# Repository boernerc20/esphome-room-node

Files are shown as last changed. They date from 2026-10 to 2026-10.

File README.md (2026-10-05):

# Jarvis Room Node

An ESP32-S3 voice assistant and room sensor for [Home Assistant](https://www.home-assistant.io/),
built on [ESPHome](https://esphome.io/). Wake word ("hey jarvis") on the device, temperature
and humidity, e-ink display, LED status ring.

**Status:** breadboard works end to end. Next: rev A PCB in KiCad.

## Repo

| Path | What |
|---|---|
| [`room-node.yaml`](room-node.yaml) | ESPHome firmware (breadboard pins) |
| [`docs/breadboard.md`](docs/breadboard.md) | Breadboard wiring |
| [`docs/pcb/pinout.md`](docs/pcb/pinout.md) | Rev A PCB pinout |
| [`docs/pcb/schematic.md`](docs/pcb/schematic.md) | Rev A schematic, sheet by sheet — draw from this |
| [`docs/pcb/layout.md`](docs/pcb/layout.md) | Rev A board (placed + routed), assembly and bring-up |
| [`docs/enclosure.md`](docs/enclosure.md) | Enclosure notes |
| `kicad/room-node/` | KiCad project |
| `reports/bom/rev-a-bom-lcsc.csv` | Rev A BOM with LCSC numbers |
| `models/` | Wake word model |

## Flash

1. Copy `secrets.yaml.example` to `secrets.yaml` and fill it in. Git ignores it.
2. `esphome run room-node.yaml` — USB the first time, then OTA (192.168.1.50).
3. Home Assistant finds the node. Assign an Assist pipeline under **Settings → Voice assistants**.

Built by [Chris Boerner](https://boernerc20.me).

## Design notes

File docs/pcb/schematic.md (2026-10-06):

# Rev A schematic — draw from this

One section per KiCad sheet in `kicad/room-node/`. Each section lists the parts and
every connection. Use the net names as global labels. Pin map: [`pinout.md`](pinout.md).
Part numbers and LCSC: [`../../reports/bom/rev-a-bom-lcsc.csv`](../../reports/bom/rev-a-bom-lcsc.csv).

**Status (2026-10-01, SQU-27):** all 6 sheets are drawn from this doc and included in
the root sheet `room-node.kicad_sch`. Project ERC: 0 errors, 1 explained warning
([`reports/schematic/`](../../reports/schematic/)). The netlist matches `pinout.md`
(`python3 tools/check_pinout.py`). The earlier MCU sheet (2xx refs, wiring errors) was
redrawn from scratch. Chris reviews and tidies.

**2026-10-02 (SQU-29):** status LED D1 + R12 on GPIO2 added to the MCU sheet.

**2026-10-05 (SQU-17):** voice button SW3 + R5 removed (wake word only). U1 pin 31
(GPIO38) is now not connected.

**Refs:** the schematic uses the refs in this doc (R1, C1, U1 …). Net names are the
ones in this doc (`+3V3`, `EN`).

**Rules for all sheets**
- Passives are 0603 minimum (hand assembly). No 0402.
- Every IC gets 0.1 µF at its supply pin.
- Board: 4 layers, solid ground plane. Assembly and layout rules: [`layout.md`](layout.md).

## Block diagram

```
USB-C 5V ──┬── ESD (D+/D−) ─────────────── U1 USB (GPIO19/20)
           ├── CC1/CC2 → 2×100k → CC_SENSE → GPIO1
           │
           +5V ──┬── LDO U2 → +3V3 ──┬── U1 ESP32-S3 module
                 │                   ├── MK1 mic (I2S in)
                 │                   ├── U6 AHT20 (I2C)
                 │                   └── J3 e-paper (SPI)
                 ├── U3 MAX98357A (I2S out) → J2 speaker
                 └── J4 LED strip (DIN ← GPIO21 via 470 Ω)

U1 GPIO2 → R12 1 kΩ → D1 status LED (green) → GND
```

---

## Sheet 1 — MCU + power + USB (`mcu.kicad_sch`)

| Ref | Value | Symbol | Footprint |
|---|---|---|---|
| U1 | ESP32-S3-WROOM-1-N16R8 | `RF_Module:ESP32-S3-WROOM-1` (set Value to N16R8) | `RF_Module:ESP32-S3-WROOM-1` |
| U2 | AP7361C-33ER-13 | `Regulator_Linear:AP1117-33` (same pinout) | `Package_TO_SOT_SMD:SOT-223-3_TabPin2` |
| U5 | USBLC6-2SC6 | `Power_Protection:USBLC6-2SC6` | `Package_TO_SOT_SMD:SOT-23-6` |
| J1 | USB4085-GF-A | `Connector:USB_C_Receptacle_USB2.0_16P` | `Connector_USB:USB_C_Receptacle_GCT_USB4085` |
| R1, R2 | 5.1 kΩ 1% | `Device:R` | 0603 |
| R3, R4 | 10 kΩ | `Device:R` | 0603 |
| R6, R7 | 100 kΩ 1% | `Device:R` | 0603 |
| C1 | 10 µF 16 V | `Device:C` | 0805 |
| C2, C5, C7, C9 | 0.1 µF | `Device:C` | 0603 |
| C3, C8 | 1 µF | `Device:C` | 0603 |
| C4, C6 | 22 µF 10 V | `Device:C` | 0805 |
| SW1, SW2 | TL3342 (RESET, BOOT) | `Switch:SW_Push` | `Button_Switch_SMD:SW_SPST_TL3342` |
| TP1–TP8 | test pad | `Connector:TestPoint` | `TestPoint:TestPoint_Pad_D1.5mm` |
| R12 | 1 kΩ | `Device:R` | 0603 |
| D1 | KT-0805G green LED | `Device:LED` | `LED_SMD:LED_0805_2012Metric` |

**USB-C (J1)**
- VBUS A4, B4, A9, B9 → `+5V`. C1 10 µF + C2 0.1 µF to GND at J1.
- GND A1, B1, A12, B12 and shield → `GND`.
- CC1 A5 → R1 5.1 kΩ → GND, and → R6 100 kΩ → `CC_SENSE`.
- CC2 B5 → R2 5.1 kΩ → GND, and → R7 100 kΩ → `CC_SENSE`.
- D+ A6 + B6 → `USB_D+_CONN`. D− A7 + B7 → `USB_D-_CONN`.
- SBU1 A8, SBU2 B8 → no connect.

**ESD (U5, USBLC6-2SC6)** — pinout checked against ST datasheet. Place at J1.

| U5 pin | Net |
|---|---|
| 1 | `USB_D-_CONN` |
| 2 | `GND` |
| 3 | `USB_D+_CONN` |
| 4 | `USB_D+` → U1 pin 14 |
| 5 | `+5V` |
| 6 | `USB_D-` → U1 pin 13 |

**CC sense** — `CC_SENSE` → U1 pin 39 (GPIO1). C9 0.1 µF to GND at U1. TP8 on the net.
R6/R7 near J1. Firmware reads the USB source current from it (about 0.2 V = 500 mA
port, 0.46 V = 1.5 A, 0.84 V = 3 A) and limits LED brightness.

**LDO (U2)** — pin 3 VIN ← `+5V`, C3 1 µF. Pin 1 → GND. Pin 2 + tab → `+3V3`,
C4 22 µF + C5 0.1 µF. Buy the **-33ER** suffix only (other suffixes have a different
pinout). Give the tab a copper pour (heat).

**Module (U1)** — pin 2 ← `+3V3`, C6 22 µF + C7 0.1 µF at the pin. Pins 1, 40, 41 → GND.
Other pins: see [`pinout.md`](pinout.md).

**Reset and boot buttons**
```
 +3V3        +3V3
  R3 10k      R4 10k
  ├─ EN       ├─ IO0
  C8 1µF      SW2 BOOT
  SW1 RESET   │
  GND         GND
```
EN = pin 3, IO0 = pin 27. SW1 and C8 both go from EN to GND. No voice button: wake
word only. Pin 31 (GPIO38) has a no-connect flag.

**Status LED (D1)** — U1 pin 38 (GPIO2) → `STATUS_LED` → R12 1 kΩ → D1 anode (pin 2);
D1 cathode (pin 1) → GND. HIGH = on.
- GPIO2 is not a strapping pin on the S3 (straps: GPIO0, 3, 45, 46). It is an input
  with no pull at reset, so D1 is off until firmware drives it.
- Current: (3.3 V − Vf) / 1 kΩ. Vf is about 2.4 V at 1 mA (typical curve) and up to
  about 2.8 V for the highest Vf bin, so **0.5–0.9 mA**. The ESP32-S3 GPIO is good for
  tens of mA, so this is no load. At 1 mA the LED gives roughly a tenth of its 20 mA
  brightness, which is plenty for an indicator in a bedroom. Firmware can dim it further with PWM (LEDC).
- **Why 0805, not 0603:** JLC has no green or blue 0603 LED in its Basic library
  (checked 2026-10-02: only red C2286 and white C2290 at 0603). KT-0805G (C2297) is the
  green Basic part. 0805 is easier to hand-solder. If you want 0603, use KT-0603G
  (C12624, Extended) and change the footprint to `LED_SMD:LED_0603_1608Metric`.
- **Polarity:** the KENTO datasheet numbers the anode pad ① ("+"); KiCad numbers the
  cathode pad 1. Do not go by pad numbers. The green corner mark on the LED is the
  cathode: place it on the cathode (pad 1) side of the footprint.
- Put D1 where it can be seen through the case (a light pipe or a thin wall).
  It is not near the antenna and not near U6.

**Test points:** TP1 EN, TP2 IO0, TP3 TXD0 (pin 37), TP4 RXD0 (pin 36), TP5 +3V3,
TP6 +5V, TP7 GND, TP8 CC_SENSE.

---

## Sheet 2 — Audio out (`audio_out.kicad_sch`)

| Ref | Value | Symbol | Footprint |
|---|---|---|---|
| U3 | MAX98357AETE+ | `Audio:MAX98357A` | `Package_DFN_QFN:TQFN-16-1EP_3x3mm_P0.5mm_EP1.23x1.23mm` |
| C20 | 470–1000 µF 16 V radial | `Device:C_Polarized` | radial THT (see BOM) |
| C21 | 0.1 µF | `Device:C` | 0603 |
| C22 | 10 µF 16 V | `Device:C` | 0805 |
| R20 | 100 kΩ | `Device:R` | 0603 |
| J2 | JST-PH 2-pin | `Connector_Generic:Conn_01x02` | `Connector_JST:JST_PH_B2B-PH-SM4-TB_1x02-1MP_P2.00mm_Vertical` |

| U3 pin | Name | Net |
|---|---|---|
| 1 | DIN | `I2S_SPK_DIN` (GPIO18) |
| 2 | GAIN_SLOT | `+5V` → **6 dB gain** (tested on the breadboard; 9 dB clips) |
| 4 | SD_MODE | `AMP_SD` (GPIO7). R20 100 kΩ to GND keeps the amp off during boot (the chip also has an internal 100 kΩ pull-down). GPIO HIGH = left channel |
| 7, 8 | VDD | `+5V`. C20, C21, C22 to GND, **at the chip** |
| 9 | OUTP | J2 pin 1 |
| 10 | OUTN | J2 pin 2 |
| 14 | LRCLK | `I2S_SPK_LRCLK` (GPIO16) |
| 16 | BCLK | `I2S_SPK_BCLK` (GPIO17) |
| 3, 11, 15, 17 (EP) | GND | `GND`. EP is pin 17 (`PAD`) on the stock symbol; it is not connected inside the chip, so wire it. Vias in the pad |
| 5, 6, 12, 13 | NC | no connect |

Speaker: Dayton CE32A-8 (8 Ω) on J2. Do not connect either speaker wire to GND.
C20 + C21 + the star ground removed the breadboard crackle. Keep all three.

---

## Sheet 3 — Microphone (`microphone.kicad_sch`)

Use the **stock** symbol `Sensor_Audio:SPH0645LM4H` and footprint
`Sensor_Audio:Knowles_SPH0645LM4H-6_3.5x2.65mm`. The SPH0645 that was in the project
library (wrong pin numbers, no sound hole) was removed in SQU-27.

| Ref | Value | Footprint |
|---|---|---|
| MK1 | SPH0645LM4H-B | stock (above) |
| R8 | 100 kΩ | 0603 |
| R9, R10, R11 | 33 Ω | 0603 |
| C10 | 0.1 µF | 0603 |
| C11 | 100 pF C0G, **DNP** (do not fit) | 0603 |

| MK1 pin | Name | Connection |
|---|---|---|
| 1 | WS | → R10 33 Ω → `I2S_MIC_WS` (GPIO5). R10 at U1 |
| 2 | SELECT | GND (left channel) |
| 3 | GND | GND (ring around the sound hole) |
| 4 | BCLK | → R9 33 Ω → `I2S_MIC_BCLK` (GPIO4). R9 at U1 |
| 5 | VDD | `+3V3`. C10 0.1 µF + C11 100 pF to GND, at the pin |
| 6 | DATA | → R11 33 Ω → `I2S_MIC_DATA` (GPIO6). R11 at MK1. R8 100 kΩ from `I2S_MIC_DATA` to GND |

The 33 Ω parts are optional damping. If you remove them, use 0 Ω or a wire.
Mic mute is software only. There is no mute switch.

---

## Sheet 4 — LED ring (`led_ring.kicad_sch`)

| Ref | Value | Footprint |
|---|---|---|
| R30 | 470 Ω | 0603 |
| C30 | 1000 µF 16 V radial | radial THT (see BOM) |
| J4 | 3-pin connector to the strip | `Connector_JST:JST_XH_S3B-XH-A_1x03_P2.50mm_Horizontal`: JST S3B-XH-A(LF)(SN), side entry, LCSC C157928 (3 A; full white is ~1.6 A). Side entry since SQU-42: the cable leaves flat out of the bottom edge |

- `LED_DIN` (GPIO21) → R30 470 Ω → J4 pin 2 (DIN). R30 near U1.
- J4 pin 1 → `+5V`. J4 pin 3 → `GND`. C30 across pins 1 and 3, at J4.
- No level shifter (works on the breadboard). If the strip flickers on rev A, rev B adds a 74AHCT125.
- Strip: 27 × WS2812B, off-board.

---

## Sheet 5 — Sensor (`sensors.kicad_sch`)

| Ref | Value | Footprint |
|---|---|---|
| U6 | AHT20 | `room-node:AHT20`, 3 × 3 mm DFN-6, 1.0 mm pitch (LCSC C2757850) |
| R40, R41 | 4.7 kΩ | 0603 |
| C40 | 0.1 µF | 0603 |

The project-library AHT20 was wrong (4 pins, 4 invented pads). It is now replaced
(SQU-27) with a 6-pin symbol and a 6-pad footprint made from the LCSC C2757850 import,
pin 1 top-left as in the Aosong datasheet v1.1 §3. Pins 1 and 6 are no-connect pins.

| U6 pin | Name | Net |
|---|---|---|
| 1 | NC | no connect |
| 2 | VDD | `+3V3`, C40 0.1 µF to GND at the pin |
| 3 | SCL | `I2C_SCL` (GPIO9), R41 4.7 kΩ to `+3V3` |
| 4 | SDA | `I2C_SDA` (GPIO8), R40 4.7 kΩ to `+3V3` |
| 5 | GND | `GND` |
| 6 | NC | no connect |

- I2C address 0x38.
- Source: Aosong AHT20 datasheet v1.1, §3 pin diagram (top view).
- Place U6 on a board edge, far from U1, U2, U3 and J4, with slots on three sides
  (heat from the board reads as room temperature).

---

## Sheet 6 — Display (`display.kicad_sch`)

Rev A plugs in the same Waveshare 2.9" e-paper module as the breadboard, with its
own driver board, through its cable. (A bare panel on an FPC needs an extra boost
circuit; not for rev A.)

| Ref | Value | Footprint |
|---|---|---|
| J3 | 8-pin JST-PH **side entry** (Waveshare cable) | `Connector_JST:JST_PH_S8B-PH-SM4-TB_1x08-1MP_P2.00mm_Horizontal` |
| C50 | 0.1 µF | 0603 |

| J3 pin | Waveshare name | Net |
|---|---|---|
| 1 | VCC | `+3V3` (C50 to GND at J3) |
| 2 | GND | `GND` |
| 3 | DIN | `EPD_MOSI` (GPIO11) |
| 4 | CLK | `EPD_CLK` (GPIO12) |
| 5 | CS | `EPD_CS` (GPIO10) |
| 6 | DC | `EPD_DC` (GPIO13) |
| 7 | RST | `EPD_RST` (GPIO14) |
| 8 | BUSY | `EPD_BUSY` (GPIO15) |

**Side entry (Chris, 2026-10-05, SQU-32).** J3 is the horizontal **S8B-PH-SM4-TB**, not the
top-entry B8B. The board sits on ~10 mm M2 standoffs behind the display, parts side facing
away from it, so the cable has to leave the board edge towards the display. Pinout and pin
numbering are unchanged: pin 1 is still pin 1.

**Edge (Chris, 2026-10-05, SQU-35).** The connector mouth faces out over the **right**
board edge (looking at the parts side with USB-C on the left), not the bottom edge. Pin 1
is the **lower** of the eight pads and is marked with a filled triangle on the silkscreen.
The LED connector J4 moved to the left edge just below USB-C at the same time; see
`docs/pcb/layout.md`.

⚠ Check the pin order and pin count on your cable. Newer Waveshare modules have a
9th pin (PWR); if yours has it, use a 9-pin connector and tie PWR to `+3V3`.

⚠ **Cable.** The breadboard cable has a PH plug only at the module end; the other end
is loose jumper wires. For J3 as drawn you need a PH-to-PH 8-pin cable that maps
pin 1 to pin 1 (some ready-made cables reverse it: beep it out before power-on).
The other option is a 1×8 2.54 mm pin header (`Connector_PinHeader_2.54mm:PinHeader_1x08_P2.54mm_Vertical`)
that takes the existing jumper ends. Same pin order either way.

---

## Global labels (checklist)

- [ ] `+5V`, `+3V3`, `GND`
- [ ] `USB_D+`, `USB_D-`, `USB_D+_CONN`, `USB_D-_CONN`, `CC1`, `CC2`, `CC_SENSE`
- [ ] `EN`, `IO0`, `TXD0`, `RXD0`, `STATUS_LED`
- [ ] `I2S_MIC_BCLK`, `I2S_MIC_WS`, `I2S_MIC_DATA`
- [ ] `I2S_SPK_BCLK`, `I2S_SPK_LRCLK`, `I2S_SPK_DIN`, `AMP_SD`
- [ ] `I2C_SDA`, `I2C_SCL`
- [ ] `EPD_CLK`, `EPD_MOSI`, `EPD_CS`, `EPD_DC`, `EPD_RST`, `EPD_BUSY`
- [ ] `LED_DIN`

## Datasheets

ESP32-S3-WROOM-1 and ESP32-S3 Hardware Design Guidelines (Espressif), AP7361C (Diodes),
USBLC6-2 (ST), MAX98357A (Analog Devices), SPH0645LM4H-B (Knowles, DigiKey mirror),
AHT20 (Aosong), KT-0805G LED (Hubei KENTO, rev A.0, 2018-12-06), USB Type-C spec R2.0 §4.11.3 (CC voltages).

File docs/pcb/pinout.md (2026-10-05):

# Rev A pinout — ESP32-S3-WROOM-1-N16R8 (U1)

One row per module pin. **Pin** = module pin number on the KiCad symbol
`RF_Module:ESP32-S3-WROOM-1` (verified). **GPIO** = the ESP32 GPIO number. They are
two different numbers; always check which one you read.

The breadboard uses the same GPIOs (see [`../breadboard.md`](../breadboard.md)).
The PCB has no voice button (wake word only); the BOOT button on GPIO0 can still
start the voice assistant, same as on the breadboard.

## Used pins

| Pin | GPIO | Net (global label) | Goes to | Sheet |
|---|---|---|---|---|
| 1, 40, 41 | — | `GND` | ground plane, via array under the pad | MCU |
| 2 | — | `+3V3` | LDO output | MCU |
| 3 | EN | `EN` | 10 kΩ pull-up, 1 µF to GND, RESET button | MCU |
| 4 | 4 | `I2S_MIC_BCLK` | mic BCLK (through 33 Ω) | Mic |
| 5 | 5 | `I2S_MIC_WS` | mic WS (through 33 Ω) | Mic |
| 6 | 6 | `I2S_MIC_DATA` | mic DATA (through 33 Ω), 100 kΩ to GND | Mic |
| 7 | 7 | `AMP_SD` | amp SD_MODE. HIGH = on, LOW = off | Audio |
| 8 | 15 | `EPD_BUSY` | e-paper BUSY (input) | Display |
| 9 | 16 | `I2S_SPK_LRCLK` | amp LRCLK | Audio |
| 10 | 17 | `I2S_SPK_BCLK` | amp BCLK | Audio |
| 11 | 18 | `I2S_SPK_DIN` | amp DIN | Audio |
| 12 | 8 | `I2C_SDA` | AHT20 SDA, 4.7 kΩ pull-up | Sensor |
| 13 | 19 | `USB_D-` | USB-C D− (through ESD U5) | MCU |
| 14 | 20 | `USB_D+` | USB-C D+ (through ESD U5) | MCU |
| 17 | 9 | `I2C_SCL` | AHT20 SCL, 4.7 kΩ pull-up | Sensor |
| 18 | 10 | `EPD_CS` | e-paper CS | Display |
| 19 | 11 | `EPD_MOSI` | e-paper DIN | Display |
| 20 | 12 | `EPD_CLK` | e-paper CLK | Display |
| 21 | 13 | `EPD_DC` | e-paper DC | Display |
| 22 | 14 | `EPD_RST` | e-paper RST | Display |
| 23 | 21 | `LED_DIN` | LED strip DIN (through 470 Ω) | LED |
| 27 | 0 | `IO0` | BOOT button, 10 kΩ pull-up. ⚠ strapping pin | MCU |
| 36 | 44 (RXD0) | `RXD0` | test point | MCU |
| 37 | 43 (TXD0) | `TXD0` | test point | MCU |
| 38 | 2 | `STATUS_LED` | status LED D1 through R12 1 kΩ. HIGH = on | MCU |
| 39 | 1 | `CC_SENSE` | USB-C CC sense (analog, ADC1_CH0) | MCU |

## Do not use

| Pin | GPIO | Why |
|---|---|---|
| 15, 16, 26 | 3, 46, 45 | Strapping pins. Leave not connected. |
| 28, 29, 30 | 35, 36, 37 | Used inside the module by the octal PSRAM. |
| — | 26–32 | Flash. Not on the module pins. |

## Free (spare)

| Pin | GPIO | Note |
|---|---|---|
| 31 | 38 | Was the voice button (removed 2026-10-05, wake word only). |
| 32–35 | 39–42 | JTAG. Keep free if you want hardware debug. |
| 24, 25 | 47, 48 | No ADC. |

Leave free pins not connected. There is no free ADC1 pin left (GPIO1 = CC sense,
GPIO2 = status LED).

## Why GPIO2 for the status LED

GPIO2 is not a strapping pin on the ESP32-S3 (the straps are GPIO0, 3, 45 and 46;
ESP32-S3 datasheet, "Strapping Pins"). It is an input with no pull at reset, so the
LED stays off until firmware drives it. (On the older ESP32, GPIO2 *is* a strap; not
on the S3.) The LED takes about 0.5–0.9 mA, far below the GPIO drive limit. The cost:
GPIO2 was the last free ADC1 pin.

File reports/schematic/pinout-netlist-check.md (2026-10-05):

## 1. U1 used pins (pinout.md) vs netlist

| U1 pin | GPIO | pinout.md net | netlist net | Also on this net | OK |
|---|---|---|---|---|---|
| 1 | — | `GND` | `GND` | 41 pins | ✅ |
| 2 | — | `+3V3` | `+3V3` | 17 pins | ✅ |
| 3 | EN | `EN` | `EN` | C8.1, R3.2, SW1.2, TP1.1 | ✅ |
| 4 | 4 | `I2S_MIC_BCLK` | `I2S_MIC_BCLK` | R9.2 | ✅ |
| 5 | 5 | `I2S_MIC_WS` | `I2S_MIC_WS` | R10.2 | ✅ |
| 6 | 6 | `I2S_MIC_DATA` | `I2S_MIC_DATA` | R11.2, R8.1 | ✅ |
| 7 | 7 | `AMP_SD` | `AMP_SD` | R20.1, U3.4 | ✅ |
| 8 | 15 | `EPD_BUSY` | `EPD_BUSY` | J3.8 | ✅ |
| 9 | 16 | `I2S_SPK_LRCLK` | `I2S_SPK_LRCLK` | U3.14 | ✅ |
| 10 | 17 | `I2S_SPK_BCLK` | `I2S_SPK_BCLK` | U3.16 | ✅ |
| 11 | 18 | `I2S_SPK_DIN` | `I2S_SPK_DIN` | U3.1 | ✅ |
| 12 | 8 | `I2C_SDA` | `I2C_SDA` | R40.2, U6.4 | ✅ |
| 13 | 19 | `USB_D-` | `USB_D-` | U5.6 | ✅ |
| 14 | 20 | `USB_D+` | `USB_D+` | U5.4 | ✅ |
| 17 | 9 | `I2C_SCL` | `I2C_SCL` | R41.2, U6.3 | ✅ |
| 18 | 10 | `EPD_CS` | `EPD_CS` | J3.5 | ✅ |
| 19 | 11 | `EPD_MOSI` | `EPD_MOSI` | J3.3 | ✅ |
| 20 | 12 | `EPD_CLK` | `EPD_CLK` | J3.4 | ✅ |
| 21 | 13 | `EPD_DC` | `EPD_DC` | J3.6 | ✅ |
| 22 | 14 | `EPD_RST` | `EPD_RST` | J3.7 | ✅ |
| 23 | 21 | `LED_DIN` | `LED_DIN` | R30.1 | ✅ |
| 27 | 0 | `IO0` | `IO0` | R4.2, SW2.2, TP2.1 | ✅ |
| 36 | 44 (RXD0) | `RXD0` | `RXD0` | TP4.1 | ✅ |
| 37 | 43 (TXD0) | `TXD0` | `TXD0` | TP3.1 | ✅ |
| 38 | 2 | `STATUS_LED` | `STATUS_LED` | R12.1 | ✅ |
| 39 | 1 | `CC_SENSE` | `CC_SENSE` | C9.1, R6.2, R7.2, TP8.1 | ✅ |
| 40 | — | `GND` | `GND` | 41 pins | ✅ |
| 41 | — | `GND` | `GND` | 41 pins | ✅ |

## 2. U1 pins that must stay not connected

| U1 pin | GPIO | Why | Netlist | OK |
|---|---|---|---|---|
| 15 | 3 | Do not use | not connected | ✅ |
| 16 | 46 | Do not use | not connected | ✅ |
| 24 | 47 | Free (spare) | not connected | ✅ |
| 25 | 48 | Free (spare) | not connected | ✅ |
| 26 | 45 | Do not use | not connected | ✅ |
| 28 | 35 | Do not use | not connected | ✅ |
| 29 | 36 | Do not use | not connected | ✅ |
| 30 | 37 | Do not use | not connected | ✅ |
| 31 | 38 | Free (spare) | not connected | ✅ |
| 32 | 39 | Free (spare) | not connected | ✅ |
| 33 | 40 | Free (spare) | not connected | ✅ |
| 34 | 41 | Free (spare) | not connected | ✅ |
| 35 | 42 | Free (spare) | not connected | ✅ |

**U1 pins connected but not in pinout.md:** none

## 3. Other end of each net (schematic.md)

| Net | Expected pins | Result |
|---|---|---|
| `EN` | U1.3, R3.2, C8.1, SW1.2, TP1.1 | ✅ |
| `IO0` | U1.27, R4.2, SW2.2, TP2.1 | ✅ |
| `TXD0` | U1.37, TP3.1 | ✅ |
| `RXD0` | U1.36, TP4.1 | ✅ |
| `CC1` | J1.A5, R1.1, R6.1 | ✅ |
| `CC2` | J1.B5, R2.1, R7.1 | ✅ |
| `CC_SENSE` | U1.39, R6.2, R7.2, C9.1, TP8.1 | ✅ |
| `USB_D+_CONN` | J1.A6, J1.B6, U5.3 | ✅ |
| `USB_D-_CONN` | J1.A7, J1.B7, U5.1 | ✅ |
| `USB_D+` | U1.14, U5.4 | ✅ |
| `USB_D-` | U1.13, U5.6 | ✅ |
| `I2S_MIC_BCLK` | U1.4, R9.2 | ✅ |
| `I2S_MIC_WS` | U1.5, R10.2 | ✅ |
| `I2S_MIC_DATA` | U1.6, R11.2, R8.1 | ✅ |
| `I2S_SPK_LRCLK` | U1.9, U3.14 | ✅ |
| `I2S_SPK_BCLK` | U1.10, U3.16 | ✅ |
| `I2S_SPK_DIN` | U1.11, U3.1 | ✅ |
| `AMP_SD` | U1.7, U3.4, R20.1 | ✅ |
| `I2C_SDA` | U1.12, U6.4, R40.2 | ✅ |
| `I2C_SCL` | U1.17, U6.3, R41.2 | ✅ |
| `EPD_CS` | U1.18, J3.5 | ✅ |
| `EPD_MOSI` | U1.19, J3.3 | ✅ |
| `EPD_CLK` | U1.20, J3.4 | ✅ |
| `EPD_DC` | U1.21, J3.6 | ✅ |
| `EPD_RST` | U1.22, J3.7 | ✅ |
| `EPD_BUSY` | U1.8, J3.8 | ✅ |
| `LED_DIN` | U1.23, R30.1 | ✅ |
| `STATUS_LED` | U1.38, R12.1 | ✅ |
| `+5V` | 18 pins | ✅ |
| `+3V3` | 18 pins | ✅ |
| `GND` | 29 pins | ✅ |
| (series) | MK1.1 = R10.1 | ✅ |
| (series) | MK1.4 = R9.1 | ✅ |
| (series) | MK1.6 = R11.1 | ✅ |
| (series) | R30.2 = J4.2 | ✅ |
| (series) | R12.2 = D1.2 | ✅ |
| (series) | U3.9 = J2.1 | ✅ |
| (series) | U3.10 = J2.2 | ✅ |
| (NC) | J1.A8 | ✅ |
| (NC) | J1.B8 | ✅ |
| (NC) | U6.1 | ✅ |
| (NC) | U6.6 | ✅ |
| (NC) | U3.5 | ✅ |
| (NC) | U3.6 | ✅ |
| (NC) | U3.12 | ✅ |
| (NC) | U3.13 | ✅ |

**Result: PASS**

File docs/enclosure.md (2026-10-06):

# Enclosure notes (3D print)

- **Display window:** cut to the active area, 66.9 × 29.1 mm (module is 89.5 × 38 × 4.7 mm).
- **LED ring:** 27 px around the display. Cover with a translucent diffuser (PETG, 1.5–2 mm wall).
- **Speaker (Dayton CE32A-8):** cutout 31.5 mm, frame 32 mm, depth 14.5 mm.
  Sealed back chamber of 20–30 cc with some poly stuffing. Seal the cone to the front wall.
- **Mic (PCB):** bottom port. Bring a sealed path (gasket or foam ring) from a case
  opening to the hole under the mic on the **bottom** of the PCB.
- **Isolation:** keep the mic away from the speaker, with foam between them. There is no
  echo cancellation, so speaker sound in the mic can trigger the wake word.
- **Sensor:** put a vent above the AHT20, away from warm parts.
- **Cable exits (rev A board at dc89150, 2026-10-06).** Looking at the parts side with USB-C on the left:
  - **Left edge:** USB-C (J1) needs its own opening.
  - **Bottom edge:** the LED strip connector (J4, side-entry JST S3B-XH-A) faces
    outward. Provide a nominal 10 mm wide slot in the bottom wall, centred on
    PCB x = 126.5 mm (J4 pin 2). The housing spans x = 121.5–131.5 mm and its
    front face is at y = 137.7 mm, 0.3 mm inside the PCB edge (y = 138.0 mm).
    The mating plug and cable extend beyond that edge. **Open question:** final
    slot height, wall clearance and cable bend space need a physical fit check.
  - **Right edge:** the display cable (J3, side entry, mouth flush with the edge). It
    runs straight out of the right edge into the gap behind the display.
  - **Bottom-right:** the speaker plug (J2, vertical, cable exits upward).
  - The mic opening stays at the **bottom-left** corner; J4's courtyard is 12.5 mm
    to its right.
  - The antenna still overhangs the **top** edge by about 6 mm: no metal in front of it.

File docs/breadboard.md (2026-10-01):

# Breadboard wiring (as built, confirmed 2026-09-30)

Pins match [`../room-node.yaml`](../room-node.yaml). Power: 5 V USB into the dev board.

| Part | Wiring |
|---|---|
| ESP32-S3 dev board, N16R8 | 5 V USB in |
| Adafruit SPH0645 breakout (mic) | BCLK→GPIO4, LRCL→GPIO5, DOUT→GPIO6, SEL→GND, 3V→3V3 |
| MAX98357A breakout (amp) | BCLK→GPIO17, LRC→GPIO16, DIN→GPIO18, SD→GPIO7, GAIN→VIN (6 dB), VIN→5V. 470–1000 µF + 0.1 µF across VIN/GND at the amp |
| Dayton CE32A-8 speaker | amp + and −. Do not ground either wire |
| AHT20 breakout | SDA→GPIO8, SCL→GPIO9, VCC→3V3 (breakout has pull-ups) |
| Waveshare 2.9" e-paper v2 | CLK→GPIO12, DIN→GPIO11, CS→GPIO10, DC→GPIO13, RST→GPIO14, BUSY→GPIO15, VCC→3V3 |
| WS2812B strip, 27 px | GPIO21 → 330–470 Ω → DIN. 5V, GND. 1000 µF across 5V/GND at the strip |
| Voice button | GPIO0 to GND (the dev board BOOT button does the same) |

**Ground:** star. Amp GND and LED GND each go on their own wire to GND at the 5 V input.

**Audio:** keep GAIN→VIN (6 dB). 9 dB is louder but clips and cuts out on 5 V.
Firmware `volume_multiplier: 1.0` is the loudest clean setting. A sealed box behind
the speaker gives the biggest gain.

**Mic mute:** software switch "Mic muted" in Home Assistant.

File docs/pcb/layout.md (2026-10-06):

# Rev A layout, assembly and bring-up

For later, when the schematic is done. Rev A is 5 boards, built by hand.

## Board

- 4 layers, solid ground plane. ENIG finish. No stencil (Chris, SQU-45, 2026-10-06).
- All parts on the top side. 0603 minimum. At least 0.5 mm between passives.
- Tent the vias under the module pad and the amp pad.
- Readable silkscreen: pin 1 marks, polarity marks, refs.

## Stack-up and design rules (JLCPCB 4-layer)

Stack-up: **JLC04161H-7628**, 1.6 mm, 1 oz outer / 0.5 oz inner.
L1 signals + parts, L2 GND plane, L3 +3V3 plane, L4 signals + +5V trunk.

The 4 copper layers are set in `room-node.kicad_pcb`. The DRC rules below are already in `room-node.kicad_pro` (Board Setup → Design Rules).

| Rule | Value |
|---|---|
| Min track / clearance | 0.1 / 0.1 mm |
| Min via | 0.45 mm pad / 0.2 mm drill (0.3 mm drill and up: no extra cost) |
| Min through-hole drill | 0.2 mm |
| Hole to hole / hole to copper | 0.25 / 0.2 mm |
| Copper to board edge | 0.3 mm |
| Silkscreen text | 0.8 mm high, 0.15 mm line |

| Net class | Nets | Track | Clearance | Via |
|---|---|---|---|---|
| Default | all others | 0.2 | 0.15 | 0.6 / 0.3 |
| Power | +5V, +3V3, GND | 0.6 | 0.15 (USB-C J1 pads are 0.15 apart) | 0.8 / 0.4 |
| Audio | speaker out (J2) | 0.4 | 0.2 | 0.8 / 0.4 |
| USB | USB_D± | 0.2, diff gap 0.15 (~90 Ω on L1 over L2) | 0.15 | 0.6 / 0.3 |
| LED | LED_DIN, J4 data | 0.2 | 0.15 | 0.6 / 0.3 |

The Audio and LED patterns use KiCad's auto net names (`Net-(J2-Pin_*)`, `Net-(J4-Pin_2)`).
If you rename those nets in the schematic, update the pattern in Board Setup → Net Classes.

## Rev A board (placed and routed; connectors moved to the edges 2026-10-05, SQU-35; re-review fixes 2026-10-06, SQU-38; J1 centred and J4 to the bottom edge 2026-10-06, SQU-39; J4 side entry 2026-10-06, SQU-42)

`tools/pcb_build.py` builds the whole board: outline, holes, slots, parts, planes,
placement, rule areas, hand-made routes (J1 VBUS, the whole +5V net, the J1 → U5 USB
pair, amp pins, the C6 → U1 pin 2 link, the LDO tab copper, the sensor island) and plane
fan-out vias. Only signals are left to Freerouting 2.4.1 (needs Java 25, not in the
container by default; SQU-39 used Eclipse Temurin 25 from adoptium.net in a scratch
directory). The router is not deterministic: a rebuild gives different signal tracks,
so re-running the pipeline means re-running the checks and the reports with it.

```
kicadpython tools/pcb_build.py place out.dsn     # overwrites room-node.kicad_pcb
java -jar freerouting-2.4.1.jar -de out.dsn -do out.ses -mp 100 --gui.enabled=false
kicadpython tools/pcb_build.py route out.ses     # import, widen +5V, GND fills, stitching
kicad-cli pcb drc --severity-all --format report -o drc.rpt kicad/room-node/room-node.kicad_pcb
kicadpython tools/pcb_silk.py drc.rpt            # repeat drc + silk until the count settles
kicadpython tools/pcb_audit.py                   # the measurements quoted below
```

Reports (`reports/`) are regenerated from the same board:

```
kicad-cli pcb drc --severity-all --format report -o reports/pcb/room-node-drc.rpt  <board>
kicad-cli sch erc --severity-all --format report -o reports/schematic/room-node-rev-a-erc.rpt <sch>
python3 tools/check_pinout.py > reports/schematic/pinout-netlist-check.md
kicadpython tools/pcb_png.py F.Cu reports/pcb/room-node-copper-top.png     # and B.Cu
kicad-cli pcb render --side top --width 4000 --height 1800 --background transparent \
    --quality high -o top.png <board>            # crop to the alpha bbox, scale to 1799 px
kicad-cli pcb export gerbers --output gerb/ \
    --layers "F.Cu,In1.Cu,In2.Cu,B.Cu,F.Mask,B.Mask,F.Silkscreen,B.Silkscreen,F.Paste,Edge.Cuts" <board>
kicad-cli pcb export drill --output gerb/ --format excellon --excellon-separate-th \
    --excellon-units mm <board>                  # zip gerb/ -> reports/fab/...-gerbers.zip
```

The design-review fixes live in the generator, not in one-shot patch scripts, so a
rebuild cannot lose them: M1 (C21/C22 at U3 pins 7/8), M3 (LDO tab copper area, its vias
and their drills), M4, the SQU-32 items (C6 rotated with a direct track to U1 pin 2,
CC_SENSE kept away from the antenna end, the mic-hole gasket seat, the island neck slot,
the necked +5V feed at U3 pins 7/8, the +5V widths) and the SQU-38 items (J3 0.10 mm in,
the 1.50 mm +5V inlet, `fix_tab_vias()`).

Two one-shot patch scripts are kept as history and **must not be re-run**:
`tools/pcb_squ32.py` (superseded entirely by the generator) and `tools/pcb_squ38.py`.
The second exists because Freerouting needs Java 25, which is not in the container, so
the committed board could not be rebuilt end to end when the SQU-37 review came back;
its three coordinate-exact edits are the same geometry the generator now produces.

**SQU-39 rebuild.** The whole pipeline above was re-run end to end for SQU-39, so the
signal routes are a fresh Freerouting result: the EPD lengths below changed with it.
`tools/pcb_squ38.py` is now fully superseded as well.

**Mounting.** Same outline and holes as the Waveshare 2.9" e-paper module
(Waveshare drawing: 89.5 × 38.0 mm, holes 2.5 mm from each edge, 84.5 × 33.0 mm pattern).
4 × M2 holes (2.2 mm, H1–H4). The board sits behind the display on M2 standoffs.
The bottom side (no parts) faces the display. All parts face the back of the case.

- **Standoffs:** the display's driver board has parts and its 8-pin connector on its back.
  Use standoffs tall enough to clear the plug: about 10 mm.
- **U1 antenna** overhangs the top edge, so it sticks out past the display outline by
  about 6 mm. The case must leave room for it. No metal in front of it.

### Connectors at the edges (SQU-35)

Chris's rule: the cables have to be short when the board sits behind the display, so
each connector sits on the edge nearest what it plugs into. Frame of reference as
everywhere in this file: **looking at the parts side, USB-C on the left**.

| Connector | Edge | Position | Cable |
|---|---|---|---|
| J1 USB-C | left, **centred** (SQU-39) | (109.155, **116.025**) rot −90 (footprint origin = pin A1). Pin field A1–A12 y 116.025–121.975 and courtyard y 113.68–124.32 are both centred on **y = 119.000**, the board centre; it was 113.5 (origin 110.525) | out of the left edge |
| J4 LED strip (S3B-XH-A, **side entry**, SQU-42) | **bottom**, under U1, left of the AHT20 island (SQU-39) | (124.000, **128.450**) rot 0; pin 1 +5V at x = 124.0, pin 2 data 126.5, pin 3 GND 129.0; mouth facing the bottom edge | straight out of the bottom edge |
| J3 display (S8B-PH-SM4-TB, side entry) | right | (184.500, 117.500) rot 90; pad row at x = 181.65, pin 1 (181.65, **124.50**) at the bottom, pin 8 at 110.50 | straight out of the right edge |
| J2 speaker (B2B-PH-SM4-TB) | bottom right | (176.300, 133.000), clear of J3 | up |

- **J3** faces out over the right edge. Its mounting-tab pads reach x = 189.10 against
  the edge at x = 189.50: **0.40 mm** of copper-to-edge margin (SQU-38 item 1; it was
  189.20 / 0.30 mm, which is the DRC limit but not a safe milling margin — JLCPCB's
  routing tolerance is ±0.20 mm, so 0.30 mm nominal can finish at 0.10 mm). The housing
  front face sits at x = 188.95, 0.55 mm inside the edge, so the cable still leaves
  straight out over the right edge; only the overhanging courtyard got 0.10 mm shorter.
  The courtyard spans y 106.86–128.15, which keeps J3 4.36 mm clear of H2 and 7.35 mm
  clear of H4. Use a short PH-to-PH 8-pin cable, pin 1 to pin 1 (see the display sheet
  notes in `schematic.md`).
- **J3 pin 1** is hidden under the side-entry housing, so it is marked with a filled
  silkscreen triangle on the board side of the pad row, tip at (179.60, 124.50),
  0.30 mm from pin 1's pad edge and pointing at it.
- **J4 side entry (SQU-42, Chris).** J4 is now the right-angle THT XH header
  S3B-XH-A (`Connector_JST:JST_XH_S3B-XH-A_1x03_P2.50mm_Horizontal`, 3 A, LCSC C157928),
  mouth facing the bottom edge, so the plug goes in from the edge and the cable leaves
  flat, straight out of the bottom edge. The housing is 11.6 mm deep and its front face
  sits 9.25 mm in front of the pin row, so the pins are at y = 128.45: housing x
  121.50–131.50, y 126.10–**137.70**, i.e. the front face is **0.30 mm inside** the edge
  (y = 138.00); **no body overhang**. The footprint silk ends at y = 137.82, 0.18 mm off
  the edge (no new silk warning). Only the courtyard crosses the edge, by 0.15 mm
  (line centre; y 125.64–138.15, x 121.00–132.00; 0.175 mm with the line width, SQU-45). The plug itself sticks out past the edge, so the
  case needs a slot in the bottom wall about 10 mm wide centred on x = 126.5 (pin 2).
  Pad copper is **8.58 mm** from the edge (pad centre 9.55 mm; SQU-45 corrected the
  earlier "3.55 mm").
- **C30 at J4.** C30 (1000 µF) did not move: (118.0, 132.2) rot 180, + pad facing J4,
  courtyards **0.21 mm** apart. C30 + pad → J4 pin 1 is now **7.08 mm** (was 6.16 mm; J4's
  pins moved 5.15 mm towards U1). Measured on the board (SQU-45; the earlier "0.31 mm"
  was wrong): can outline (F.Fab, Ø 10.0 mm, centre (115.5, 132.2)) **0.80 mm** inside the
  bottom edge, courtyard (r 5.25) **0.55 mm**, pad copper **4.80 mm**. A real can up to
  Ø 10.5 mm still clears the edge by 0.55 mm. Chris confirmed the case clears it
  (SQU-17, 2026-10-06).
- **J4 to the AHT20 (SQU-39 constraint, ≥ ~15 mm), unchanged by SQU-42.** J4 courtyard →
  U6 courtyard **18.81 mm**; J4 courtyard → the island's left slot (x = 147.60)
  **15.60 mm**; nearest J4 pad → U6 centre 24.49 mm; J4 pin 1 (+5V) → U6 centre 29.34 mm.
- **Mic sound hole** stays at (108.500, 135.510) in the bottom-left corner, as does its
  case opening. Nothing had to move it: J4's courtyard is **12.50 mm** to the right of it
  (SQU-39), and the C30 can sits between the two. No **via** is within 2.00 mm of the hole on any layer, enforced by
  the "MK1 gasket seat" rule area (2.5 mm radius). It is a no-via rule, not a no-copper
  rule: tracks and the GND / +3V3 pours still run through it, which is what keeps the
  planes solid round the mic. The no-copper ring is the separate 0.4 mm
  "MK1 sound hole" keep-out inside the footprint's GND ring.

### Bottom edge: board separation and assembly (SQU-45)

Rev A is 5 boards built by hand (top of this file), so JLCPCB's assembly rule
("the body of the components and the edge of the board must be equal or greater than
2.5 mm", [assembly terms](https://jlcpcb.com/help/article/terms-and-conditions-of-jlcpcb-assembly-service))
does not apply to it. It would apply only if Rev A were ordered **with JLC assembly**.
How the boards are separated still matters, so the method is written down here.
**Chris decides the method (via Oscar); nothing has been ordered or uploaded.**

**Every edge has something on it**, not just the bottom one. Measured on the board
(edge at x 100.0 / 189.5, y 100.0 / 138.0; "body" = F.Fab outline):

| Edge | Part | Body to edge | Courtyard | Copper to edge |
|---|---|---|---|---|
| bottom | **J4** S3B-XH-A (THT) | **0.30** | −0.15 (crosses) | pads **8.58** |
| bottom | **C30** 1000 µF (THT) | **0.80** | 0.55 | pads **4.80** |
| bottom | C20 470 µF (THT) | 1.35 | 1.12 | pads 4.60 |
| bottom | U6 AHT20 | 1.45 | 1.22 | pads 1.75 |
| bottom | MK1 mic | 1.40 | 1.18 | pads 1.68 |
| bottom | J2 speaker (PH SMD) | 4.20 | 1.22 | tab pads 1.75 |
| bottom | C40 | 2.15 | 1.50 | pads 1.78 |
| bottom | H3 / H4 (M2, Waveshare pattern) | – | – | pad ring 1.40 |
| top | U1 antenna | **overhangs 6.05** | – | pads 1.04 |
| left | J1 USB-C | 0.50 | 0.02 | pads 3.94 |
| right | J3 display (side entry) | 0.55 | −0.12 (crosses) | tab pads 0.40 |
| all | GND / +3V3 pours, L1–L4 | – | – | **0.30** (the rule minimum); edge stitching vias 0.70 |

What follows from that:

- **No V-cut on any edge.** The pours are 0.30 mm from every edge, and JLC's V-cut guide
  wants at least 0.4 mm from the cut centre to copper. On top of that, U1's antenna hangs
  6 mm over the top edge, and J4's and J3's courtyards cross the bottom and right edges.
- **Moving J4 (and C30) 2.5 mm in would not make the board meet JLC's 2.5 mm rule.**
  C20, U6, MK1, J1, J3 and U1 fail it too, and the M2 holes are fixed by the display.
  A JLC-assembled board needs a rails/fixture plan for the whole board, not just J4.

**Options**

| | A. Single routed boards, hand assembly **(proposed)** | B. Routed + mouse-bite panel with rails (only for JLC assembly) | C. Placement revision: J4 and C30 2.5 mm in |
|---|---|---|---|
| What | 5 single PCBs, outline routed by the fab, no panel, no V-cut. Stencil as already planned. Paste + hot air for SMD, then J4, C30, C20 and J1 THT with an iron. Nothing to depanel. **Chosen without stencil** (below). | KiKit-style panel: 2 mm milled gap, mouse-bite tabs only where no part is within 2.5 mm (e.g. bottom edge x 135–145, under the test pads), rails on the long sides; the top rail is kept clear of the antenna overhang (≥ 8 mm gap). J4/C30/C20 hand-soldered after depanelling. | J4 to y 126.25 (front 2.50 mm inside), C30 up 1.70 mm. Re-route the LED legs (Freerouting is not deterministic, so all signals re-route and need a full re-review). |
| J4 body / copper to the separation path | **0.30 / 8.58 mm** to the routed edge (fab outline tolerance is typically ±0.2 mm, so ≥ 0.10 mm worst case; the housing never overhangs) | 0.30 mm to the board edge, 2.3 mm to the panel frame (2 mm gap); no tab within 2.5 mm of J4 | 2.50 / 10.78 mm |
| C30 body / copper | **0.80 / 4.80 mm** | 0.80 mm to the edge, 2.8 mm to the frame | 2.50 / 6.50 mm |
| Edge copper | 0.30 mm, fine for a routed edge | 0.30 mm; mouse-bite tab spots need a local ≥ 0.5 mm copper keep-out (board edit) | unchanged |
| Cost | none extra | panel design + edge keep-outs at tabs + JLC rail/fixture charges; still breaks the 2.5 mm rule for 8 other parts | a re-route and re-review; the plug mouth sits 2.5 mm inside the board, so the case slot gets deeper and the cable bends over the PCB edge |
| Fixes | everything that matters for Rev A | lets JLC assemble the SMD parts | nothing on its own (other parts still fail the 2.5 mm rule) |

**Decision (Chris, 2026-10-06): A without stencil.** Proposal was: A for Rev A. It matches the plan of record (5 boards, hand-built), needs no
board change, and the routed edge is the only separation path: J4's housing stays
0.30 mm inside it, its pads 8.58 mm. Order settings to state when Chris orders:
delivery format **single PCB** (no "panel by JLCPCB", no V-cut), **no PCBA**, **no
stencil**. If a panel is ever forced, it must be **mouse bites, not V-cut**, with no tab on the
bottom edge between x 110 and 133 (C30 + J4), and J4 is soldered after depanelling.
B (or a bottom-edge redesign of the whole board) is a Rev B question, if Rev B goes to
JLC assembly.

**Production files checked (SQU-45):** `reports/fab/room-node-rev-a-gerbers.zip` has one
outline (`Edge_Cuts`, profile only: board, the island slots and the neck slot), no
V-score or panel layer, no CPL/position file and no panel. The BOM lists J4 / C30 / C20
with LCSC numbers for buying, not as JLC-assembly lines. Nothing in `reports/` implies
JLC assembly or a panel.

**Placement** (looking at the parts side, USB-C on the left):

| Area | Parts |
|---|---|
| Left edge, top | R1/R2/R6/R7 (CC), R9/R10 at U1; H1 |
| Left edge, centre | **J1 USB-C** (centred on y = 119.0), U5 ESD right of it |
| Left, under U5 | C1 (above) / C2 (below) on the +5V spine via |
| Bottom-left corner | H3, MK1 mic + C10/C11 at its +3V3 pin, R11/R8 left of them. Sound hole through the board |
| Centre-left, top edge | U1 module; C6/C7/R3/C8 at its left pins |
| Under U1 | R30 at U1 pin 23 |
| Right of J4 | **Test pads in a 2 × 4 block** (SQU-42), 2.8 mm pitch, x 134.0–142.4: top row y 127.5 TP4 RXD0, TP5 +3V3, TP6 +5V, TP7 GND; bottom row y 130.6 TP1 EN, TP2 IO0, TP3 TXD0 and D1 (142.9). Labels above the top row (y 125.85) and in one line under the bottom row (y 132.88; TP2's was 1.9 mm lower until SQU-45) |
| Bottom edge under U1 | **C30 1000 µF**, then **J4 LED connector** (side entry); 15.6 mm to the island, the test-pad block in between |
| Right of U1 | C9/TP8 (CC sense), SW2 BOOT / SW1 RESET, R4/R12 |
| Bottom centre | U6 AHT20 + C40 on an island: slots left, right and in the neck; R40/R41 |
| Right, top | **U2 LDO** (tab on a F.Cu +3V3 copper area with 5 vias to L3), C3/C4/C5 |
| Right edge | **J3 display connector**, side entry; C50 at its +3V3 pin |
| Right, lower | U3 amp + C21/C22 at VDD pins 7/8, R20, C20 470 µF, J2 speaker |

**What moved in SQU-42** (Chris: J4 side entry, cable flat out of the bottom edge;
numbers from `tools/pcb_audit.py` and the footprint geometry):

| Part | From (SQU-39) | To | Reason |
|---|---|---|---|
| J4 | B3B-XH-A vertical, (124.0, 133.6) | **S3B-XH-A side entry**, (124.0, 128.45) rot 0 | mouth on the bottom edge, housing front 0.30 mm inside it |
| TP1–TP3 | x 121.0–126.6, y 127.5 | x 134.0 / 136.8 / 139.6, y 130.6 | the 11.6 mm deep housing covers their old spots |
| TP4–TP7 | x 129.4–137.8, y 127.5 | x 134.0 / 136.8 / 139.6 / 142.4, y 127.5 | same; TP6 (+5V) stays in the top row and drops straight onto the spine |
| D1 | (141.6, 127.5) | (142.9, 130.6) | end of the bottom test-pad row; courtyard 2.98 mm from the island slot |

C30, U6 and the island, R30, the mic and every other part did not move. The board was
rebuilt end to end (`tools/pcb_build.py` place → Freerouting 2.4.1 on Temurin 25 →
route), so the signal tracks are a fresh router result again (see the EPD table).

**What moved in SQU-39** (Chris: J4 crowded the left edge right under J1, and the space
under U1 was empty; every number from `tools/pcb_audit.py`):

| Part | From (SQU-35/38) | To | Reason |
|---|---|---|---|
| J1 | origin (109.155, 110.525), body centre y 113.5 | (109.155, 116.025), body centre **y 119.0** | centred on the left edge |
| U5 | (114.5, 113.5) | (114.5, 119.0) | stays next to J1 (moved with it) |
| J4 | (103.5, 122.3), left edge | (124.0, 133.6), bottom edge | off the crowded left edge; cable out of the bottom edge, ≥ 15 mm from U6 |
| C30 | (114.5, 125.8) rot 0 | (118.0, 132.2) rot 180 | at J4, + pad facing J4 pin 1 |
| C1 / C2 | (103.6, 128.2 / 130.6) | (113.6, 122.4 / 125.6) | on the +5V spine via under U5 |
| C10 / C11 | (107.4 / 109.9, 130.0) rot 90 | (108.6, 131.4 / 128.6) rot 0 | C30 took their spot; still at MK1's +3V3 pin |
| R11 / R8 | (112.6, 133.2 / 135.6) | (104.0, 128.6 / 131.4) | same |
| TP1–TP7 | x 124.3–141.1, y 124.5 | x 121.0–137.8, y 127.5 (same 2.8 mm pitch) | clear of the +5V spine at y = 124.0; one row under U1 |
| D1 | (143.0, 128.6) | (141.6, 127.5) | in line with the test pads |

J3, J2, U2/C3/C4/C5, U3 and its caps, C20, U6 and the island, the mic sound hole and the
four M2 holes did not move.

**SQU-35 moves** (history, before the SQU-39 changes above):

**What moved and why** (every number measured by `tools/pcb_audit.py`):

| Part | From | To | Reason |
|---|---|---|---|
| J3 | (128.0, 133.08), bottom edge under U1 | (184.5, 117.5) rot 90, right edge | display cable out of the right edge (184.6 in the first SQU-35 cut, pulled 0.10 mm in for edge margin) |
| J4 | (172.0, 104.0), top right | (103.5, 122.3), left edge below J1 | LED cable out of the left edge, next to J1 |
| C30 | (178.0, 113.5) | (114.5, 125.8) | stays with J4 on the short +5V leg |
| C1 / C2 | (104.0, 121.2 / 123.4) | (103.6, 128.2 / 130.6) | J4 took their old spot |
| U2 + C3/C4/C5 | (111.5, 124.5) and around | (170.0, 104.6), same group translated by (+58.5, −19.9) | J4 and C30 took the lower left; the group moved as one rigid block so the reviewed M3 tab copper and its 5 vias are unchanged |
| C10/C11/R8/R11 | around the mic | (107.4/109.9, 130.0) and (112.6, 133.2/135.6) | C30 and the trunk took the old band |
| C50 | (115.0, 131.5) | (177.5, 121.0) | follows J3 to the right edge |
| TP1–TP7 | x 121.5–138.3 | x 124.3–141.1 (same 2.8 mm pitch, same y) | TP1 was inside C30's body circle |
| C20 | (166.4, 132.6) | (165.0, 132.6) | makes room for J2 under J3 |
| C22 | (171.0, 125.75) | (171.0, 126.0) | 0.20 mm courtyard gap to C21 |
| J2 | (179.2, 133.0) | (176.3, 133.0) | out from under J3's courtyard |

**Sensor isolation.** SQU-42 moves no heat source: J4 keeps its x span and C30 its
place, and the +5V copper is still 5.85 mm from the island box. SQU-39 moves no heat source nearer U6: J4 and its +5V leg are
15.60 mm (slot) / 18.81 mm (U6 courtyard) away, and the widest +5V copper (the 1.50 mm
spine) is now **5.85 mm** above the island box instead of 1.85 mm (spine at y = 128.0).
From SQU-35: moving the LDO is the change to look at hardest. U2's tab is now
**37.26 mm** from U6's +3V3 pad against **38.41 mm** before — 1.15 mm closer, with the
island and its three slots unchanged. The bottom-left corner could not hold J4, C30 and
the LDO as well as the mic and H3, and of the two spots that were left (bottom centre,
or the top right that the LED connector vacated) the top right is the far one: putting
U2 in the bottom centre would have taken the gap down to about 25 mm. The amp U3 is
21.95 mm from U6, unchanged.

**What got longer.** The display connector is now at the opposite end of the board from
U1, so the six EPD signals grew from 17.5–33.6 mm (before SQU-35) to **56.84–66.40 mm**,
measured on the SQU-42 board (`tools/pcb_audit.py`; SQU-39 was 56.84–66.40 mm, the
SQU-35/38 route 55.76–71.91 mm):

| Net | Length | Vias |
|---|---|---|
| EPD_BUSY | **65.46 mm** (longest) | 2 |
| EPD_MOSI | 61.20 mm | 2 |
| EPD_CS | 60.48 mm | 2 |
| EPD_CLK | 57.82 mm | 2 |
| EPD_RST | 57.06 mm | 4 |
| EPD_DC | 55.57 mm (shortest) | 2 |

EPD_RST came back from the router with 4 vias instead of 2 (two extra layer changes,
each over the solid L2 GND; at SQU-39 it was MOSI and CLK); harmless at 2 MHz and on a
static reset line, noted for Iris.

ESPHome 2026.9.0's Waveshare driver clocks the panel at 2 MHz (500 ns period) and the
firmware does not override it, so 72 mm of track with 2 vias over the solid L2 return is
not a timing problem; it is the direct cost of the short cable (Iris, SQU-37). Verify the
display at bring-up, with a short display cable. Going the other way, the LED data line
is now U1 → R30 7.18 mm and R30 → J4 pin 2 **12.53 mm** (SQU-42; 18.38 mm at SQU-39,
31.87 mm at SQU-35, 56.85 mm before); the speaker pair is unchanged (14.14 / 16.12 mm, no vias).

**Layers**

| Layer | Use |
|---|---|
| F.Cu (L1) | Parts, most signals, GND fill |
| In1.Cu (L2) | GND plane, solid |
| In2.Cu (L3) | +3V3 plane, solid. No tracks |
| B.Cu (L4) | Signals, +5V riser and spine (J1 → C30/J4 and → amp/LDO), GND fill |

- **+5V** is a track, not a plane, and the whole net is hand routed (`preroute()` in
  `tools/pcb_build.py`), not left to the router. Topology:

  | Leg | Layer | Width | Length | Carries |
  |---|---|---|---|---|
  | J1 VBUS pads B9→A4 and B4→A9, then out of the pin field to x = 110.60 | B.Cu | 0.60, **two in parallel** | 2 × (1.35 + 1.45) mm | everything, ~half each |
  | **riser** at x = 110.60, y 116.875 → spine at y = 124.0 | B.Cu | **1.50** | 7.13 mm | everything |
  | **spine** x 110.60 → 118.00 (the C30 + pad column) | B.Cu | **1.50** | 7.40 mm | everything |
  | LED leg: down x = 118.00 to **C30 +**, then to **J4 pin 1** | B.Cu | **1.50** | 8.20 + 7.08 mm | LED strip, up to ~1.6–2 A |
  | spine x 118.00 → 168.00 at y = 124.0, then down to C20 pad 1 | B.Cu | **1.50** | 50.00 + 9.84 mm | amp + LDO |
  | TP6 straight up onto the spine (TP6 at x = 139.6, SQU-42) | F.Cu | 1.00 | 3.5 mm | test point |
  | spine via → C1 (up) and C2 (down) | F.Cu | 1.00 | 1.60 + 1.60 mm | USB input caps |
  | U5 pin 5 (VBUS sense) up, via, to the riser top | F.Cu + B.Cu | 0.50 + 1.00 | 1.50 + 3.93 mm | ESD clamp, mA |
  | spine via → C22 → C21 → U3 pins 7/8 | F.Cu | 1.00 / 0.80 | — | amp, ~0.9 A peak |
  | spine → up past U3 → U2 pin 3 and C3 | B.Cu + F.Cu | 1.00, 0.60 beside U3 | — | LDO, ≤ 0.5 A |

  **J1 → J4 path (SQU-42), measured on the copper** (`tools/pcb_audit.py`, shortest
  track path from J1's VBUS pad A9 to J4 pin 1): **27.00 mm**, of which 25.55 mm is
  1.50 mm wide and 1.45 mm is one of the two parallel 0.60 mm necks (26.08 mm at SQU-39,
  ~22 mm at SQU-35 with J4 next to J1). DC resistance ~8.5 mΩ, **14 mV drop at 1.6 A**;
  IPC-2221 rise 2.1 °C at 1.6 A, 3.4 °C at 2.0 A on the 1.50 mm track.
  The leg never runs along the island: it leaves the spine 29.6 mm west of the island's
  left slot and drops to the bottom edge there.

  | Current | 1.50 mm rise | 0.60 mm neck (half the current each) |
  |---|---:|---:|
  | 1.6 A (LED, Chris's figure) | **2.1 °C** | 1.9 °C |
  | 2.0 A (LED full white) | 3.4 °C | 3.2 °C |
  | 3.4 A (LED + amp + LDO, riser and first 7.4 mm of spine only) | 11.4 °C | 10.7 °C |

  (IPC-2221, external layer, 1 oz, k = 0.048.) **The common inlet is 1.50 mm, not
  "1.50 mm end to end":** the only part of the path from J1 to the split that is narrower
  is the 2 × 1.45 mm of 0.60 mm neck through the USB-C pin field, where the 0.70 mm pads
  on a 0.85 mm pitch leave no more room (0.20 mm to the neighbouring pad either side).
  The two necks are in parallel and carry about half the current each. The riser clears
  J1's A-row pads by 0.345 mm.
  The other deliberately thin parts are 0.25 mm stubs at U3's 0.5 mm-pitch pins
  (including the 0.25 mm neck into pins 7/8 and the GAIN_SLOT stub to pin 2, which
  carries no current), 0.6 mm for the LDO branch where it squeezes past U3, and the
  0.50 mm U5 VBUS-sense stub (mA).
- **GND / +3V3:** every SMD pad has its own via to its plane (fan-out). GND stitching
  vias on a 5 mm grid and along the edge, 45 of them.
- **Speaker pair** U3 → J2: 0.4–0.5 mm, side by side, no vias.
- **USB D± (SQU-39):** 0.2 mm, **all on F.Cu over the L2 GND plane except the
  in-connector crossover, no vias.** USB-C puts D+ on A6/B6 and D− on A7/B7, and the two
  pairs cross inside the pin field, so one of them must join its two rows on the other
  layer: D+ joins B6–A6 on F.Cu, D− joins B7–A7 on B.Cu (1.60 mm, through J1's own
  pins). J1 → U5 is hand-routed in `preroute()`: D− straight into U5 pin 1, D+ between
  U5's two pad rows into pin 3. U5 → U1 is routed on F.Cu only (a `use_layer F.Cu` class
  in the DSN; at SQU-35/38 D+ had 2 vias and a B.Cu section here). Copper length J1 → U5
  → U1, pad to pad, excluding U5's internal path:

  | Plug orientation | D+ (J1→U5 + U5→U1) | D− (J1→U5 + U5→U1) | Difference |
  |---|---:|---:|---:|
  | A pads | 7.61 + 3.86 = **11.47 mm** | 4.68 + 7.73 = **12.41 mm** | 0.94 mm |
  | B pads | 9.20 + 3.86 = **13.06 mm** | 6.28 + 7.73 = **14.01 mm** | 0.95 mm |

  SQU-36 measured 28.20 / 12.70 mm (A) and 26.93 / 14.41 mm (B) on the SQU-35 board,
  15.5 mm apart; the D+ detour round the pin field is gone. Still Full Speed only
  (12 Mbit/s), so a 1 mm skew is irrelevant; USB enumeration stays a bring-up test (step 4).

- **LDO heat:** the U2 tab sits on a F.Cu +3V3 copper area (6.2 × 3.3 mm, 20.4 mm², full
  connection) with vias to the L3 plane next to the tab, not in it (no solder wicking):
  **4 × 0.3 mm drill plus 1 × 0.4 mm drill beside the tab, 7 vias in total on the copper
  area** (the other two are C4's and C5's). C4/C5 +3V3 pads are on the same area. The
  0.3 mm column sits 0.65 mm clear of the tab copper, so a weak via tent cannot pull
  solder off the tab. The whole cluster moved with U2 as a rigid block in SQU-35, so the
  geometry is the one Iris reviewed; it is now generated from the tab pad position
  (`TAB_AREA` / `TAB_VIAS` in `tools/pcb_build.py`) instead of fixed coordinates. The
  area is at x 171.90–178.10, y 103.00–106.30, the vias at (174.80, 103.40 / 104.60 /
  105.80), (175.70, 105.80) and (176.90, 105.80).
  The drills are re-asserted **after** the SES import (`fix_tab_vias()`): the DSN/SES
  round trip hands the pre-routed vias to Freerouting and they come back with the
  router's padstack for the net class, which is how the first SQU-35 board ended up with
  the 0.30 mm column at 0.40 mm (SQU-38 item 3).
- **Amp decoupling:** C21 (0.1 µF) 0.7 mm below VDD pins 7/8, C22 (10 µF) right below it,
  both on the +5V feed to the pins. Each GND pad has its own via to L2.
- **Antenna end:** a rule area at x 120.50–135.50, y 100.00–104.60 (all four copper
  layers) takes signal tracks and vias out of the strip between the top board edge and
  U1's pin 3 / pin 38 row. Pads and the pours are still allowed, so L2 is not slotted.
  This is what SQU-32 had to do by hand for CC_SENSE; it is now a constraint the router
  cannot break. CC_SENSE's run across the module is 13.12 mm at y = 104.99, 4.99 mm
  below the top edge (it was 14.30 mm at 2.76 mm when Iris flagged it). The only copper
  left at y = 102.76 is U1 pin 39's own pad and the 1.00 mm stub leaving it at
  x 136.75–137.75, both outside the rule area and east of the antenna.

**Design review fixes (Iris, SQU-31, 2026-10-05):** M1 C21/C22 moved to U3 pins 7/8;
M2 0.6 mm +5V sections on the LED path widened or rerouted (see +5V above); M3 U2 tab
copper area + vias; M4 AMP_SD under U1 moved to y = 106.4 (0.76 mm from the module's
GND pad, was 0.15 mm).

**Review polish (SQU-32, 2026-10-05)**, on top of the J3 side-entry change:

| Item | Result |
|---|---|
| C6 rotated | C6's +3V3 pad now faces U1 pin 2, with a 2.01 mm × 0.3 mm F.Cu track straight to it (was plane-only, 4.5 mm apart). C7 is unchanged: the EN track crosses the corridor between C7 and C6 at y = 104.03, so C7 keeps its own +3V3 plane via. |
| CC_SENSE lower | Was 14.3 mm across the module at y = 102.76, 2.76 mm below the antenna line. Now 13.12 mm at y = 104.99, 4.99 mm below, held there by the antenna-end rule area rather than by hand. What is left at y = 102.76 is U1 pin 39's own pad and the 1.00 mm stub leaving it, both east of the antenna and outside the rule area. |
| C40 GND | **Skipped**, no room — see SQU-32. |
| Mic hole | No via on any layer within 2.00 mm of the sound hole at (108.50, 135.51), so the case gasket sits flat. Enforced by the "MK1 gasket seat" rule area: a 2.5 mm radius ring that forbids **vias** but still allows tracks and the pours, so the planes stay solid round the mic. It is not a no-copper rule. |
| Island neck slot | 1.00 × 1.25 mm routed slot at x 150.50–151.50, y 131.35–132.60. The 6.80 mm top neck becomes 5.80 mm. 1.0 mm is the JLC routed-slot minimum; it sits between the +3V3 feed at x = 149.7 and the I2C pair at x ≈ 152.4–152.9, with a 0.35 mm copper keep-out round it. |
| U3 pin 3/11 vias | Pin 11's via sits clear of the exposed pad. **Pin 3's via could not move** — see SQU-32. |
| U2 via column | 0.65 mm clear of the tab copper (see LDO heat above). |
| +5V widths | See the +5V table above. The common inlet and the LED path are 1.50 mm; only the two parallel 0.60 mm necks through the USB-C pin field are narrower (SQU-38 item 2 corrected the earlier "1.50 mm end to end" claim). |
| U3 pins 7/8 | The wide feed stops 0.30 mm clear of the pad row; the last 0.70 mm is 0.25 mm, equal to the pad width, so the fillets are even. |
| Silkscreen | The silk pass moves reference fields away from pads, other silk and the board edge where it can. It cannot always: 7 references in the dense 0603 clusters still sit over a neighbour's pad — see the DRC warnings below. |

After SQU-35 all of these are rules inside `tools/pcb_build.py`, so a rebuild reproduces
them. `tools/pcb_squ32.py` was the one-shot, coordinate-exact patch that first applied
them to `f8a871e`; it is **superseded** and must not be re-run. `tools/pcb_silk.py` is
still the silkscreen pass and is re-runnable (it now also refuses to park a reference
nearer another part's centre than its own, so a label is never read as the neighbour's).
`tools/pcb_audit.py` prints the measurements quoted in this file.

**Re-review fixes (Iris, SQU-37 → SQU-38, 2026-10-06)**, on top of SQU-35:

| Item | Result |
|---|---|
| J3 edge margin | J3 (184.600 → **184.500**, 117.500) rot 90. Mounting-tab copper 189.200 → **189.100**, so the margin to the routed edge at 189.500 is **0.400 mm**, not 0.300 mm. The housing front stays 0.55 mm inside the edge and the cable still leaves straight out of the right edge; the pin-1 triangle moved with the footprint, tip now (179.60, 124.50). EPD track lengths are unchanged — the pads are 3.5 mm long, so the routes still land well inside them. |
| +5V inlet | The common section from J1's VBUS pads to the trunk split was 1.00 mm for 8.23 mm plus a 0.56 mm turn. It is now a single **1.50 mm** riser at x = 110.60, y 111.375 → 124.600 (13.23 mm), fed by two 0.60 mm × 1.45 mm necks out of the pin field. 0.345 mm to J1's A-row pads, 0.200 mm at the necks (unchanged). |
| M3 tab vias | The four 0.30 mm drills are back (0.60 mm pads), with the fifth at 0.40 mm: exactly the geometry Iris reviewed in SQU-31. `fix_tab_vias()` re-asserts them after the SES import so the router cannot change them again. |
| Records | EPD lengths, the +5V width table, the mic gasket-seat rule (no **vias**, not no copper) and the silkscreen warning breakdown are corrected above against the committed board. |

**DRC at hand-over (SQU-39):** **0 errors, 0 unconnected, 0 schematic-parity issues**;
ERC 0 errors (1 pre-existing warning: U3's PAD pin is Unspecified against a Power input).
`tools/check_pinout.py` PASS. 12 DRC warnings, all silkscreen (14 at SQU-38):

- **2 `silk_edge_clearance`:** U1's module body outline where the antenna overhangs the
  top edge (the module footprint would have to be edited, which trades them for a
  `lib_footprint_mismatch` warning) — unchanged from before;
- **3 `silk_overlap`:** reference designators touching other silk in the dense 0603
  clusters (R1/R2, R6/R7, R9/R10 at 1.7–1.8 mm pitch), where the text is wider than the
  gap between parts. Cosmetic. The C1/C2/C10/C11 overlaps are gone with SQU-39 (those
  parts now have room, and C30 / C10 / C11 / MK1 have fixed label spots, `REF_AT` in
  `tools/pcb_build.py`);
- **7 `silk_over_copper`:** four references (**R1, R7, R9, R10**, in the CC and mic 0603
  clusters) printed over a neighbouring part's pad. These are **not** harmless overlaps —
  the fab clips silkscreen off pads, so those four references may come out partly or
  completely missing on the real board. **Do not assume every reference prints legibly.**
  Accepted for five hand-assembled Rev A boards because assembly works from
  the KiCad board and the F.Fab layer, and the markings that matter without a screen —
  J3's pin-1 triangle, the electrolytic polarity marks and the connector outlines — are
  clear of pads. Worth a silkscreen pass at rev B (Iris, SQU-37).

The count was 5 before SQU-35, because the old silk pass was allowed to park a reference
on a neighbouring part; it is no longer, so labels sit on their own part and overlap
instead. The readable one is the safer trade.

**SQU-45 re-check** (TP2 reference moved up 1.90 mm into the TP1/TP3 label row; no other
board change): DRC 0 errors, 0 unconnected, 0 parity issues, the same 12 silkscreen
warnings (none on TP1–TP7); ERC unchanged; `tools/check_pinout.py` PASS. Only the
F.Silkscreen Gerber changed.

Report: `reports/pcb/room-node-drc.rpt`. Pictures: `reports/pcb/room-node-top.png`,
`room-node-bottom.png` (the side that faces the display), `room-node-copper-top.png`,
`room-node-copper-bottom.png`.
Gerbers + drill (JLCPCB): `reports/fab/room-node-rev-a-gerbers.zip`.

**Open points for review**
1. Hole positions are from the Waveshare drawing. Check them on the real module.
2. Mic sound hole faces the display (bottom side). The case needs an air path from the
   room to the gap between the boards, near the bottom-left corner.
3. SW1/SW2 (RESET/BOOT, only for flashing) and D1 face the back of the case. The
   voice button was removed (2026-10-05, wake word only).
4. Some F.Cu tracks run under U1 (under the module's solder mask). Normal for this
   module, but Iris checks it.
5. Silkscreen: the C6/C7/R3/C8 references end up at x ≈ 121.5, under the module body,
   where they cannot be read after U1 is fitted. Fine for assembly (the module goes on
   last), but worth a look at rev B.
6. **SQU-35:** the EPD signals are now 55.8–71.9 mm long because J3 sits at the far end
   from U1. Iris cleared this against the Waveshare driver's 2 MHz SPI (SQU-37); still
   verify the display at bring-up, with a short display cable.
7. **SQU-35, new:** the LDO moved to the top-right corner, 37.3 mm from the AHT20
   (was 38.4 mm). Check the thermal reasoning in "Sensor isolation" above.
8. **SQU-35, closed by SQU-38:** J3's mounting-tab copper was at exactly the 0.30 mm
   copper-to-edge limit; J3 moved 0.10 mm in and it is now 0.40 mm.
9. **SQU-35, updated by SQU-39:** the case needs an opening or channel on the **right**
   side for the display cable, and the LED cable now leaves at the **bottom edge**, under
   U1, about 24–30 mm from the left end (J4 courtyard x 121–132). USB-C stays on the
   left, now centred. The enclosure notes in `docs/enclosure.md` predate both changes.
10. **SQU-39, closed by SQU-42:** J4 is now the side-entry S3B-XH-A (Chris, SQU-17),
   cable straight out of the bottom edge. The housing front is 0.30 mm inside the edge;
   the plug sticks out past it, so the case needs a ~10 mm slot in the bottom wall
   centred on x = 126.5. `docs/enclosure.md` does not have this yet.
11. **SQU-39, closed:** C30 (10 mm can) sits on the bottom edge between the mic and J4;
   its courtyard is 0.31 mm inside the edge. Chris: OK, the case clears it (SQU-17).

## Placement

- **Antenna:** the module antenna hangs over the board edge. No copper, parts or traces
  under or near it. Respect the footprint keep-out.
- **Mic (MK1):** opposite end of the board from the speaker connector and the amp.
  Away from the LED connector and the antenna. Sound enters from the **bottom** through
  the hole in the footprint: no copper, vias or traces inside the GND ring, and keep the
  bottom side around the hole clear for a gasket.
- **AHT20 (U6):** board edge, far from module, LDO, amp and LED connector. Slots left,
  right and in the neck, open at the top for the tracks.
- **USB:** U5 at J1. R6/R7 near J1. C9/TP8 near U1 pin 39.
- **Amp:** C20/C21/C22 at U3. Short, wide +5V and GND.
- **LED:** J4 (side entry, mouth on the edge) on the bottom edge under U1, at least 15 mm from the AHT20 island, C30 at
  the connector. R30 stays at U1 pin 23, where a source series resistor belongs.
- **Display:** J3 on the right edge, side entry, pin 1 marked on the silk. C50 at its
  +3V3 pin.
- **Ground:** route amp and LED return currents so they do not pass under the mic or the sensor.

## Assembly

- Hand assembly, no stencil (SQU-45). Paste from a syringe + hot air (or a hot plate) for
  the parts with pads under the body: **U1 centre GND pad, U3, U6, MK1**. Do these first.
  The U1 pad vias are 0.2 mm and covered by solder mask on the back, so the pad cannot be
  soldered from the back with an iron. Then the rest (0603/0805, SOT-223, SOT-23-6, LED,
  buttons, connectors, C20/C30) with an iron.
- The module pad and the amp pad cannot be inspected. If the board resets under Wi-Fi or
  the amp cuts out, suspect those joints first.
- After the mic is fitted: no board wash, no IPA, no ultrasonic. No hot air or air jet into the sound hole.

## Bring-up order

1. Check every rail to GND for shorts.
2. Bench supply, 5 V, current limit ~200 mA. Watch the current.
3. Check +5V, then +3V3.
4. USB: enumerate, flash, read logs.
5. Each part in turn: LEDs, display, sensor, mic, speaker.
6. **Hot-plug test:** plug into a laptop USB port 10+ times. If the port shuts off, rev B adds a soft-start switch.
7. **CC sense:** compare TP8 (multimeter) with the firmware value on a 3 A charger, a laptop port and a USB-A cable.

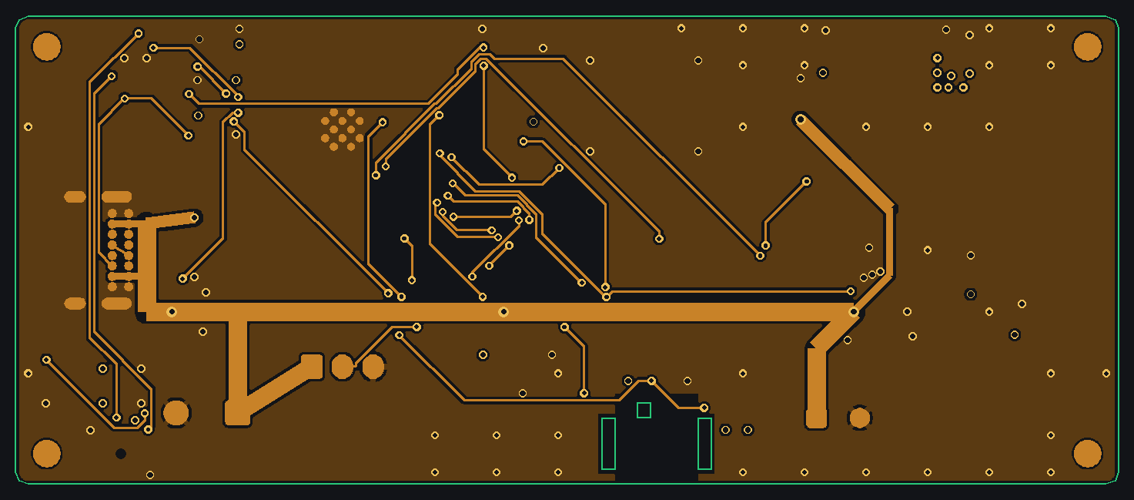
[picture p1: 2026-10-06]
reports/pcb/room-node-copper-bottom.png

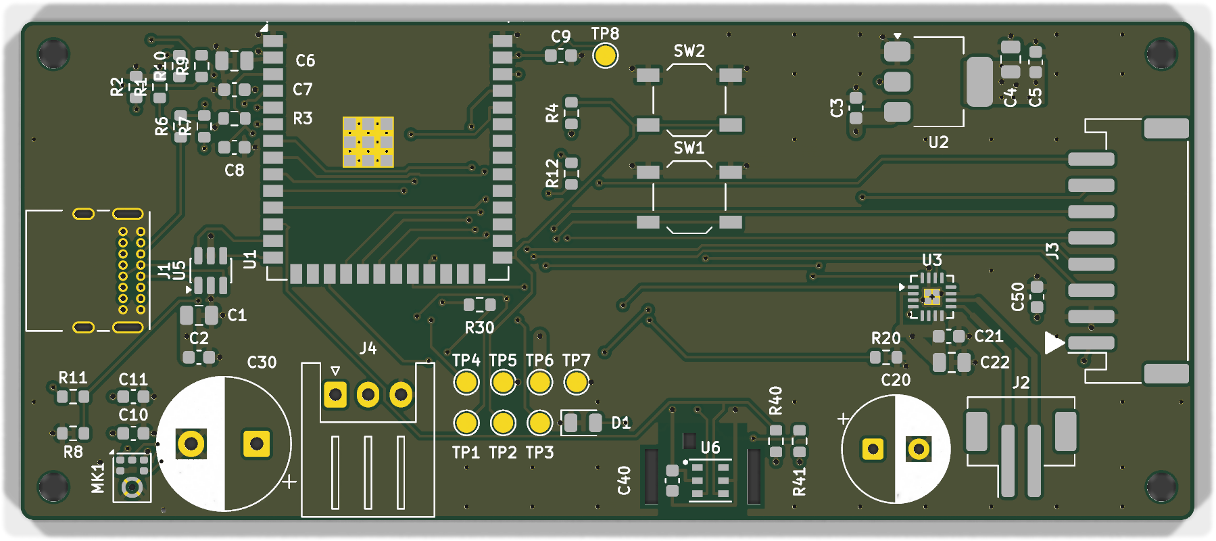
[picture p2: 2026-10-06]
reports/pcb/room-node-top.png

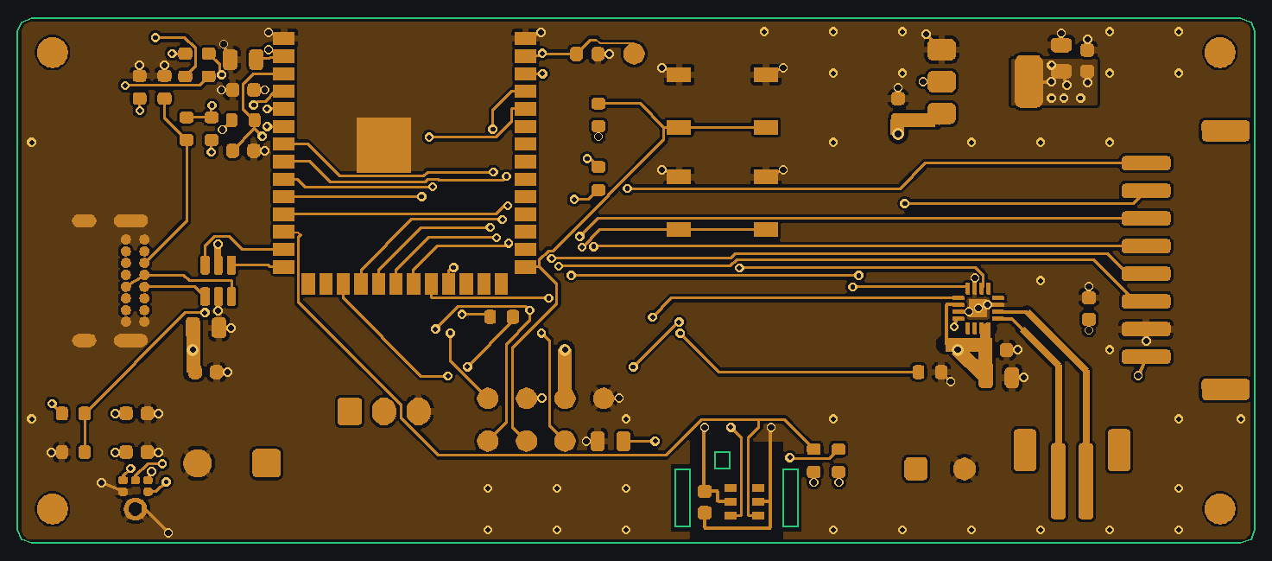
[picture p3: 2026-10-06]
reports/pcb/room-node-copper-top.png

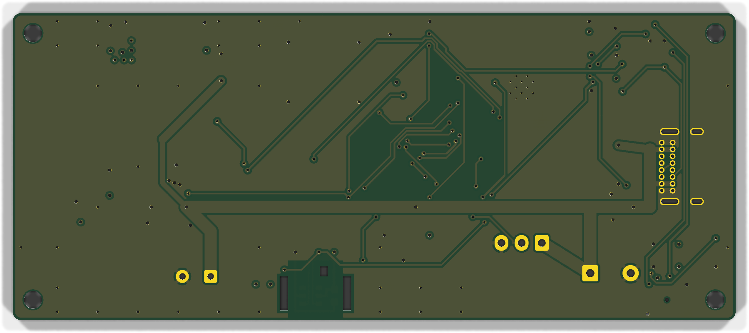
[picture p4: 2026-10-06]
reports/pcb/room-node-bottom.png

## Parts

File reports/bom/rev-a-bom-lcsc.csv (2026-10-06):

Block | Ref | Part | MPN | LCSC# | JLC_Class | Price@10_est_USD | Stock_est | Lifecycle | Alternate | Notes
Block 1 - MCU+Power+USB | U1 | ESP32-S3 module | ESP32-S3-WROOM-1-N16R8 | C2913202 | Extended | 2.12 | Moderate | Active | ESP32-S3-WROOM-1-N8R8 | Stock KiCad symbol RF_Module. Checked 2026-10-01: https://www.lcsc.com/product-detail/WiFi-Modules_Espressif-Systems-ESP32-S3-WROOM-1-N16R8_C2913202.html
Block 1 - MCU+Power+USB | U2 | 3V3 LDO 1A | AP7361C-33ER-13 (SOT-223R) | C3743528 | Extended | 0.32 | High | Active | TLV75901PDRVR | ER suffix only! SOT223R: 1=GND 2=OUT 3=IN. -33E-13 has wrong pinout. Checked 2026-10-01: https://www.lcsc.com/product-detail/C3743528.html
Block 1 - MCU+Power+USB | U5 | USB ESD | USBLC6-2SC6 (SOT-23-6) | C7519 | Extended | 0.10 | High | Active | ESD7351 | Stock KiCad Power_Protection. Checked 2026-10-01: https://www.lcsc.com/product-detail/ESD-and-Surge-Protection-TVS-ESD_STMicroelectronics-USBLC6-2SC6_C7519.html
Block 1 - MCU+Power+USB | J1 | USB-C receptacle | USB4085-GF-A (GCT) | C7095263 | Extended | 0.80 | High | Active | HRO TYPE-C-31-M-12 | Footprint: Connector_USB:USB_C_Receptacle_GCT_USB4085. Checked 2026-10-01: https://www.lcsc.com/product-detail/C7095263.html
Block 1 - MCU+Power+USB | SW1-SW2 | Tactile switch | TL3342F160QG | C2886898 | Extended | 0.55 | Good | Active | TS-1187A (Basic) | Stock KiCad footprint. Checked 2026-10-01: https://www.lcsc.com/product-detail/Tactile-Switches_E-Switch-TL3342F160QG_C2886898.html
Block 1 - MCU+Power+USB | R1,R2 | 0603 5.1kΩ 1% | Generic | C23186 | Basic | 0.0015 | Very High | Active | - | Corrected from C25919 (7.68k 0402)
Block 1 - MCU+Power+USB | R3-R4 | 0603 10kΩ 1% | Generic | C25804 | Basic | 0.002 | Very High | Active | -
Block 1 - MCU+Power+USB | C1 | 0805 10µF 16V X5R | Generic | C15850 | Basic | 0.065 | Very High | Active | - | Corrected from C169506 (MB14S bridge rectifier)
Block 1 - MCU+Power+USB | C2 | 0603 0.1µF 50V X7R | Generic | C14663 | Basic | 0.012 | Very High | Active | - | Corrected from C30722 (not found)
Block 1 - MCU+Power+USB | C3 | 0603 1µF 16V X5R | Generic | C15849 | Basic | 0.017 | Very High | Active | - | Corrected from C15850 (10µF 0805)
Block 1 - MCU+Power+USB | C4 | 0805 22µF 10V X5R | Generic | C45783 | Basic | 0.220 | High | Active | - | Corrected from C54614 (L7810 regulator)
Block 1 - MCU+Power+USB | C5,C7 | 0603 0.1µF 50V X7R | Generic | C14663 | Basic | 0.012 | Very High | Active | - | Corrected from C30722 (not found)
Block 1 - MCU+Power+USB | C6 | 0805 22µF 10V X5R | Generic | C45783 | Basic | 0.220 | High | Active | - | Corrected from C54614 (L7810 regulator)
Block 1 - MCU+Power+USB | C8 | 0603 1µF 16V X5R | Generic | C15849 | Basic | 0.017 | Very High | Active | - | Corrected from C15850 (10µF 0805)
Block 1 - MCU+Power+USB | R6,R7 | 0603 100kΩ 1% | Generic | C25803 | Basic | 0.002 | Very High | Active | - | CC1/CC2 -> CC_SENSE sum (added 2026-09-28)
Block 1 - MCU+Power+USB | C9 | 0603 0.1µF 50V X7R | Generic | C14663 | Basic | 0.012 | Very High | Active | - | CC_SENSE filter at GPIO1; corrected from C30722 (not found)
Block 1 - MCU+Power+USB | TP8 | Test pad D1.5mm | - | - | - | 0.01 | High | Active | - | CC_SENSE test point (added 2026-09-28)
Block 1 - MCU+Power+USB | R12 | 0603 1kΩ 1% | UNI-ROYAL 0603WAF1001T5E | C21190 | Basic | 0.0026 | Very High | Active | - | Status LED series resistor on GPIO2 (SQU-29). Checked 2026-10-02: JLC Basic, ~21.6M at JLC, ~3.2M at LCSC. https://www.lcsc.com/product-detail/C21190.html
Block 1 - MCU+Power+USB | D1 | 0805 LED green 525nm | Hubei KENTO KT-0805G | C2297 | Basic | 0.0165 | Very High | Active | KT-0603G C12624 (0603, Extended) | Status LED on GPIO2, active HIGH, ~0.5-0.9 mA (SQU-29). No green/blue 0603 LED in JLC Basic, so 0805. Datasheet pad 1 = anode; KiCad pad 1 = cathode: place by the cathode mark. Checked 2026-10-02: JLC Basic, ~3.1M at JLC, ~2.5M at LCSC. https://www.lcsc.com/product-detail/C2297.html
Block 2 - Audio Out | U3 | I2S Class-D amp | MAX98357AETE+ (TQFN-16) | C910544 | Extended | 0.82 | Moderate | Active | MAX98357BETE+ | Stock KiCad Audio:MAX98357A. LCSC carries +T (tape) variant. Checked 2026-10-01: https://www.lcsc.com/product-detail/C910544.html
Block 2 - Audio Out | C_amp_bulk | TH radial 470-1000µF 16V | SamYoung NXB16V470M8*11.5 3.5TP | C346937 | Extended | 0.153 | High | Active | - | Corrected from C144601/4 (resistors)
Block 2 - Audio Out | C_amp_cer | 0603 0.1µF 50V X7R | Generic | C14663 | Basic | 0.012 | Very High | Active | - | Corrected from C30722 (not found)
Block 2 - Audio Out | C22 | 0805 10µF 16V X5R | Generic | C15850 | Basic | 0.065 | Very High | Active | - | U3 VDD decoupling, added in PR #15. Iris assumption C15850 confirmed.
Block 2 - Audio Out | R20 | 0603 100kΩ 1% | Generic | C25803 | Basic | 0.002 | Very High | Active | - | U3 SD_MODE pull-down, added in PR #15. Iris assumption C25803 confirmed.
Block 2 - Audio Out | J2 | JST-PH 2-pin SMD | JST B2B-PH-SM4-TB(LF)(SN) | C160352 | Extended | 0.214 | Very High | Active | - | Corrected from C420309 (not found)
Block 3 - Mic | MK1 | I2S MEMS mic | SPH0645LM4H-B (Knowles->Syntiant) | TBD | Extended | 3.50 | Moderate | Transitioned (active via Syntiant; Knowles EOL) | SPH0645LM4H-H / ICS-43434 | Bottom-port LGA-6. -B=tray, -H=tape&reel. L/R->GND. Not on LCSC; order from DigiKey/Mouser.
Block 3 - Mic | R8 | 0603 100kΩ 1% | Generic | C25803 | Basic | 0.002 | Very High | Active | - | Mic DATA pull-down to GND (added 2026-09-28)
Block 3 - Mic | R9,R10,R11 | 0603 33Ω 1% | Uniroyal 0603WAF330JT5E | C23140 | Basic | 0.003 | Very High | Active | - | Corrected from C105881 (Yageo 330Ω RC0603FR-07330RL). Checked 2026-09-30.
Block 3 - Mic | C10 | 0603 0.1µF X7R | Generic | C14663 | Basic | 0.012 | Very High | Active | - | Mic VDD decoupling; corrected from C30722 (not found)
Block 3 - Mic | C11 | 0603 100pF C0G 50V | Generic | C14858 | Basic | 0.009 | Very High | Active | - | Corrected from TBD; Samsung CL10C101JB8NNNC
Block 4 - LED Ring | R_led | 0603 470Ω 1% | Generic | C23179 | Basic | 0.002 | Very High | Active | - | Corrected from C25727/8 (not found); 470Ω within 330-470Ω spec
Block 4 - LED Ring | C_led_bulk | TH radial 1000µF 16V | SamYoung NHA16V1000M10*16 LO | C2835709 | Extended | 0.225 | High | Active | - | Corrected from C144604 (33Ω resistor)
Block 4 - LED Ring | J4 | JST-XH 3-pin TH, side entry (right angle) | JST S3B-XH-A(LF)(SN) | C157928 | Extended | 0.073 | Very High | Active | S3B-XH-A-1(LF)(SN) C163036 | LED strip connector, side entry: cable out of the bottom edge (SQU-42). 3A rated, 2.5mm pitch. JLCPCB stock 137025, USD 0.0729 @1-99. Checked 2026-10-06: https://www.lcsc.com/product-detail/C157928.html. Was the vertical B3B-XH-A C144394 until SQU-42.
Block 4 - LED Ring | LED_strip | WS2812B 27px strip | Off-board | - | - | - | - | Active | -
Block 5 - Sensor | U6 | Temp/humidity sensor | AHT20 | C2757850 | Extended | 0.50 | High | Active | SHT30 | Symbol and footprint re-imported from LCSC C2757850 via easyeda2kicad (SQU-27). 6-pin DFN-6, pin 1 top-left per Aosong datasheet.
Block 5 - Sensor | R40,R41 | 0603 4.7kΩ 1% | Generic | C23162 | Basic | 0.003 | Very High | Active | - | Corrected from C25920 (7.87k 0402)
Block 5 - Sensor | C40 | 0603 0.1µF 50V X7R | Generic | C14663 | Basic | 0.012 | Very High | Active | - | U6 VDD decoupling, added in PR #15.
Block 6 - Display | J3 | JST-PH 8-pin SMD side entry | JST S8B-PH-SM4-TB(LF)(SN) | C265121 | Extended | 0.3674 | Good | Active | C20089303 | Switched from top-entry B8B (SQU-32). PS: Waveshare module ships PH-to-PH 8-pin cable; no separate PHR-8 housing if using that. Checked 2026-10-05: https://www.lcsc.com/product-detail/wire-to-board-connector_jst-s8b-ph-sm4-tb-lf-sn_C265121.html
Block 6 - Display | C50 | 0603 0.1µF 50V X7R | Generic | C14663 | Basic | 0.012 | Very High | Active | - | J3 VCC decoupling, added in PR #15.

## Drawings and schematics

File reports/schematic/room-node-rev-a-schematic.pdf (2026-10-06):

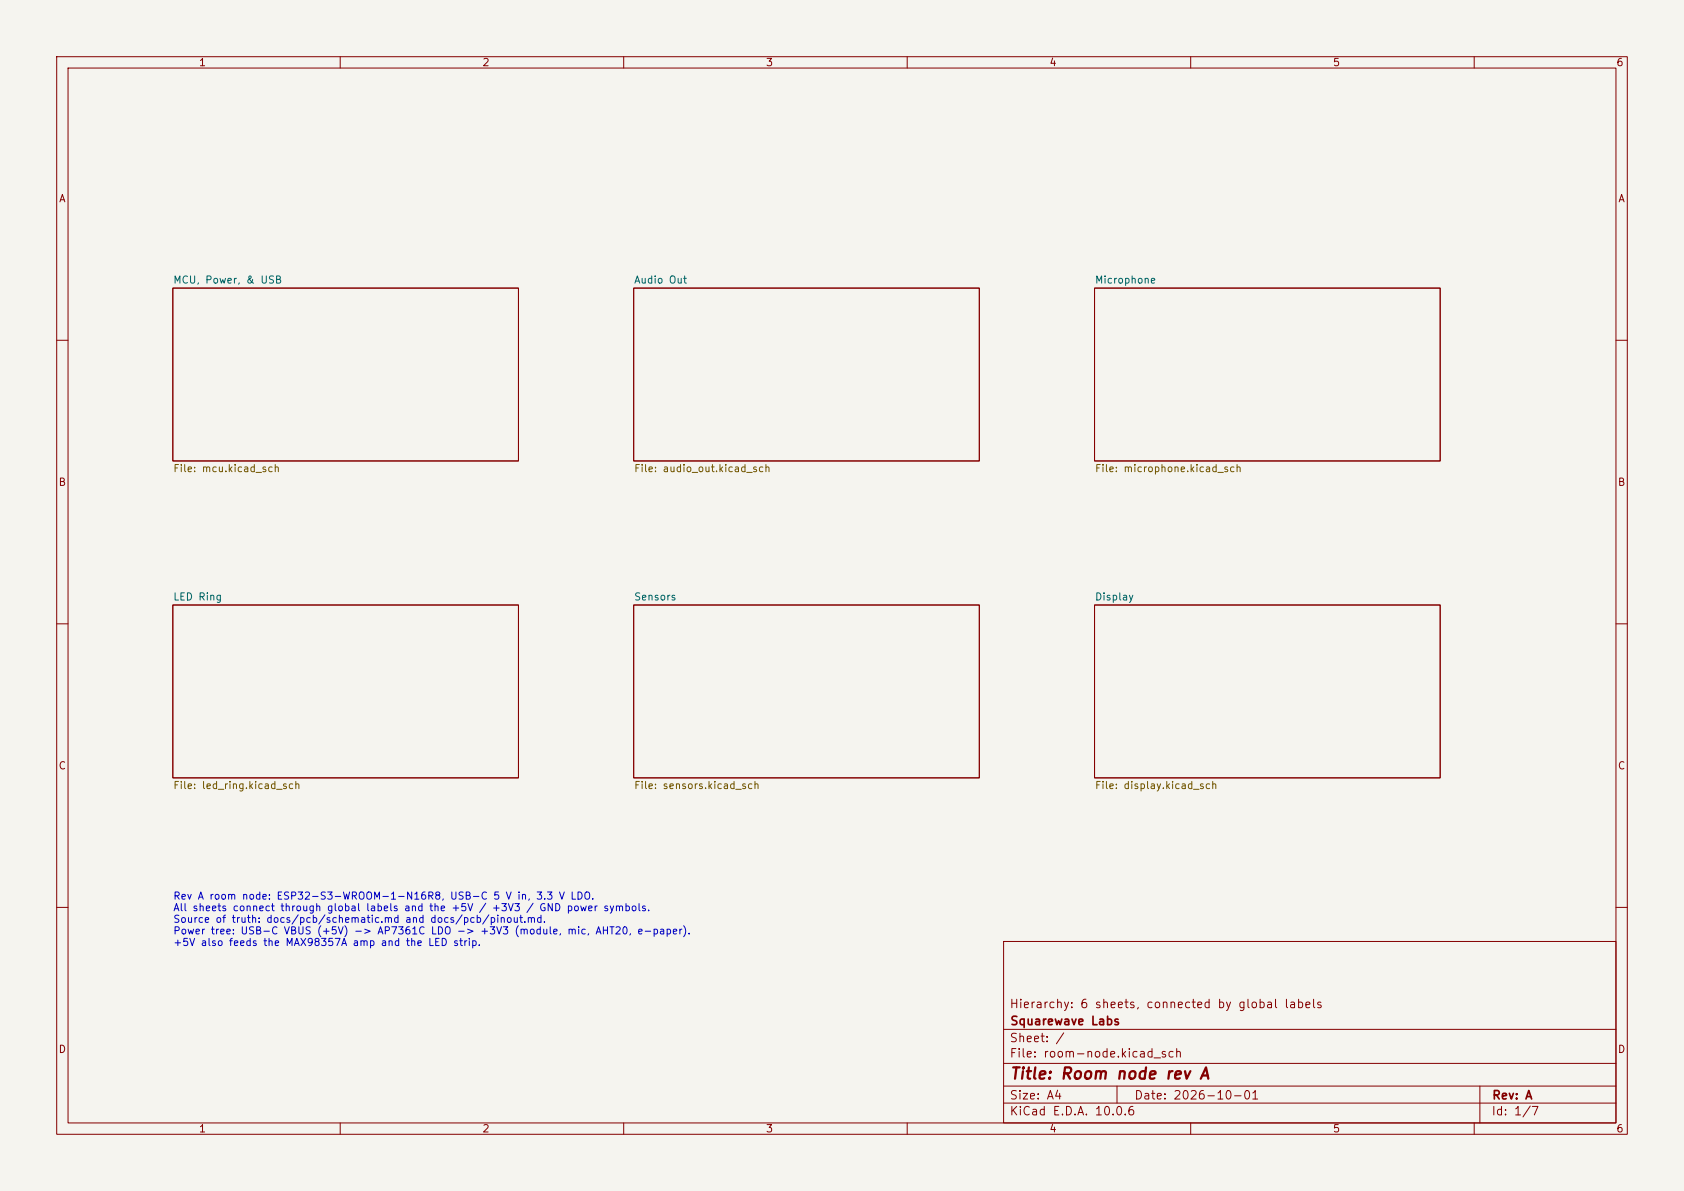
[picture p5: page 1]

Audio Out File: audio_out.kicad_sch MCU, Power, & USB

Hierarchy: 6 sheets, connected by global labels
Squarewave Labs
Sheet: /
File: room-node.kicad_sch
Title: Room node rev A

Size: A4 | Rev: A
KiCad E.D.A. 10.0.6 | Id: 1/7

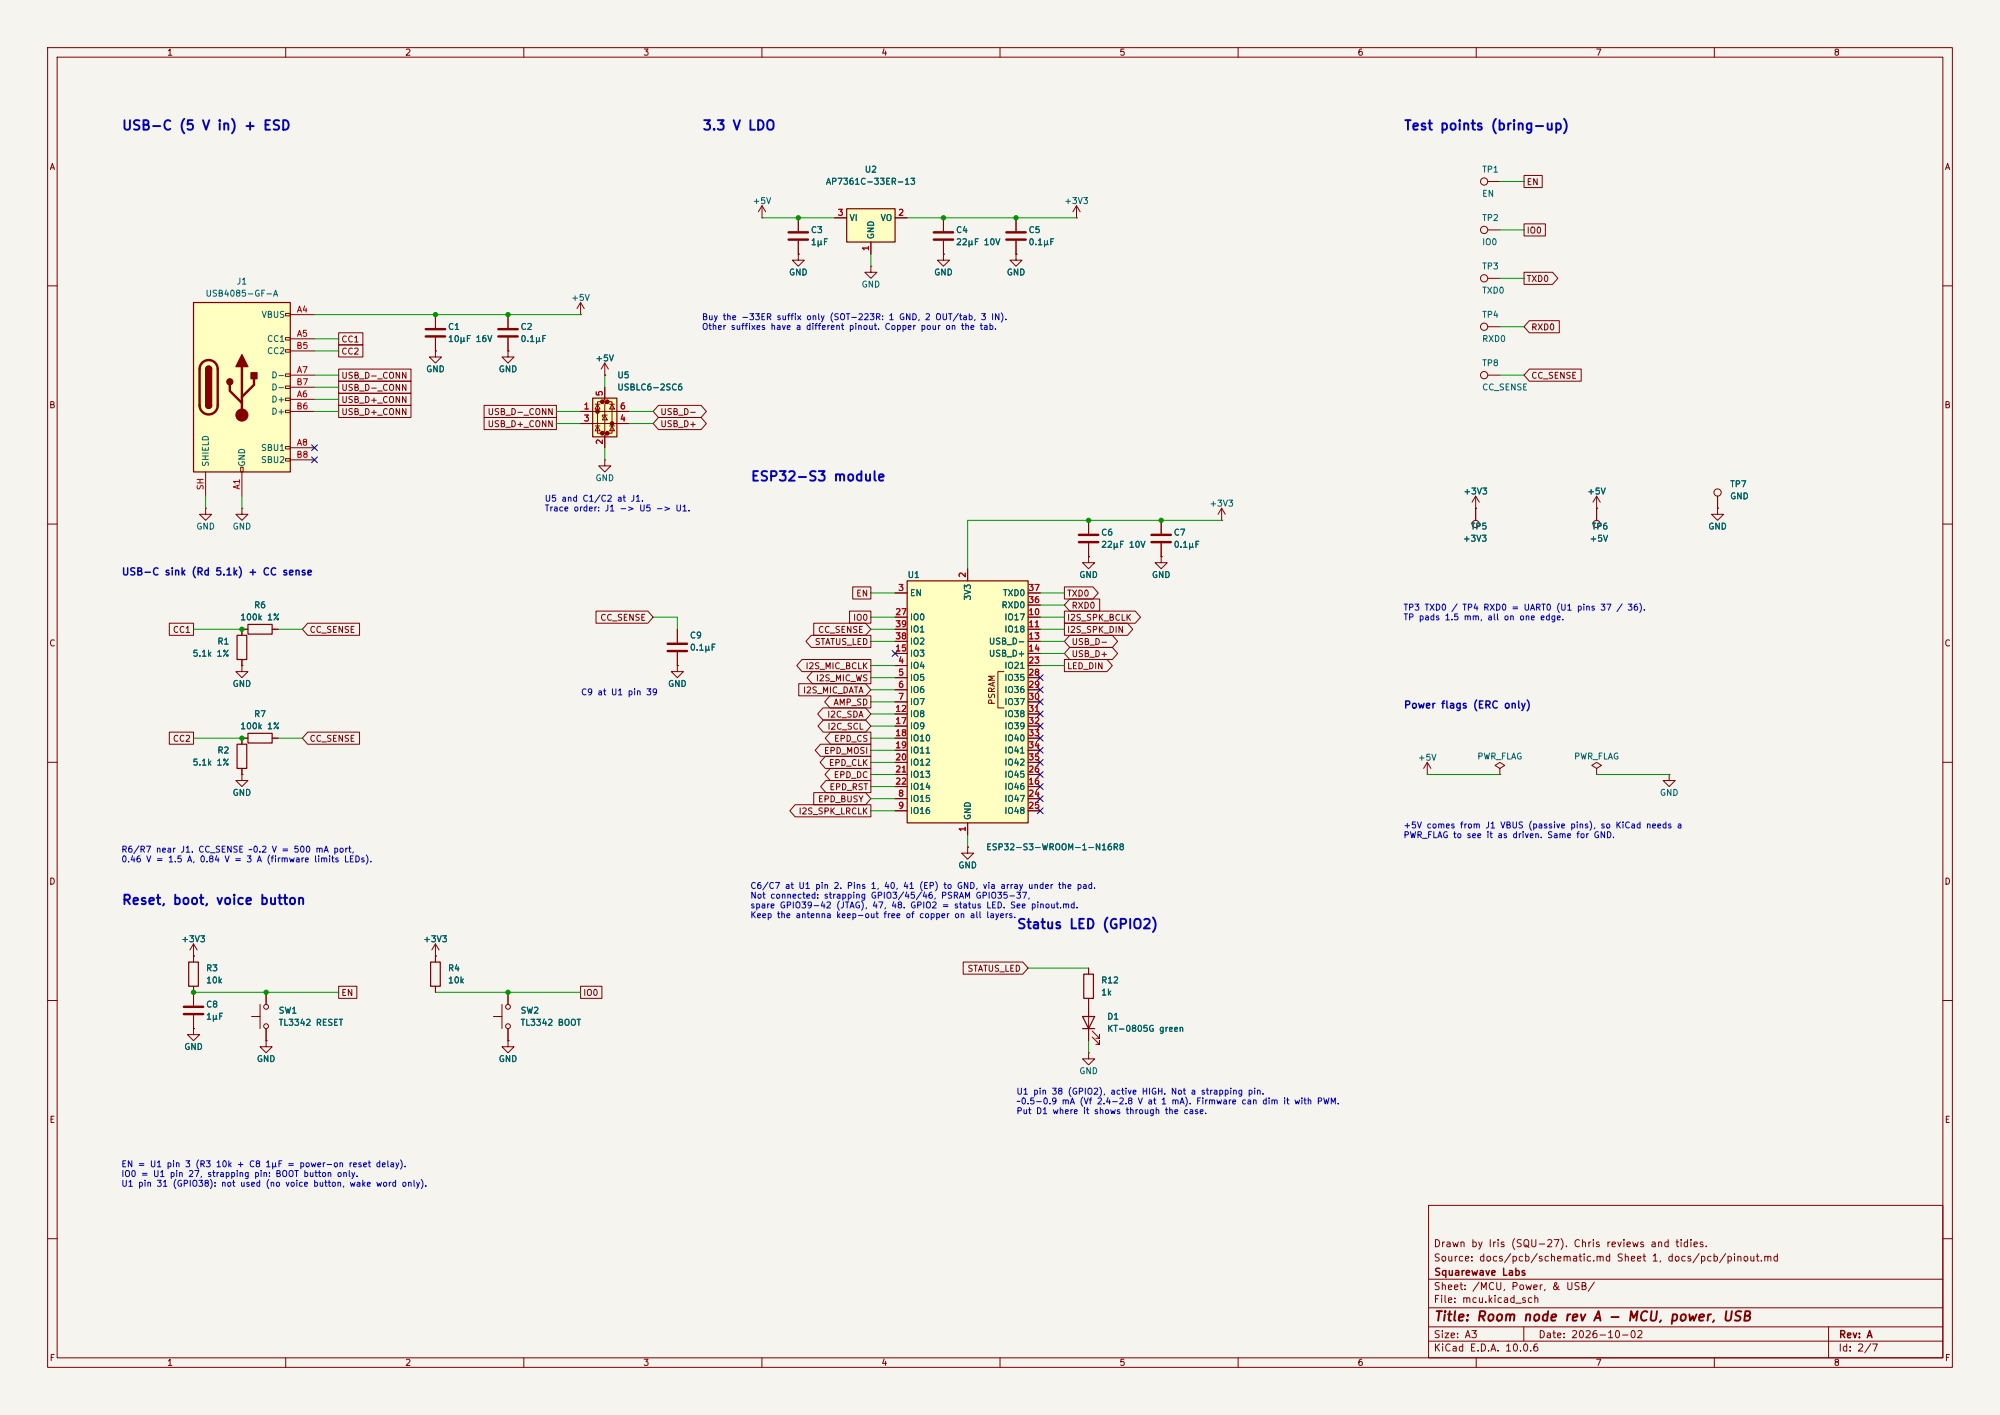
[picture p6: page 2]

Buy the -33ER suffix only (SOT-223R: 1 GND, 2 OUT/tab, 3 IN). Other suffixes have a different pinout. Copper pour on the tab. C6/C7 at U1 pin 2. Pins 1, 40, 41 (EP) to GND, via array under the pad. Not connected: strapping GPIO3/45/46, PSRAM GPIO35-37, spare GPIO39-42 (JTAG), 47, 48. GPIO2 = status LED. See pinout.md.

TP3 TXD0 / TP4 RXD0 = UART0 (U1 pins 37 / 36). TP pads 1.5 mm, all on one edge. R6

U1 pin 38 (GPIO2), active HIGH. Not a strapping pin. ~0.5-0.9 mA (Vf 2.4-2.8 V at 1 mA). Firmware can dim it with PWM. Put D1 where it shows through the case. R6/R7 near J1. CC_SENSE ~0.2 V = 500 mA port, 0.46 V = 1.5 A, 0.84 V = 3 A (firmware limits LEDs).

Reset, boot, voice button

Keep the antenna keep-out free of copper on all layers.

EN = U1 pin 3 (R3 10k + C8 1µF = power-on reset delay).
IO0 = U1 pin 27, strapping pin: BOOT button only. U1 pin 31 (GPIO38): not used (no voice button, wake word only).

Drawn by Iris (SQU-27). Chris reviews and tidies.
Source: docs/pcb/schematic.md Sheet 1, docs/pcb/pinout.md
Squarewave Labs
Sheet: /MCU, Power, & USB/
File: mcu.kicad_sch
Title: Room node rev A - MCU, power, USB

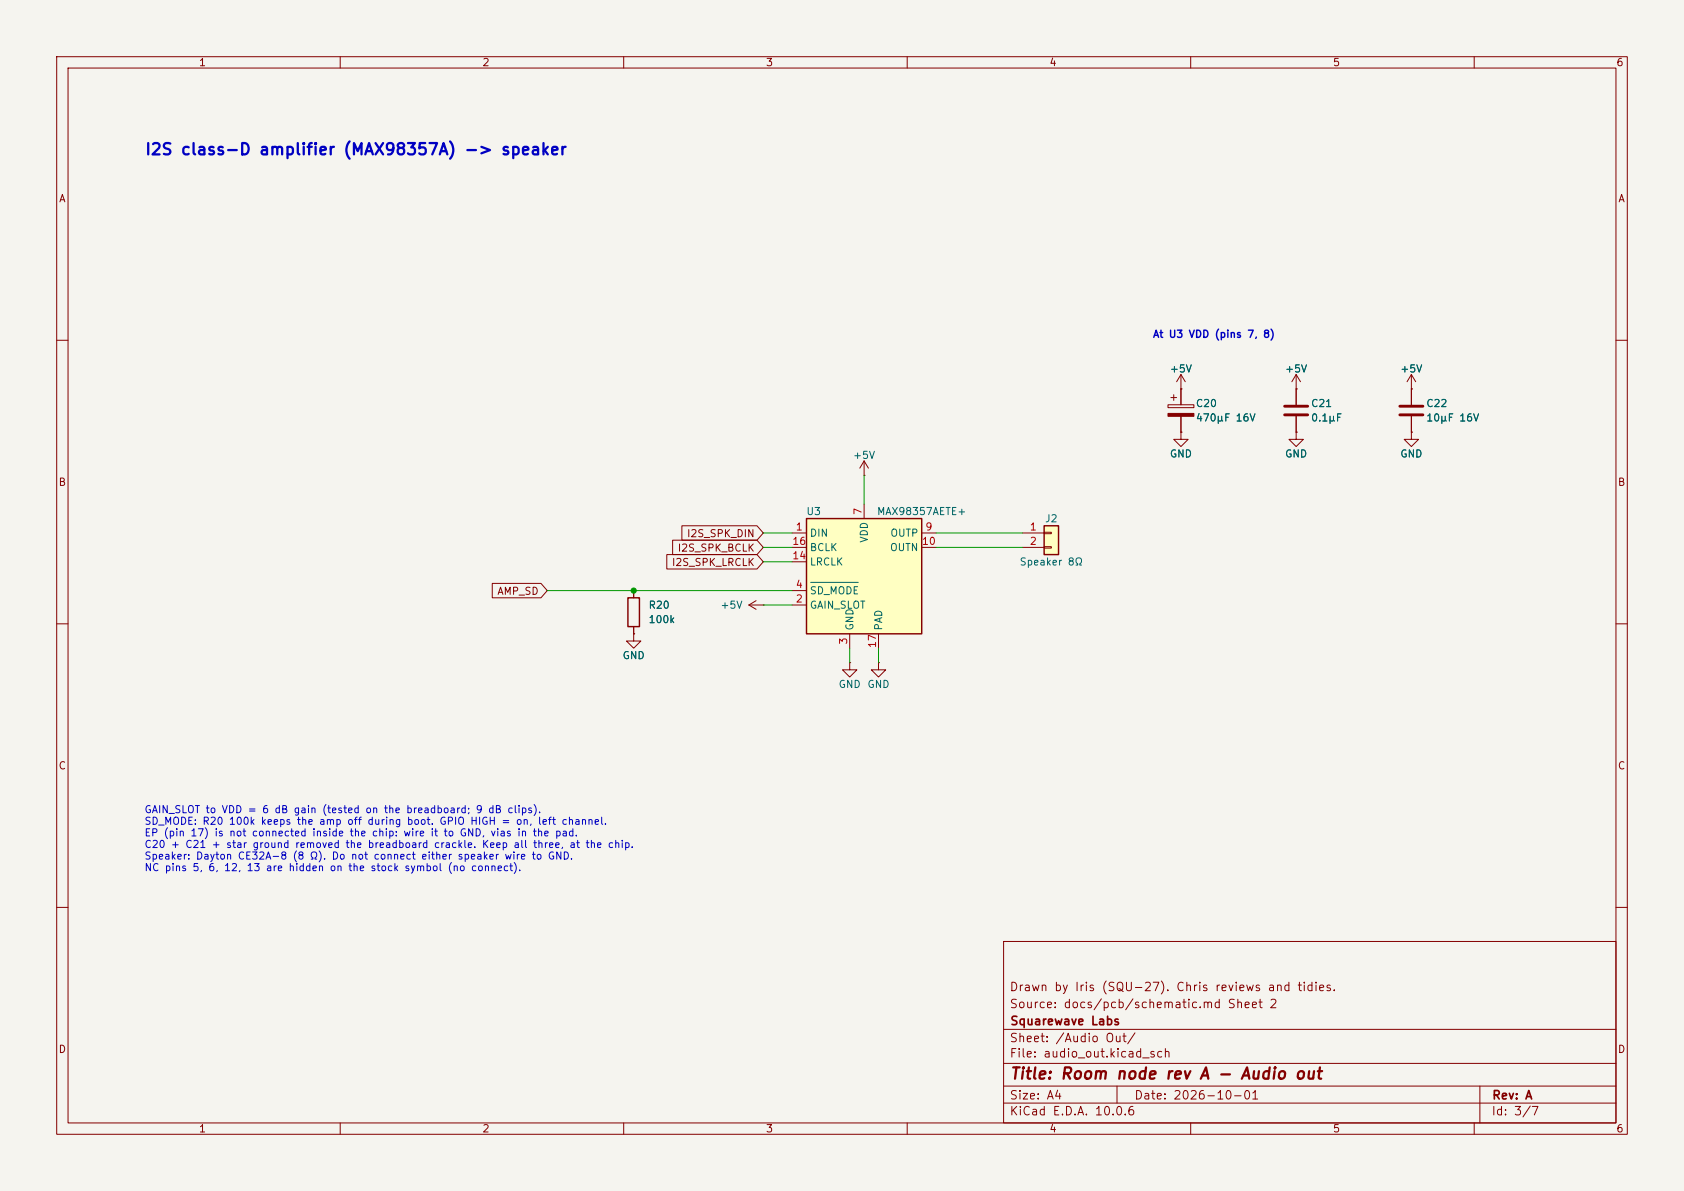
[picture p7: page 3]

At U3 VDD (pins 7, 8) GAIN_SLOT to VDD = 6 dB gain (tested on the breadboard; 9 dB clips). SD_MODE: R20 100k keeps the amp off during boot. GPIO HIGH = on, left channel. EP (pin 17) is not connected inside the chip: wire it to GND, vias in the pad. C20 + C21 + star ground removed the breadboard crackle. Keep all three, at the chip.

Speaker: Dayton CE32A-8 (8 Ω). Do not connect either speaker wire to GND. NC pins 5, 6, 12, 13 are hidden on the stock symbol (no connect).

Source: docs/pcb/schematic.md Sheet 2
Squarewave Labs
Sheet: /Audio Out/
File: audio_out.kicad_sch
Title: Room node rev A - Audio out

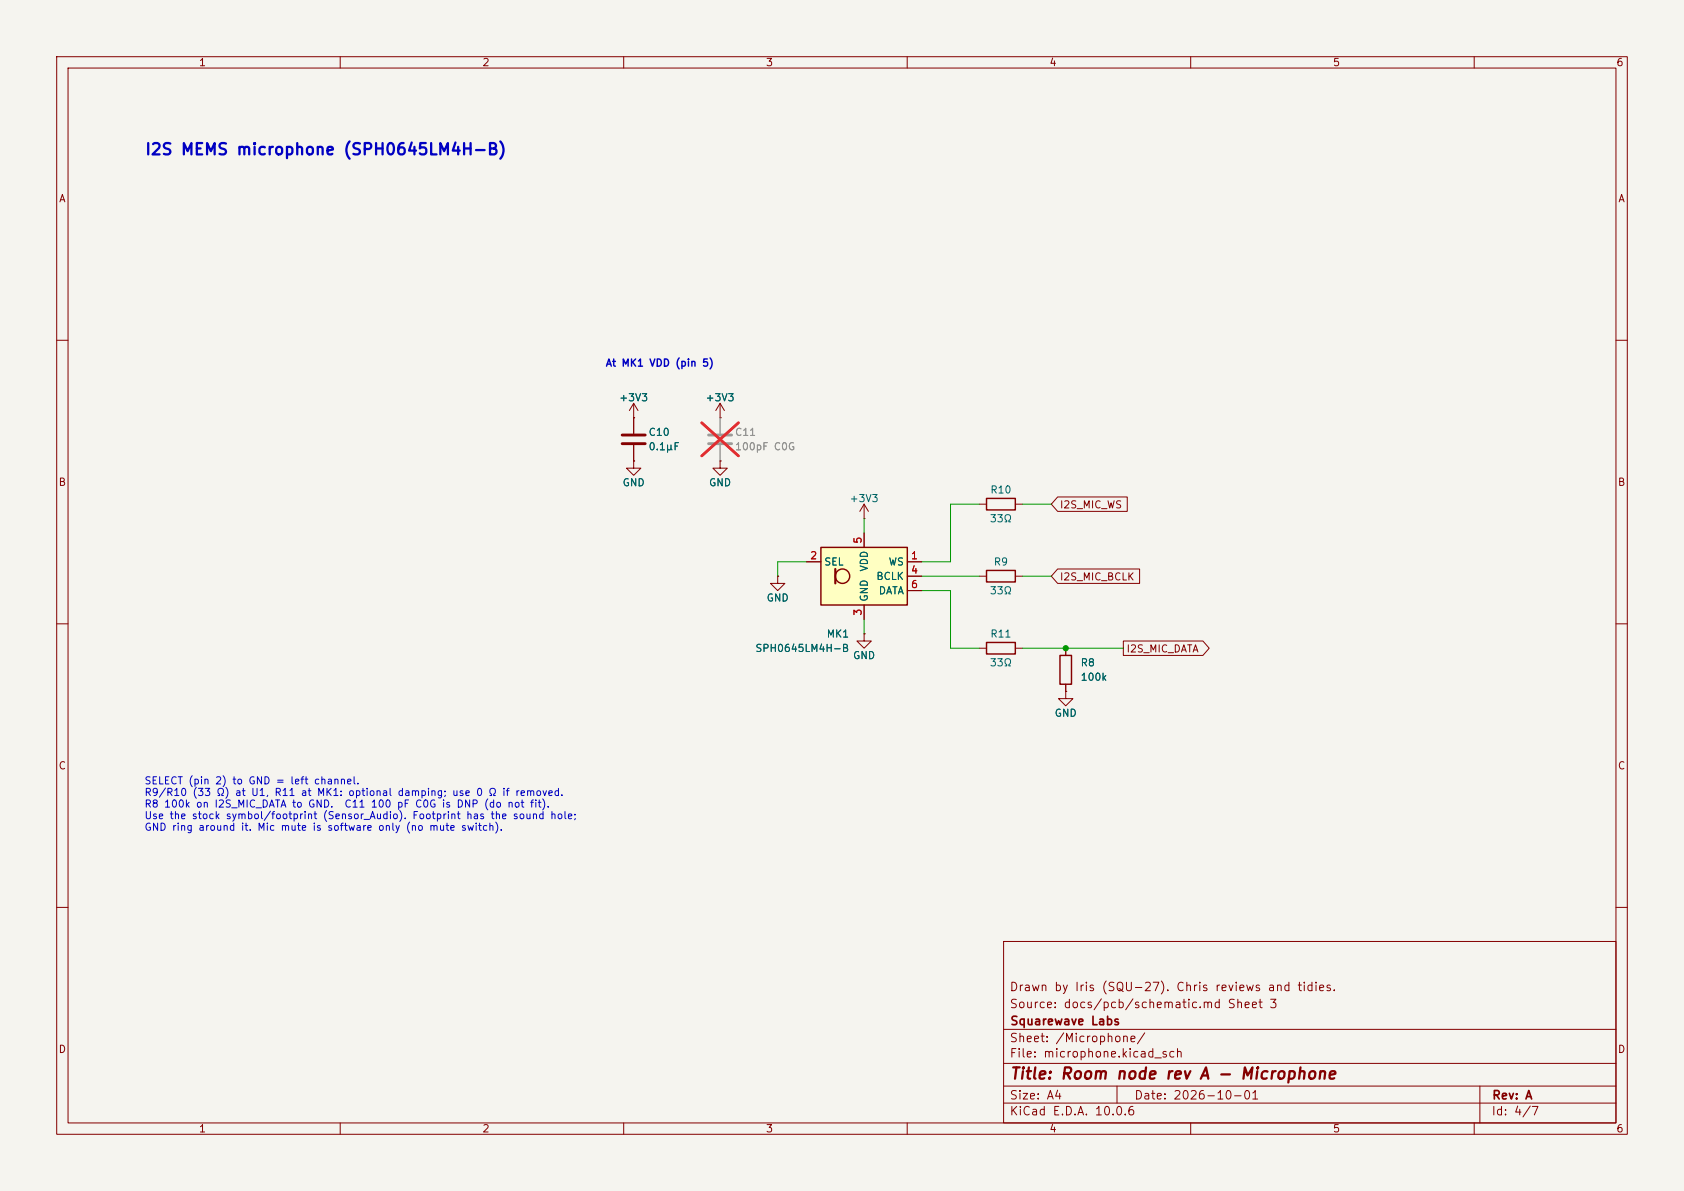
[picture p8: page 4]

I2S_MIC_DATA SELECT (pin 2) to GND = left channel. R9/R10 (33 Ω) at U1, R11 at MK1: optional damping; use 0 Ω if removed. R8 100k on I2S_MIC_DATA to GND. C11 100 pF C0G is DNP (do not fit). Use the stock symbol/footprint (Sensor_Audio). Footprint has the sound hole; GND ring around it. Mic mute is software only (no mute switch).

Source: docs/pcb/schematic.md Sheet 3
Squarewave Labs
Sheet: /Microphone/
File: microphone.kicad_sch
Title: Room node rev A - Microphone

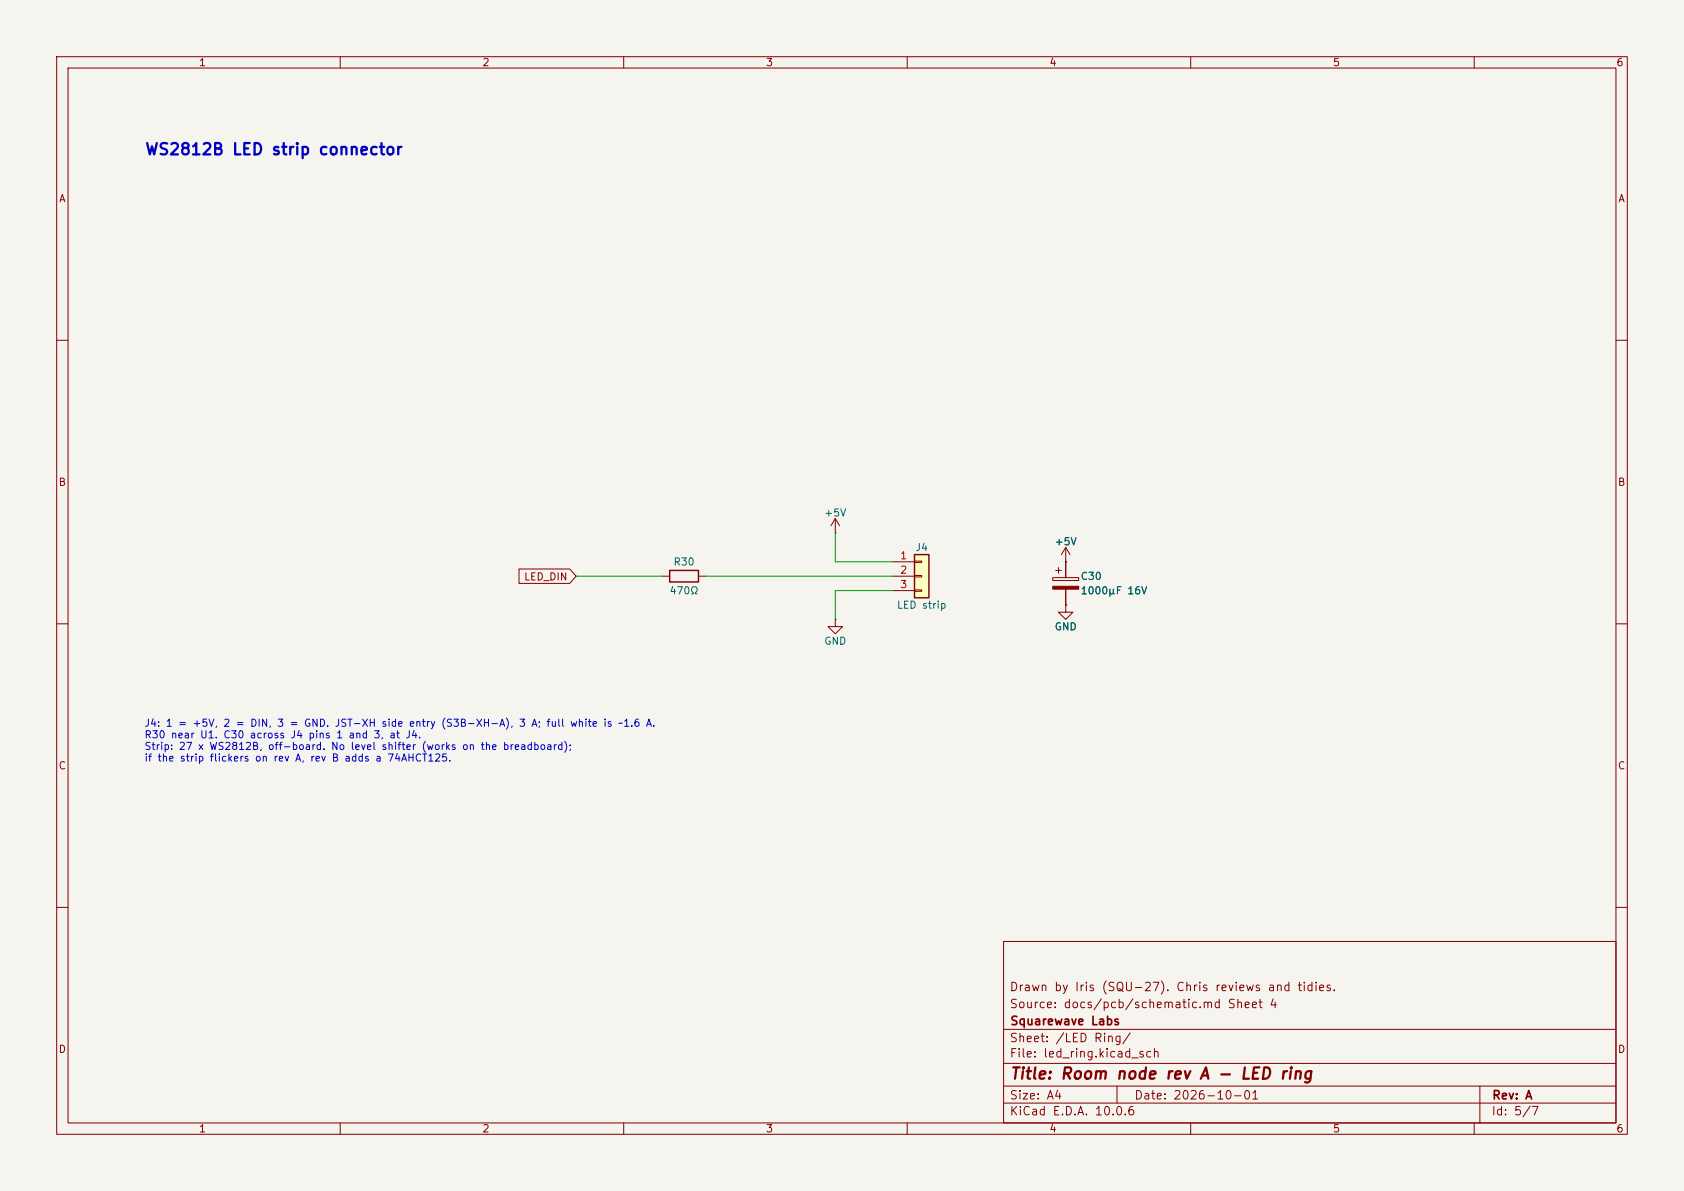
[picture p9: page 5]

Drawn by Iris (SQU-27). Chris reviews and tidies. +5V R30

J4: 1 = +5V, 2 = DIN, 3 = GND. JST-XH side entry (S3B-XH-A), 3 A; full white is ~1.6 A. R30 near U1. C30 across J4 pins 1 and 3, at J4. Strip: 27 x WS2812B, off-board. No level shifter (works on the breadboard);

Source: docs/pcb/schematic.md Sheet 4
Squarewave Labs
Sheet: /LED Ring/
File: led_ring.kicad_sch
Title: Room node rev A - LED ring

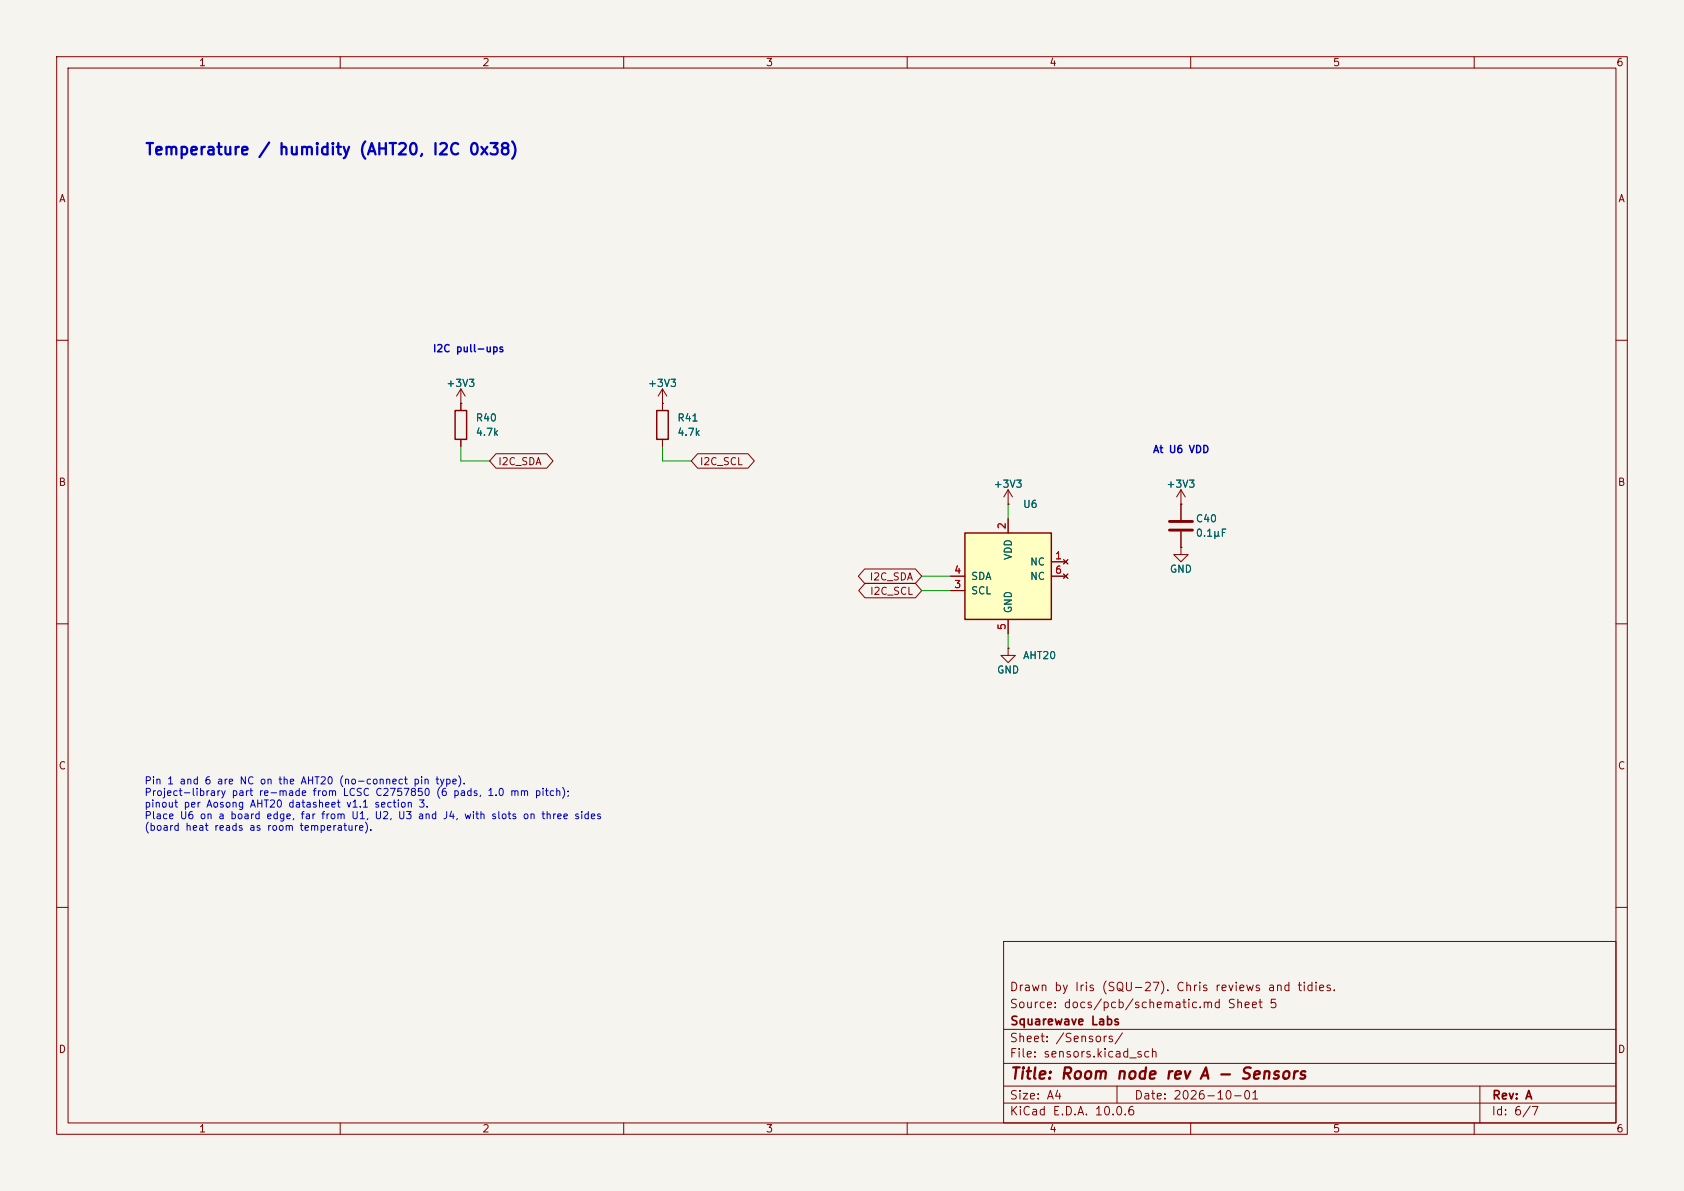
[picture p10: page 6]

Drawn by Iris (SQU-27). Chris reviews and tidies. GND

Pin 1 and 6 are NC on the AHT20 (no-connect pin type).
Project-library part re-made from LCSC C2757850 (6 pads, 1.0 mm pitch);
pinout per Aosong AHT20 datasheet v1.1 section 3. Place U6 on a board edge, far from U1, U2, U3 and J4, with slots on three sides

(board heat reads as room temperature).

Source: docs/pcb/schematic.md Sheet 5
Squarewave Labs
Sheet: /Sensors/
File: sensors.kicad_sch
Title: Room node rev A - Sensors

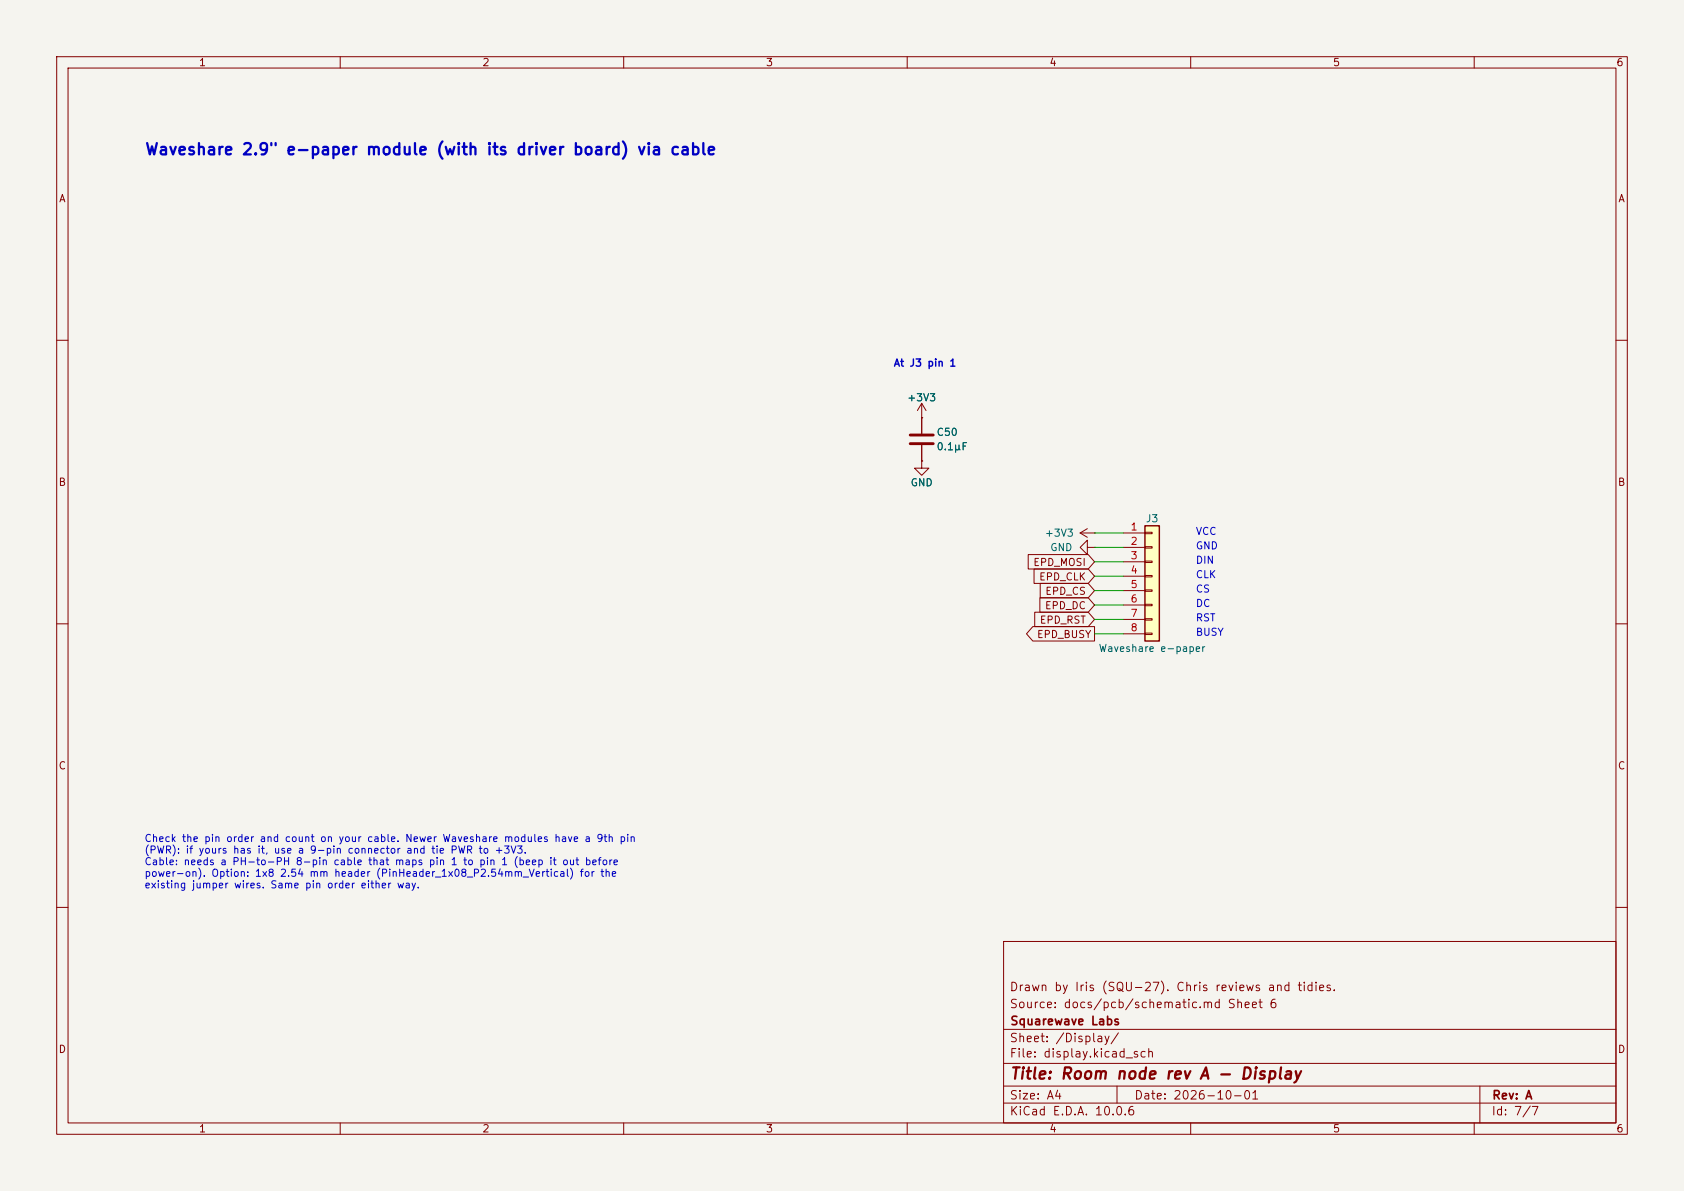
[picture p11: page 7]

existing jumper wires. Same pin order either way. Waveshare 2.9" e-paper module (with its driver board) via cable

EPD_RST EPD_BUSY EPD_MOSI Check the pin order and count on your cable. Newer Waveshare modules have a 9th pin

(PWR): if yours has it, use a 9-pin connector and tie PWR to +3V3. Cable: needs a PH-to-PH 8-pin cable that maps pin 1 to pin 1 (beep it out before power-on). Option: 1x8 2.54 mm header (PinHeader_1x08_P2.54mm_Vertical) for the

Source: docs/pcb/schematic.md Sheet 6
Squarewave Labs
Sheet: /Display/
File: display.kicad_sch
Title: Room node rev A - Display

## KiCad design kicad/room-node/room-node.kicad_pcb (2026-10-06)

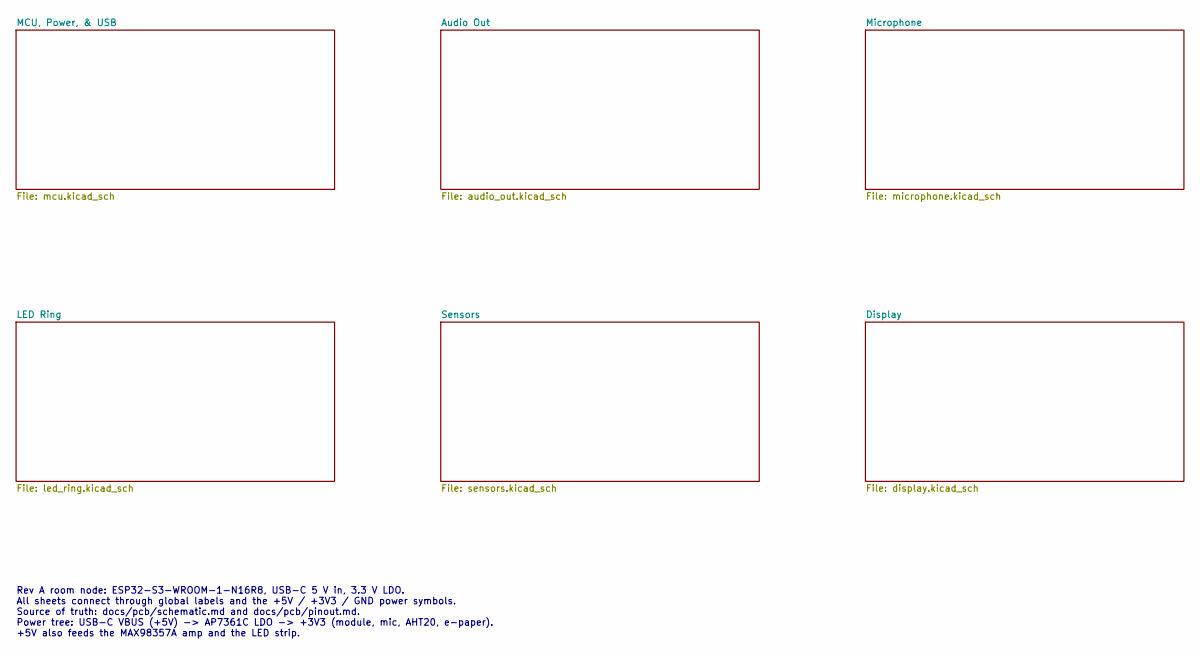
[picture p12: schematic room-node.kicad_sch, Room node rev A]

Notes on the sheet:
Rev A room node: ESP32-S3-WROOM-1-N16R8, USB-C 5 V in, 3.3 V LDO. All sheets connect through global labels and the +5V / +3V3 / GND power symbols. Source of truth: docs/pcb/schematic.md and docs/pcb/pinout.md. Power tree: USB-C VBUS (+5V) -> AP7361C LDO -> +3V3 (module, mic, AHT20, e-paper). +5V al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

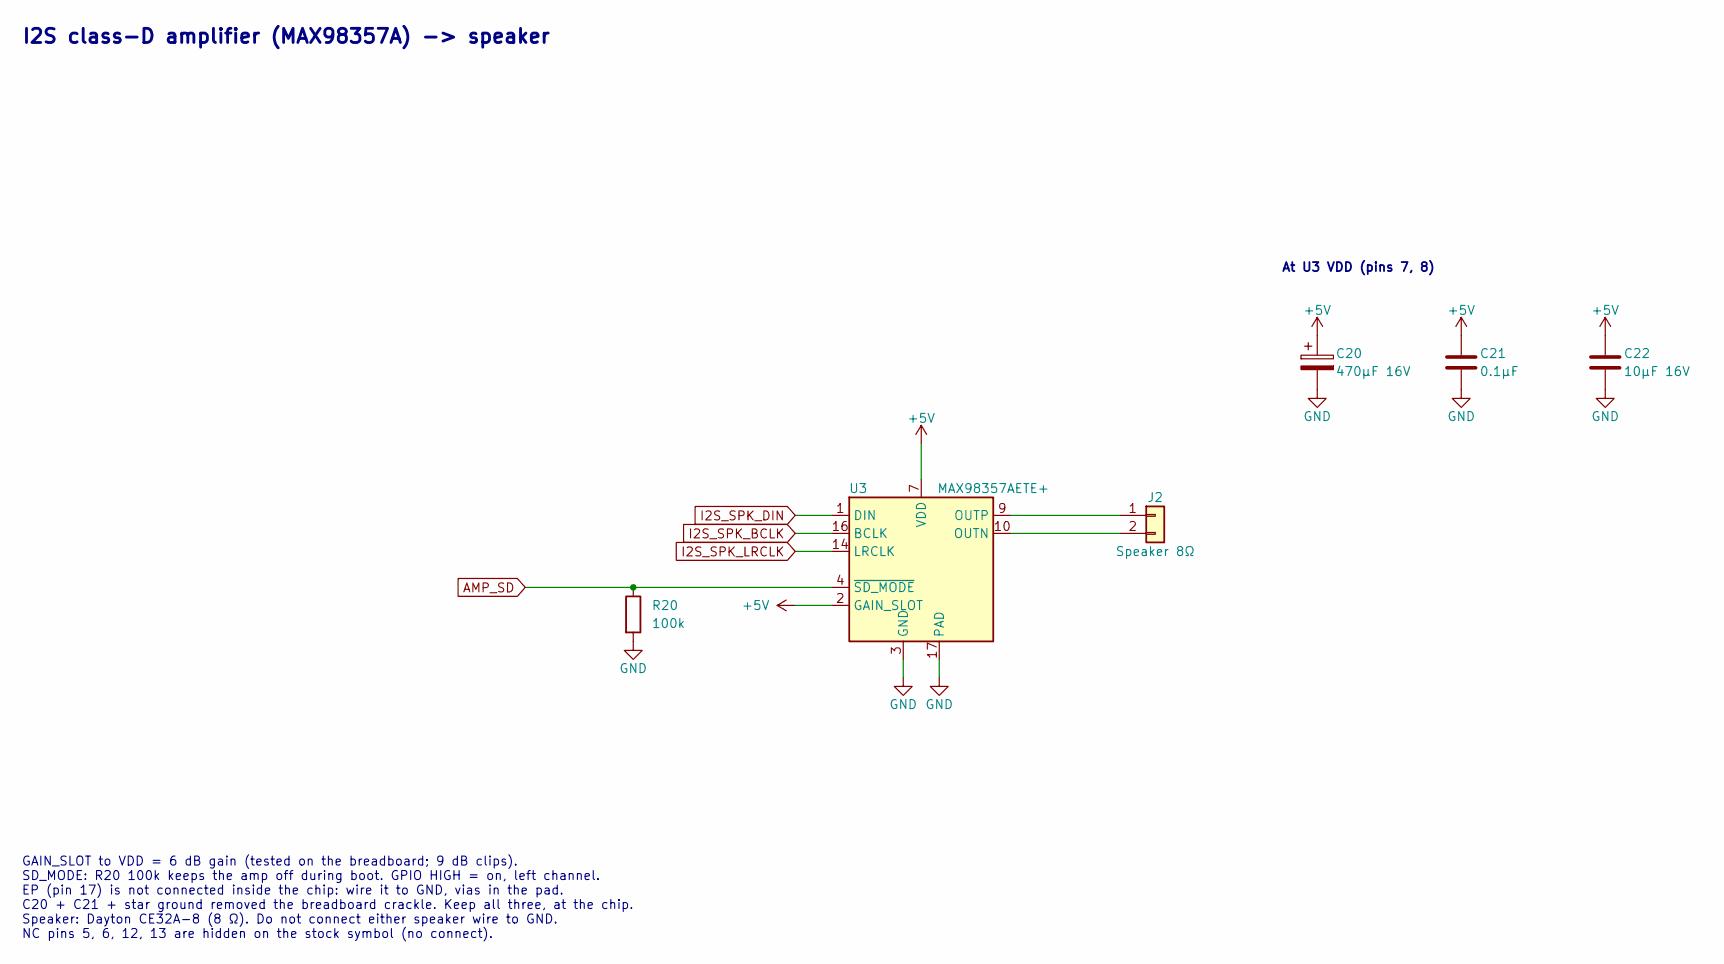
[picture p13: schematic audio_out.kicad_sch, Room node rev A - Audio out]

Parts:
C20: 470µF 16V; CP_Radial_D8.0mm_P3.50mm; MPN SamYoung NXB16V470M8*11.5; LCSC C346937
C21: 0.1µF; C_0603_1608Metric; LCSC C14663
C22: 10µF 16V; C_0805_2012Metric; LCSC C15850
J2: Speaker 8Ω; JST_PH_B2B-PH-SM4-TB_1x02-1MP_P2.00mm_Vertical; MPN JST B2B-PH-SM4-TB(LF)(SN); LCSC C160352
R20: 100k; R_0603_1608Metric; LCSC C25803
U3: MAX98357AETE+; TQFN-16-1EP_3x3mm_P0.5mm_EP1.23x1.23mm; MPN Analog Devices MAX98357AETE+; LCSC TBD

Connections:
+5V: C20.1, C21.1, C22.1, U3.2 (GAIN_SLOT), U3.7 (VDD), U3.8 (VDD); also elsewhere on the board
AMP_SD: R20.1, U3.4 (~SD_MODE); also elsewhere on the board
GND: C20.2, C21.2, C22.2, R20.2, U3.3 (GND), U3.11 (GND), U3.15 (GND), U3.17 (PAD); also elsewhere on the board
I2S_SPK_BCLK: U3.16 (BCLK); also elsewhere on the board
I2S_SPK_DIN: U3.1 (DIN); also elsewhere on the board
I2S_SPK_LRCLK: U3.14 (LRCLK); also elsewhere on the board
unnamed: J2.1, U3.9 (OUTP)
unnamed: J2.2, U3.10 (OUTN)

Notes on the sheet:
I2S class-D amplifier (MAX98357A) -> speaker
At U3 VDD (pins 7, 8)
GAIN_SLOT to VDD = 6 dB gain (tested on the breadboard; 9 dB clips). SD_MODE: R20 100k keeps the amp off during boot. GPIO HIGH = on, left channel. EP (pin 17) is not connected inside the chip: wire it to GND, vias in the pad. C20 + C21 + star ground removed the breadboard crackle. Keep all three, 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

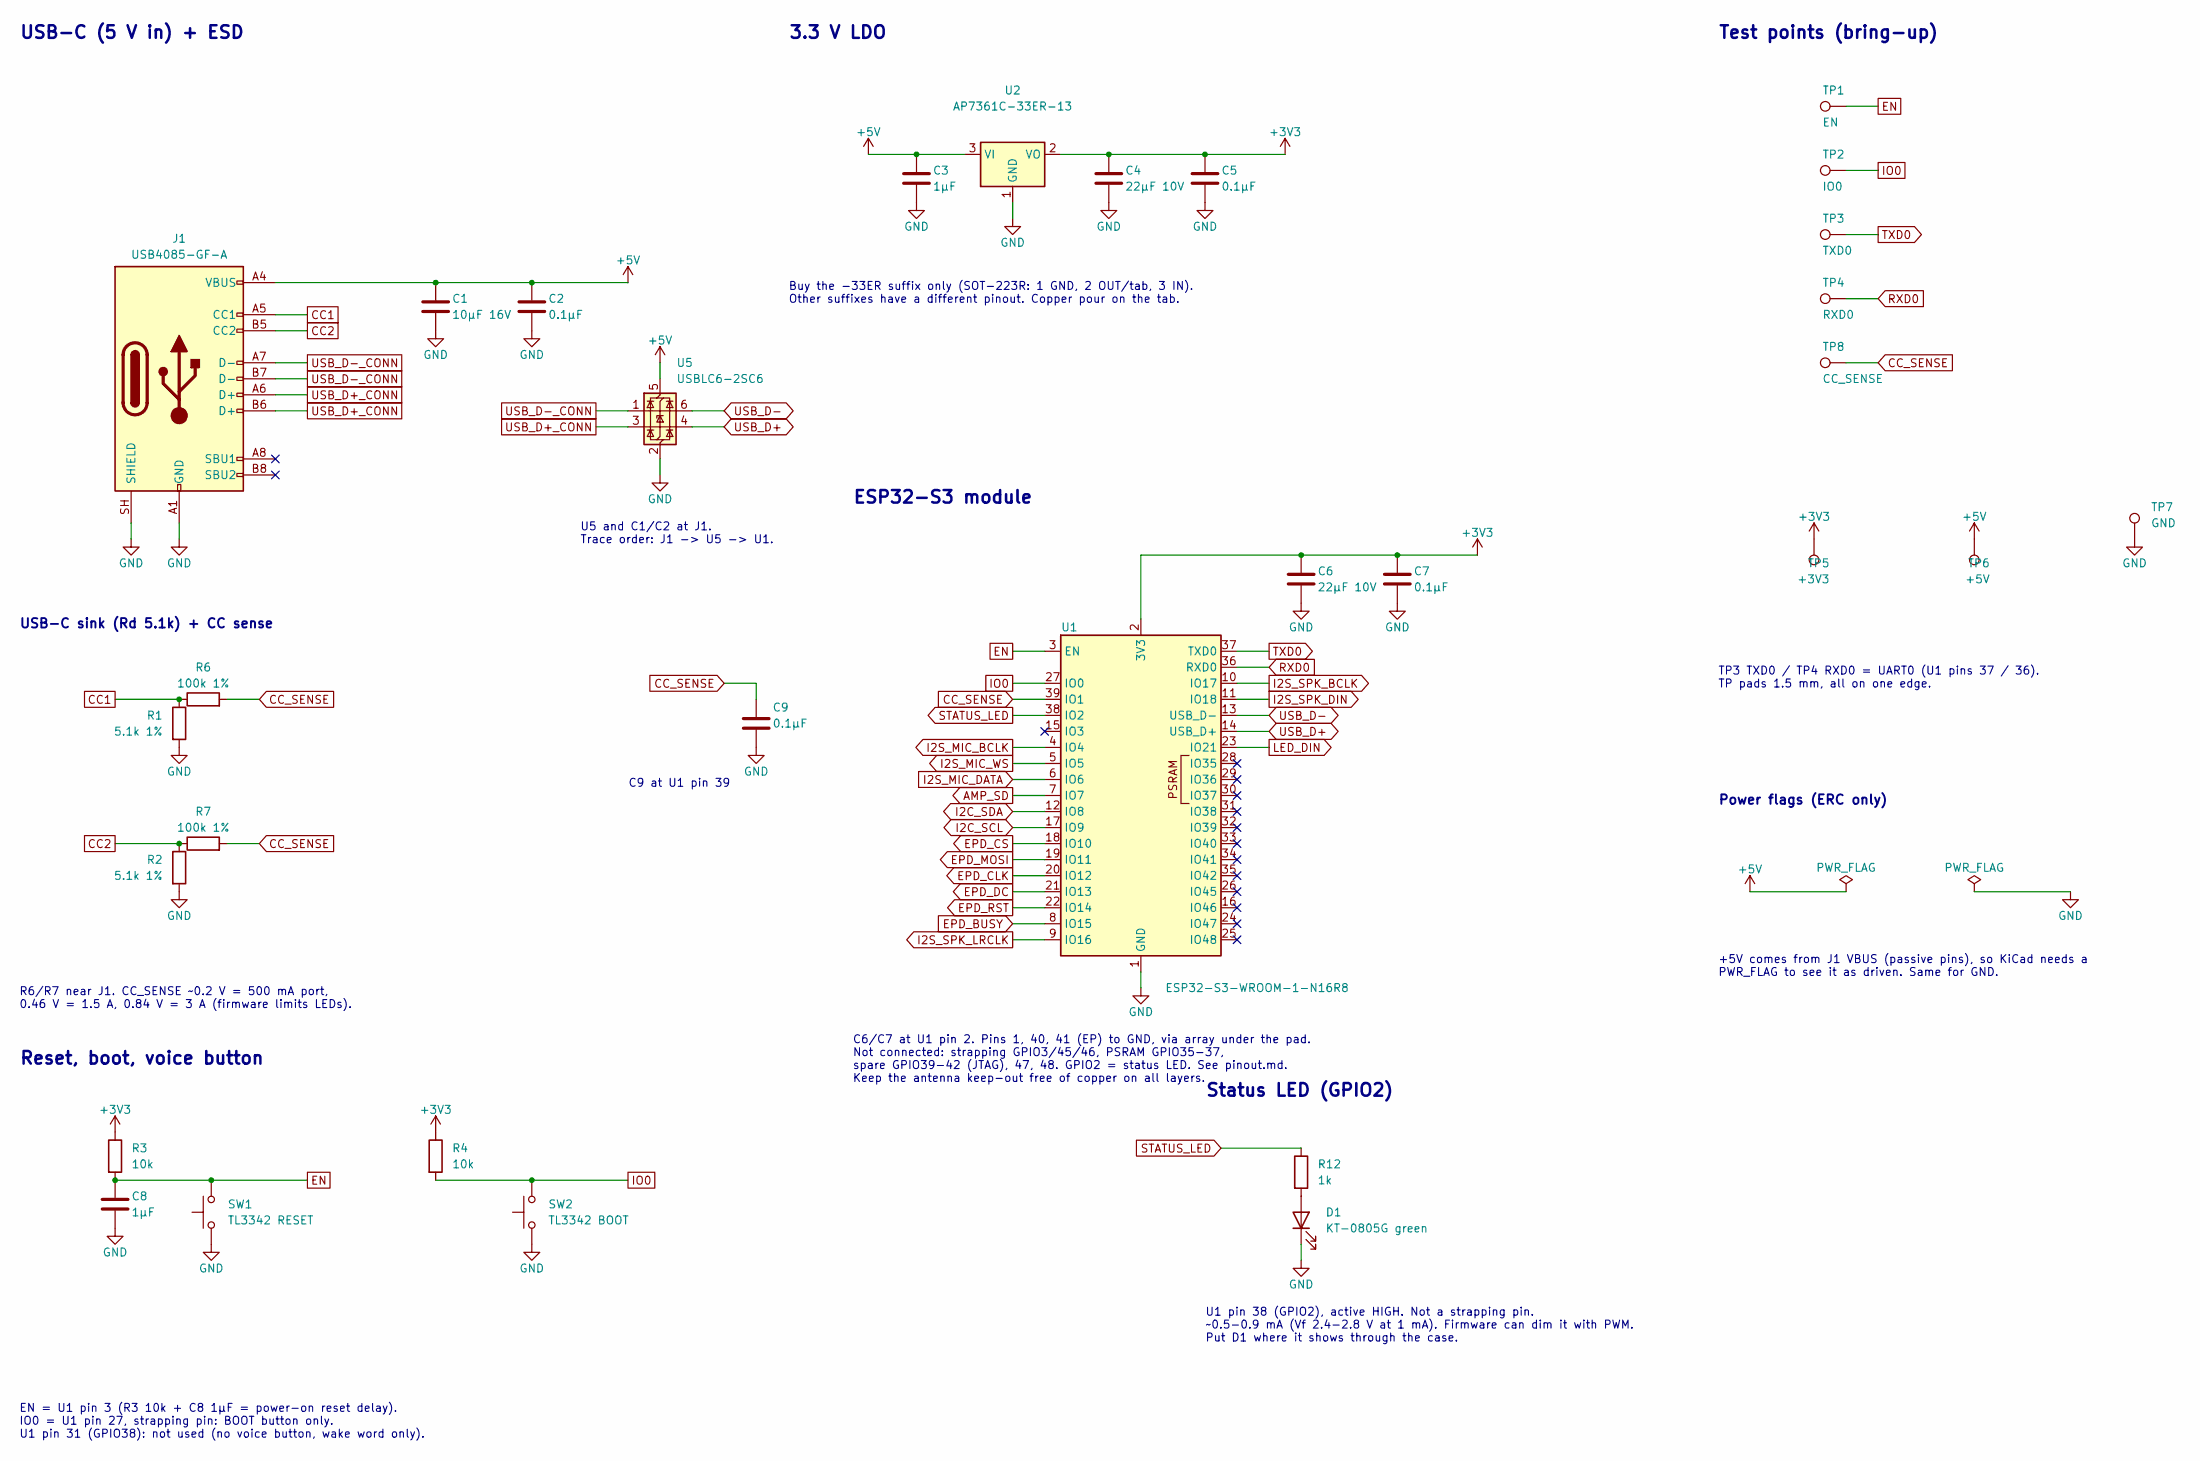
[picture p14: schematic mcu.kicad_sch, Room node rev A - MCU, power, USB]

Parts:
C1: 10µF 16V; C_0805_2012Metric; LCSC C15850
C2, C5, C7, C9: 0.1µF; C_0603_1608Metric; LCSC C14663
C3, C8: 1µF; C_0603_1608Metric; LCSC C15849
C4, C6: 22µF 10V; C_0805_2012Metric; LCSC C45783
D1: KT-0805G green; LED_0805_2012Metric; MPN KT-0805G; LCSC C2297
J1: USB4085-GF-A; USB_C_Receptacle_GCT_USB4085; MPN GCT USB4085-GF-A; LCSC TBD
R1, R2: 5.1k 1%; R_0603_1608Metric; LCSC C23186
R3, R4: 10k; R_0603_1608Metric; LCSC C25804
R6, R7: 100k 1%; R_0603_1608Metric; LCSC C25803
R12: 1k; R_0603_1608Metric; LCSC C21190
SW1: TL3342 RESET; SW_SPST_TL3342; MPN E-Switch TL3342F160QG; LCSC TBD
SW2: TL3342 BOOT; SW_SPST_TL3342; MPN E-Switch TL3342F160QG; LCSC TBD
TP1: EN; TestPoint_Pad_D1.5mm
TP2: IO0; TestPoint_Pad_D1.5mm
TP3: TXD0; TestPoint_Pad_D1.5mm
TP4: RXD0; TestPoint_Pad_D1.5mm
TP5: +3V3; TestPoint_Pad_D1.5mm
TP6: +5V; TestPoint_Pad_D1.5mm
TP7: GND; TestPoint_Pad_D1.5mm
TP8: CC_SENSE; TestPoint_Pad_D1.5mm
U1: ESP32-S3-WROOM-1-N16R8; ESP32-S3-WROOM-1; MPN Espressif ESP32-S3-WROOM-1-N16R8; LCSC TBD
U2: AP7361C-33ER-13; SOT-223-3_TabPin2; MPN Diodes AP7361C-33ER-13; LCSC TBD
U5: USBLC6-2SC6; SOT-23-6; MPN ST USBLC6-2SC6; LCSC TBD

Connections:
+3V3: C4.1, C5.1, C6.1, C7.1, R3.1, R4.1, TP5.1, U1.2 (3V3), U2.2 (VO); also elsewhere on the board
+5V: C1.1, C2.1, C3.1, J1.A4 (VBUS), J1.A9 (VBUS), J1.B4 (VBUS), J1.B9 (VBUS), TP6.1, U2.3 (VI), U5.5 (VBUS); also elsewhere on the board
AMP_SD: U1.7 (IO7); also elsewhere on the board
CC1: J1.A5 (CC1), R1.1, R6.1
CC2: J1.B5 (CC2), R2.1, R7.1
CC_SENSE: C9.1, R6.2, R7.2, TP8.1, U1.39 (IO1)
EN: C8.1, R3.2, SW1.2, TP1.1, U1.3 (EN)
EPD_BUSY: U1.8 (IO15); also elsewhere on the board
EPD_CLK: U1.20 (IO12); also elsewhere on the board
EPD_CS: U1.18 (IO10); also elsewhere on the board
EPD_DC: U1.21 (IO13); also elsewhere on the board
EPD_MOSI: U1.19 (IO11); also elsewhere on the board
EPD_RST: U1.22 (IO14); also elsewhere on the board
GND: C1.2, C2.2, C3.2, C4.2, C5.2, C6.2, C7.2, C8.2, C9.2, D1.1 (K), J1.A1 (GND), J1.A12 (GND), J1.B1 (GND), J1.B12 (GND), J1.SH (SHIELD), R1.2, R2.2, SW1.1, SW2.1, TP7.1, U1.1 (GND), U1.40 (GND), U1.41 (GND), U2.1 (GND), U5.2 (GND); also elsewhere on the board
I2C_SCL: U1.17 (IO9); also elsewhere on the board
I2C_SDA: U1.12 (IO8); also elsewhere on the board
I2S_MIC_BCLK: U1.4 (IO4); also elsewhere on the board
I2S_MIC_DATA: U1.6 (IO6); also elsewhere on the board
I2S_MIC_WS: U1.5 (IO5); also elsewhere on the board
I2S_SPK_BCLK: U1.10 (IO17); also elsewhere on the board
I2S_SPK_DIN: U1.11 (IO18); also elsewhere on the board
I2S_SPK_LRCLK: U1.9 (IO16); also elsewhere on the board
IO0: R4.2, SW2.2, TP2.1, U1.27 (IO0)
LED_DIN: U1.23 (IO21); also elsewhere on the board
unnamed: D1.2 (A), R12.2
RXD0: TP4.1, U1.36 (RXD0)
STATUS_LED: R12.1, U1.38 (IO2)
TXD0: TP3.1, U1.37 (TXD0)
USB_D+: U1.14 (USB_D+), U5.4 (I/O2)
USB_D+_CONN: J1.A6 (D+), J1.B6 (D+), U5.3 (I/O2)
USB_D-: U1.13 (USB_D-), U5.6 (I/O1)
USB_D-_CONN: J1.A7 (D-), J1.B7 (D-), U5.1 (I/O1)

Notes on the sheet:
USB-C (5 V in) + ESD
U5 and C1/C2 at J1. Trace order: J1 -> U5 -> U1.
USB-C sink (Rd 5.1k) + CC sense
R6/R7 near J1. CC_SENSE ~0.2 V = 500 mA port, 0.46 V = 1.5 A, 0.84 V = 3 A (firmware limits LEDs).
3.3 V LDO
Buy the -33ER suffix only (SOT-223R: 1 GND, 2 OUT/tab, 3 IN). Other suffixes have a different pinout. Copper pour on the tab.
ESP32-S3 module
C6/C7 at U1 pin 2. Pins 1, 40, 41 (EP) to GND, via array under the pad. Not connected: strapping GPIO3/45/46, PSRAM GPIO35-37, spare GPIO39-42 (JTAG), 47, 48. GPIO2 = status LED. See pinout.md. Keep the antenna keep-out free of copper on all layers.
C9 at U1 pin 39
Reset, boot, voice button
EN = U1 pin 3 (R3 10k + C8 1µF = power-on reset delay). IO0 = U1 pin 27, strapping pin: BOOT button only. U1 pin 31 (GPIO38): not used (no voice button, wake word only).
Test points (bring-up)
TP3 TXD0 / TP4 RXD0 = UART0 (U1 pins 37 / 36). TP pads 1.5 mm, all on one edge.
Power flags (ERC only)
+5V comes from J1 VBUS (passive pins), so KiCad needs a PWR_FLAG to see it as driven. Same for GND.
Status LED (GPIO2)
U1 pin 38 (GPIO2), active HIGH. Not a strapping pin. ~0.5-0.9 mA (Vf 2.4-2.8 V at 1 mA). Firmware can dim it with PWM. Put D1 where it shows through the case.

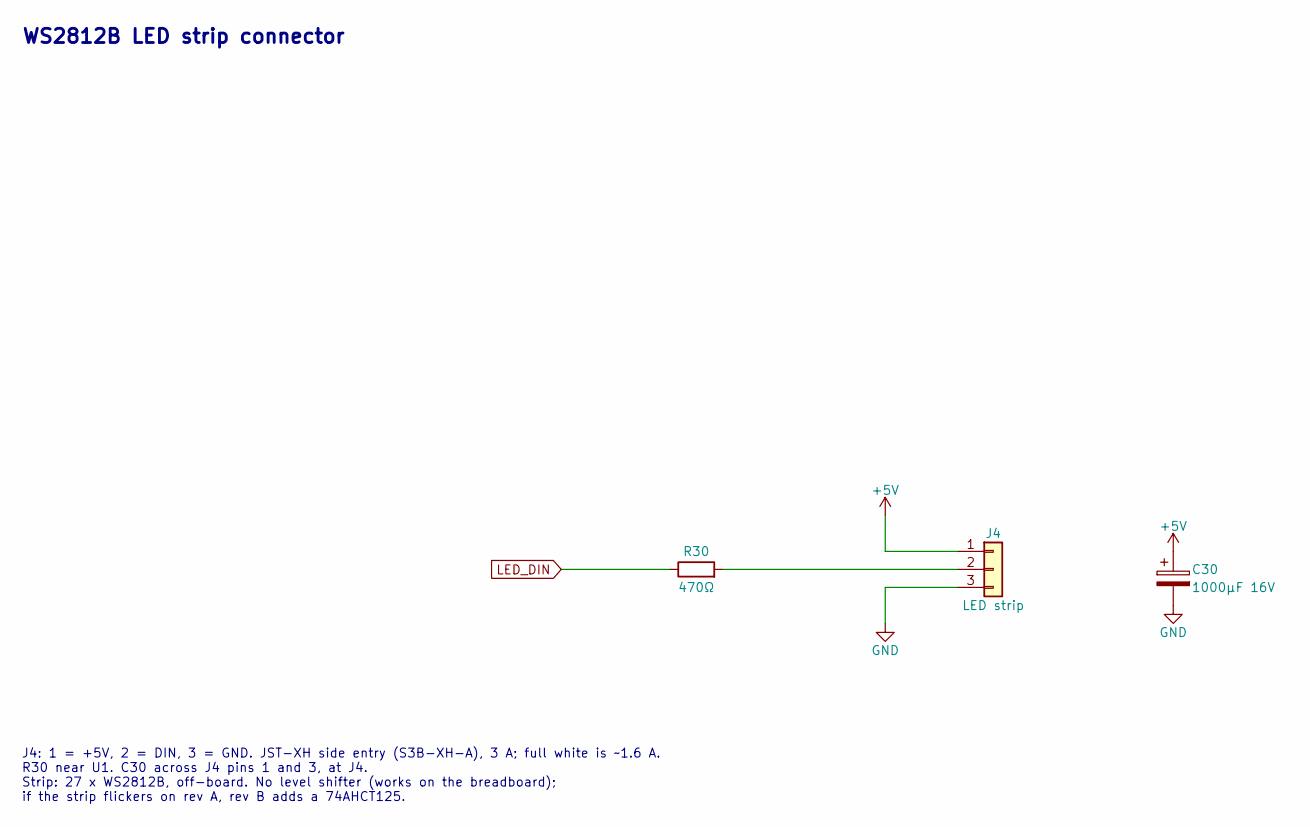
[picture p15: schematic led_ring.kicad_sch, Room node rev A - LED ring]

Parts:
C30: 1000µF 16V; CP_Radial_D10.0mm_P5.00mm; MPN SamYoung NHA16V1000M10*16; LCSC C2835709
J4: LED strip; JST_XH_S3B-XH-A_1x03_P2.50mm_Horizontal; MPN JST S3B-XH-A(LF)(SN); LCSC C157928
R30: 470Ω; R_0603_1608Metric; LCSC C23179

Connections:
+5V: C30.1, J4.1; also elsewhere on the board
GND: C30.2, J4.3; also elsewhere on the board
LED_DIN: R30.1; also elsewhere on the board
unnamed: J4.2, R30.2

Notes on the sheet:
WS2812B LED strip connector
J4: 1 = +5V, 2 = DIN, 3 = GND. JST-XH side entry (S3B-XH-A), 3 A; full white is ~1.6 A. R30 near U1. C30 across J4 pins 1 and 3, at J4. Strip: 27 x WS2812B, off-board. No level shifter (works on the breadboard); if the strip flickers on rev A, rev B adds a 74AHCT125.

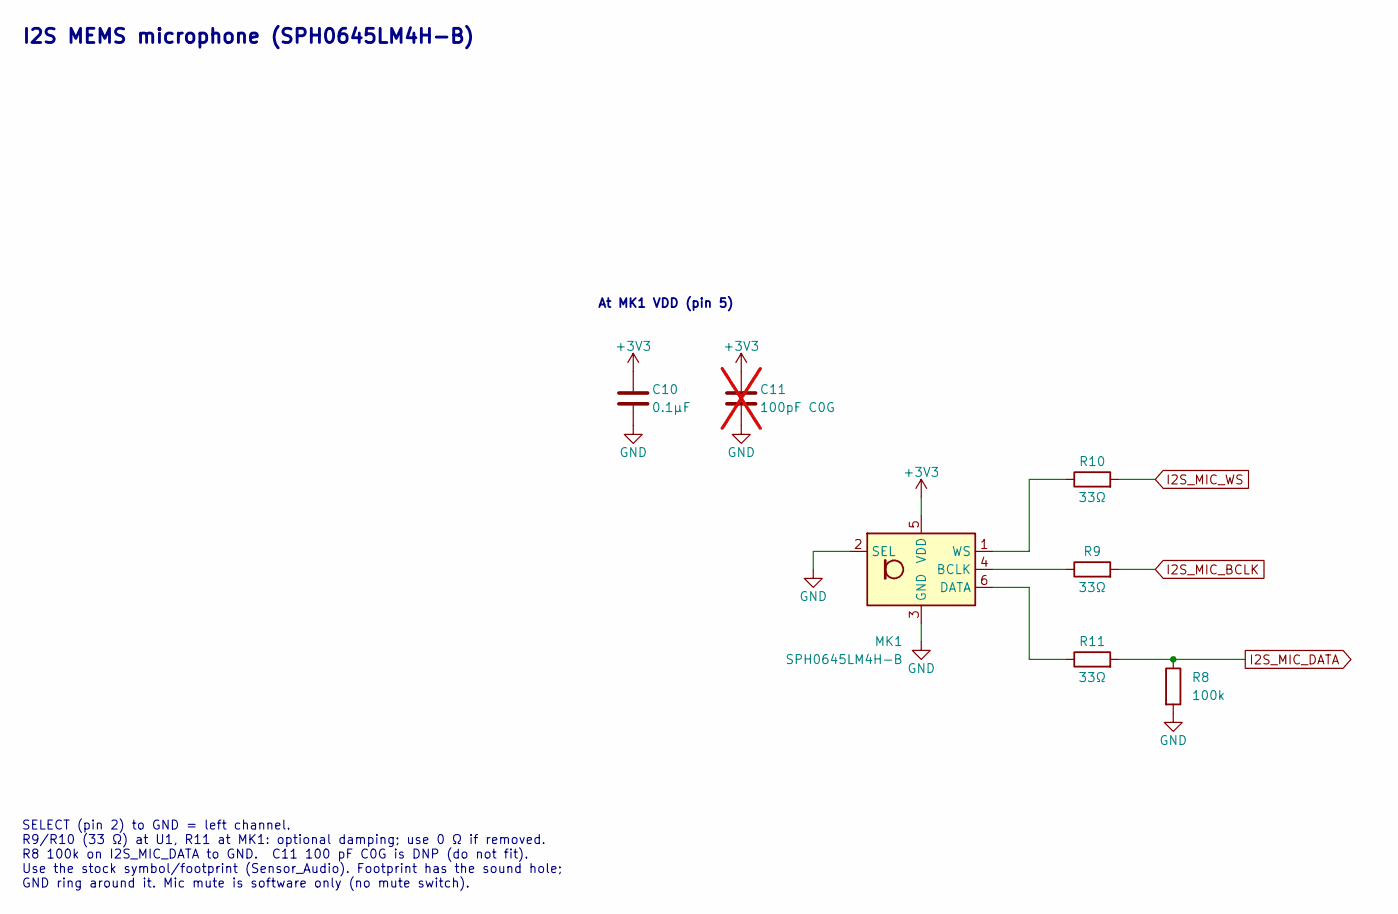
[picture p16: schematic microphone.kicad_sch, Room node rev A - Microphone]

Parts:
C10: 0.1µF; C_0603_1608Metric; LCSC C14663
C11: 100pF C0G; C_0603_1608Metric; LCSC C14858; not fitted
MK1: SPH0645LM4H-B; Knowles_SPH0645LM4H-6_3.5x2.65mm; MPN Knowles/Syntiant SPH0645LM4H-B; LCSC TBD
R8: 100k; R_0603_1608Metric; LCSC C25803
R9, R10, R11: 33Ω; R_0603_1608Metric; MPN Uniroyal 0603WAF330JT5E; LCSC C23140

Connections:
+3V3: C10.1, C11.1, MK1.5 (VDD); also elsewhere on the board
GND: C10.2, C11.2, MK1.2 (SEL), MK1.3 (GND), R8.2; also elsewhere on the board
I2S_MIC_BCLK: R9.2; also elsewhere on the board
I2S_MIC_DATA: R8.1, R11.2; also elsewhere on the board
I2S_MIC_WS: R10.2; also elsewhere on the board
unnamed: MK1.4 (BCLK), R9.1
unnamed: MK1.6 (DATA), R11.1
unnamed: MK1.1 (WS), R10.1

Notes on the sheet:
I2S MEMS microphone (SPH0645LM4H-B)
At MK1 VDD (pin 5)
SELECT (pin 2) to GND = left channel. R9/R10 (33 Ω) at U1, R11 at MK1: optional damping; use 0 Ω if removed. R8 100k on I2S_MIC_DATA to GND. C11 100 pF C0G is DNP (do not fit). Use the stock symbol/footprint (Sensor_Audio). Footprint has the sound hole; GND ring around it. Mic mute is software only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

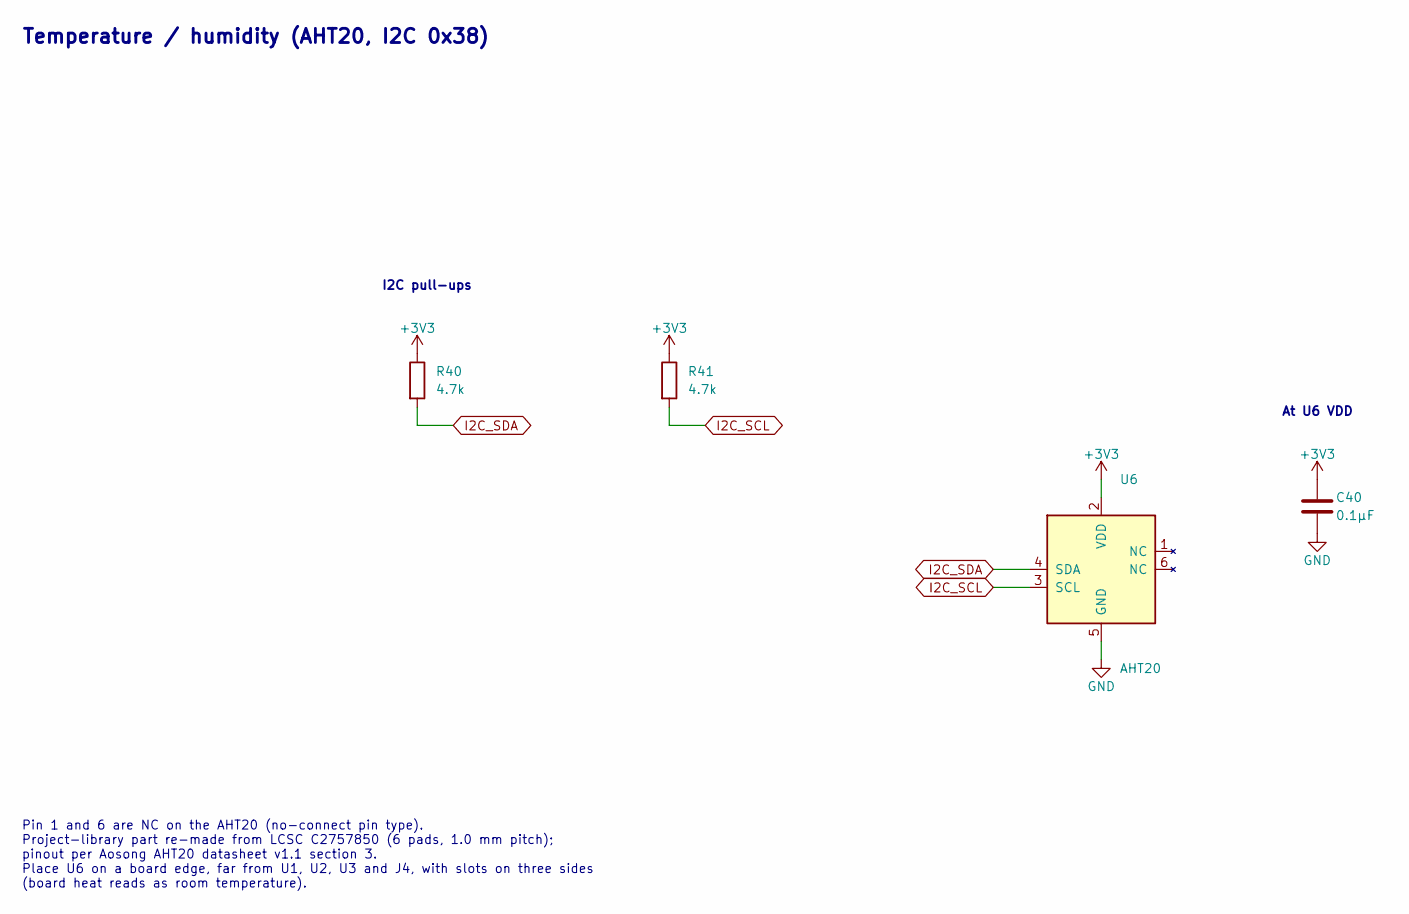
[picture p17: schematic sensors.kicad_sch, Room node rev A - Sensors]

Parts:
C40: 0.1µF; C_0603_1608Metric; LCSC C14663
R40, R41: 4.7k; R_0603_1608Metric; LCSC C23162
U6: AHT20; MPN Aosong AHT20; LCSC C2757850

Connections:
+3V3: C40.1, R40.1, R41.1, U6.2 (VDD); also elsewhere on the board
GND: C40.2, U6.5 (GND); also elsewhere on the board
I2C_SCL: R41.2, U6.3 (SCL); also elsewhere on the board
I2C_SDA: R40.2, U6.4 (SDA); also elsewhere on the board

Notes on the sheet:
Temperature / humidity (AHT20, I2C 0x38)
At U6 VDD
I2C pull-ups
Pin 1 and 6 are NC on the AHT20 (no-connect pin type). Project-library part re-made from LCSC C2757850 (6 pads, 1.0 mm pitch); pinout per Aosong AHT20 datasheet v1.1 section 3. Place U6 on a board edge, far from U1, U2, U3 and J4, with slots on three sides (board heat reads as room temperature).

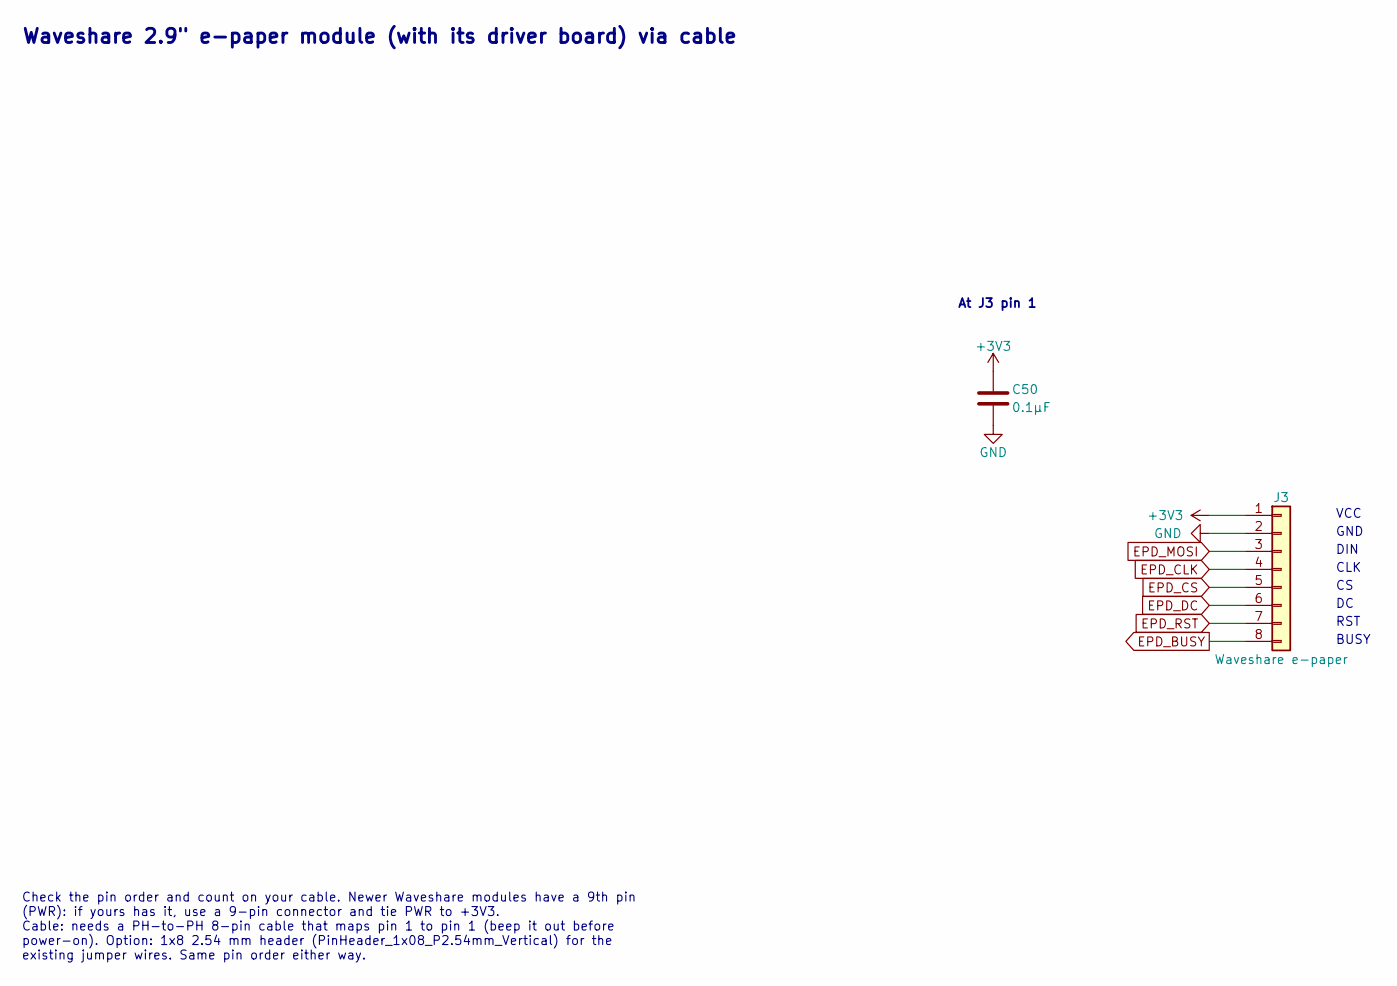
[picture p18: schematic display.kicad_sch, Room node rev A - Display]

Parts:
C50: 0.1µF; C_0603_1608Metric; LCSC C14663
J3: Waveshare e-paper; JST_PH_S8B-PH-SM4-TB_1x08-1MP_P2.00mm_Horizontal; MPN JST S8B-PH-SM4-TB(LF)(SN); LCSC C265121

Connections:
+3V3: C50.1, J3.1; also elsewhere on the board
EPD_BUSY: J3.8; also elsewhere on the board
EPD_CLK: J3.4; also elsewhere on the board
EPD_CS: J3.5; also elsewhere on the board
EPD_DC: J3.6; also elsewhere on the board
EPD_MOSI: J3.3; also elsewhere on the board
EPD_RST: J3.7; also elsewhere on the board
GND: C50.2, J3.2; also elsewhere on the board

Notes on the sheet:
Waveshare 2.9" e-paper module (with its driver board) via cable
VCC
GND
DIN
CLK
RST
BUSY
At J3 pin 1
Check the pin order and count on your cable. Newer Waveshare modules have a 9th pin (PWR): if yours has it, use a 9-pin connector and tie PWR to +3V3. Cable: needs a PH-to-PH 8-pin cable that maps pin 1 to pin 1 (beep it out before power-on). Option: 1x8 2.54 mm header (PinHeader_1x08_P2.54mm_Verti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

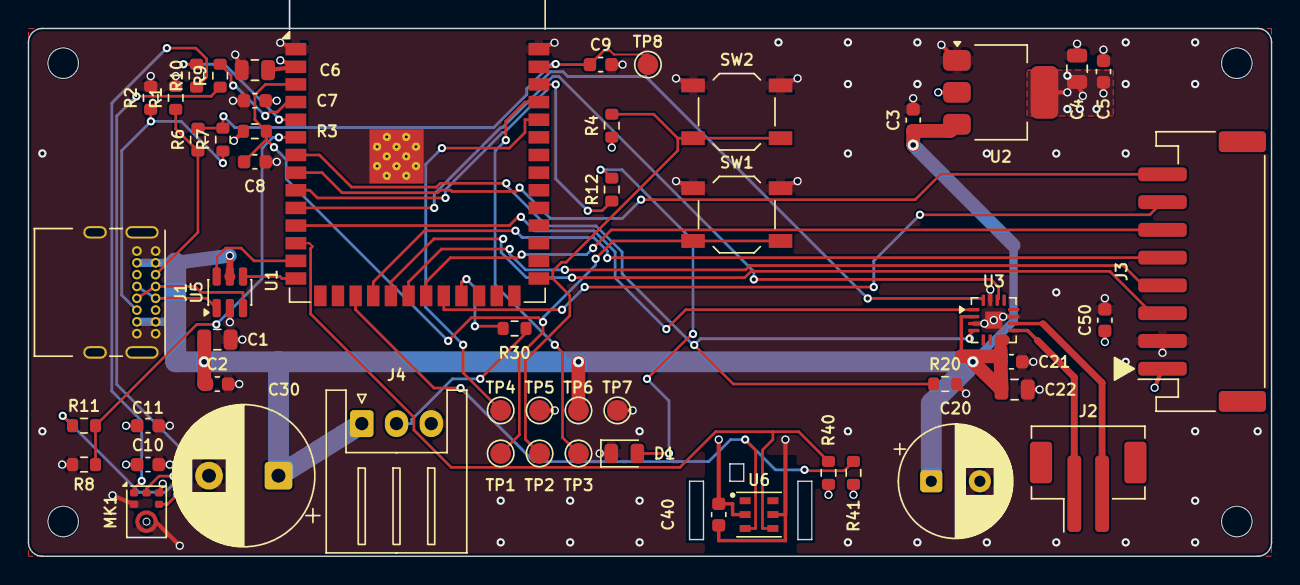
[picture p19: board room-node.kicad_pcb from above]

Board: 4 copper layers, 89.5 x 38.0 mm, 57 parts (0 on the bottom side), 38 nets.

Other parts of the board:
H1, H2, H3, H4: M2; MountingHole_2.2mm_M2

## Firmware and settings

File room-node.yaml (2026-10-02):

substitutions:
  name: room-node
  friendly_name: "Jarvis Room Node"
  # WS2812B status ring — NOT yet wired. When you solder it, set led_pin to the
  # data GPIO you use and led_count to your ring's LED count (GPIO21 is free/safe).
  led_pin: GPIO21
  led_count: "27"

esphome:
  name: ${name}
  friendly_name: ${friendly_name}

globals:
  - id: mww_pending
    type: bool
    restore_value: false
    initial_value: 'false'

esp32:
  board: esp32-s3-devkitc-1
  variant: ESP32S3
  framework:
    type: esp-idf

# N8R8 module: 8MB octal PSRAM — needed for full-rate audio buffers + wake word
psram:
  mode: octal
  speed: 80MHz

wifi:
  ssid: !secret wifi_ssid
  password: !secret wifi_password
  # Static IP 192.168.1.50 (roomnode.internal) since the 2026-09-04 reflash.
  # Gateway = router; DNS = Pi-hole (.196) with router (.1) as fallback.
  manual_ip:
    static_ip: 192.168.1.50
    gateway: 192.168.1.1
    subnet: 255.255.255.0
    dns1: 192.168.1.196
    dns2: 192.168.1.1
  ap:
    ssid: "${friendly_name} Fallback"
    password: !secret ap_password

ota:
  - platform: esphome
    password: !secret ota_password
    on_begin:
      - micro_wake_word.stop:
      - voice_assistant.stop:

api:
  encryption:
    key: !secret ha_api_key

logger:
  level: DEBUG
  hardware_uart: USB_CDC

i2c:
  sda: GPIO8
  scl: GPIO9
  scan: true

spi:
  clk_pin: GPIO12
  mosi_pin: GPIO11

i2s_audio:
  - id: i2s_mic_bus
    i2s_lrclk_pin: GPIO5
    i2s_bclk_pin: GPIO4
  - id: i2s_spk_bus
    i2s_lrclk_pin: GPIO16
    i2s_bclk_pin: GPIO17

# Mic: Adafruit SPH0645LM4H breakout (3421), replaced the INMP441 2026-09-30.
# Same GPIOs: BCLK->GPIO4, LRCL->GPIO5, DOUT->GPIO6, SEL->GND (left), 3V->3V3.
# SPH0645 sends 18-bit data in a 32-bit slot with a large DC offset, so keep
# bits_per_sample 32bit and correct_dc_offset on.
microphone:
  - platform: i2s_audio
    id: mic
    i2s_audio_id: i2s_mic_bus
    i2s_din_pin: GPIO6
    adc_type: external
    pdm: false
    channel: left
    sample_rate: 16000
    bits_per_sample: 32bit
    correct_dc_offset: true

# Full-rate audio path: media_player (below) decodes FLAC at 48kHz and feeds the
# mixer; the old speaker-mode VA path was hard-capped at 16kHz mono (muffled TTS).
speaker:
  - platform: i2s_audio
    id: spk
    i2s_audio_id: i2s_spk_bus
    i2s_dout_pin: GPIO18
    dac_type: external
    # mono = sample duplicated to both I2S slots, so every MAX98357A channel
    # mode plays at full level. SD is wired to GPIO7 (amp_sd): HIGH during
    # playback = enabled (Left mode at 3V3), LOW when idle = shutdown, which
    # mutes idle hiss/pop. Left mode is fine here because mono duplicates the
    # sample into both slots. GAIN strapped to Vin on the amp = fixed 6 dB.
    channel: mono
    sample_rate: 48000
    bits_per_sample: 16bit
    timeout: never
  - platform: mixer
    id: mixer_spk
    output_speaker: spk
    num_channels: 1
    source_speakers:
      - id: announce_mix
      - id: media_mix
  - platform: resampler
    id: announce_resampled
    output_speaker: announce_mix
  - platform: resampler
    id: media_resampled
    output_speaker: media_mix

media_player:
  - platform: speaker
    id: node_media
    name: "${friendly_name} Media"
    volume_increment: 5%
    announcement_pipeline:
      speaker: announce_resampled
      format: FLAC
      sample_rate: 48000
      num_channels: 1
    media_pipeline:
      speaker: media_resampled
      format: FLAC
      sample_rate: 48000
      num_channels: 1
    # MAX98357A SD pin: only powered while something is actually playing
    on_play:
      - output.turn_on: amp_sd
    on_announcement:
      - output.turn_on: amp_sd
    on_idle:
      - output.turn_off: amp_sd

output:
  - platform: gpio
    id: amp_sd
    pin: GPIO7

# Software mute affects the shared mic source used by wake-word and VA capture.
# The switch restores its last state after reboot; no GPIO or physical switch.
switch:
  - platform: template
    id: mic_muted
    name: "Mic muted"
    optimistic: true
    restore_mode: RESTORE_DEFAULT_OFF
    turn_on_action:
      - lambda: 'id(mww_pending) = false;'
      - micro_wake_word.stop:
      - voice_assistant.stop:
      - microphone.mute: mic
      - light.turn_on:
          id: ring
          effect: "None"
          red: 12%
          green: 0%
          blue: 0%
    turn_off_action:
      - microphone.unmute: mic
      - light.turn_off: ring
      - if:
          condition:
            api.connected:
          then:
            - micro_wake_word.start:
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

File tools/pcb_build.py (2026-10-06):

#!/usr/bin/env kicadpython
"""Rev A board build: outline, holes, parts, nets, planes, placement, routing import.

The board mounts behind the Waveshare 2.9" e-paper module (89.5 x 38 mm, 4 x M2 holes
2.5 mm in from each corner). Same outline and hole pattern, M2 standoffs between them.

Usage (from the repo root):
    kicadpython tools/pcb_build.py place  out.dsn   # new board + placement + planes, export DSN
    (route out.dsn with Freerouting -> out.ses)
    kicadpython tools/pcb_build.py route  out.ses   # import routes, GND fills, stitching, fill

`place` overwrites kicad/room-node/room-node.kicad_pcb (all layout work is lost).
Footprints are linked to their schematic symbols, so F8 later updates them in place.
"""
import math, os, subprocess, sys, tempfile
import xml.etree.ElementTree as ET
import pcbnew
from pcbnew import FromMM as mm, ToMM as T, VECTOR2I

ROOT = os.path.dirname(os.path.dirname(os.path.abspath(__file__)))
PRJ = os.path.join(ROOT, 'kicad/room-node')
SCH = os.path.join(PRJ, 'room-node.kicad_sch')
PCB = os.path.join(PRJ, 'room-node.kicad_pcb')
LIBS = {'room-node': os.path.join(PRJ, 'lib/footprints/room-node.pretty')}
STOCK = os.environ.get('KICAD_FOOTPRINTS', '/usr/share/kicad/footprints')

# Board = Waveshare 2.9" e-paper module outline (Waveshare drawing, 89.50 x 38.00 mm).
X0, Y0, W, H = 100.0, 100.0, 89.5, 38.0
X1, Y1 = X0 + W, Y0 + H
CORNER_R = 1.0
HOLE_INSET = 2.5          # hole centres 2.5 mm from each edge -> 84.5 x 33.0 mm pattern

# U1 antenna overhangs the top edge (board edge at the antenna / pad boundary).
# ref -> (x, y, rotation deg)
#
# SQU-35 floorplan: the cables leave at the board edges nearest their targets.
# J1 USB-C and J4 LED stay on the left edge, J3 display moved to the right edge
# (side entry, mouth over the edge). The LDO took the top-right spot the LED
# connector left; the display connector's old spot on the bottom edge is now the
# LED bulk cap C30 / routing channel.
#
# SQU-39 floorplan (Chris did not sign off SQU-35: J4 crowded the left edge under J1
# and the space under U1 was empty). J1 is centred on the left edge, J4 + C30 moved to
# the bottom edge under U1, left of the AHT20 island, and the test pads sit in a row
# between U1 and J4. J3, J2, the LDO and amp clusters and the island are unchanged.
J1_CENTRE_Y = Y0 + H / 2                 # 119.0: centre of J1's pin field and courtyard
J1_DY = J1_CENTRE_Y - 113.5              # +5.5 mm against SQU-35; U5 moves with J1
PLACE = {
    # MCU (centre-left, antenna over the top edge)
    'U1': (128.0, Y0 + 6.75, 0),
    'C6': (116.3, 103.0, 180), 'C7': (116.3, 105.2, 180),      # +3V3 pin 2 (SQU-32)
    'R3': (116.3, 107.4, 0), 'C8': (116.3, 109.6, 0),          # EN pin 3
    'R9': (113.8, 103.4, 90), 'R10': (112.1, 103.4, 90),      # mic BCLK / WS, at U1
    # USB-C, ESD, CC (left edge; J1 centred, SQU-39)
    'J1': None,
    'U5': (114.5, 113.5 + J1_DY, 90),
    'R1': (110.6, 105.0, 90), 'R2': (108.8, 105.0, 90),
    'R6': (112.2, 108.0, 90), 'R7': (114.0, 108.0, 90),
    # USB +5V input caps, under U5 on the +5V spine (via at (112.65, SPINE_Y))
    'C1': (113.6, 122.4, 0), 'C2': (113.6, 125.6, 0),
    # LED strip connector: bottom edge under U1, left of the AHT20 island (SQU-39).
    # Pin 1 (+5V) on the left, towards C30 and J1; the 1000 uF can sits right next to
    # it, + pad facing J4, so the bulk cap is at the connector.
    # SQU-42: side entry (S3B-XH-A), mouth facing the bottom edge. The housing front
    # sits 9.25 mm in front of the pin row: pins at y = 128.45 put it 0.30 mm inside
    # the edge and keep the footprint's silk 0.18 mm off it.
    'J4': (124.0, 128.45, 0), 'C30': (118.0, 132.2, 180),
    # Microphone (bottom-left corner, sound hole through the board; hole unchanged)
    'MK1': (108.5, 134.8, 0),
    'C10': (108.6, 131.4, 0), 'C11': (108.6, 128.6, 0),         # +3V3 at MK1 pin 5
    'R11': (104.0, 128.6, 0), 'R8': (104.0, 131.4, 180),
    # Test pads (SQU-42): the side-entry J4 body fills x 121-132 from y 125.6 down to
    # the edge, so the pads sit in a 2 x 4 block right of it, still clear of the island
    # slot (x = 147.6). TP6 (+5V) is in the top row, so it drops straight onto the spine.
    'TP4': (134.0, 127.5, 0), 'TP5': (136.8, 127.5, 0), 'TP6': (139.6, 127.5, 0),
    'TP7': (142.4, 127.5, 0),
    'TP1': (134.0, 130.6, 0), 'TP2': (136.8, 130.6, 0), 'TP3': (139.6, 130.6, 0),
    'R30': (135.0, 121.6, 0),                                  # LED data, near U1 pin 23
    # Right of U1: CC sense, BOOT/RESET buttons, pull-ups, status LED
    'C9': (141.2, 102.6, 0), 'TP8': (144.6, 102.6, 0),
    'SW2': (151.0, 106.0, 0), 'SW1': (151.0, 113.4, 0),
    'R4': (142.0, 107.0, 90),
    'R12': (142.0, 111.6, 90), 'D1': (142.9, 130.6, 0),
    # Sensor island (bottom edge, slots on three sides)
    'U6': (152.6, 135.0, 0), 'C40': (149.7, 135.0, 270), 'R40': (157.6, 132.0, 90), 'R41': (159.4, 132.0, 90),
    # LDO (top right, in the space the LED connector left; furthest from U6) (SQU-35).
    # The whole U2 / C3 / C4 / C5 group is the reviewed SQU-31 M3 cluster moved as one
    # rigid block by (+58.5, -19.9) mm, so the tab copper area and its vias are unchanged.
    'U2': (170.0, 104.6, 0),
    'C3': (163.7, 106.6, 90), 'C4': (175.5, 102.9, 90), 'C5': (177.4, 103.1, 90),
    # Display connector: right edge, side entry, cable straight out over the edge
    # (SQU-35; pulled 0.10 mm in for a 0.40 mm tab-copper-to-edge margin, SQU-38)
    'J3': (184.5, 117.5, 90), 'C50': (177.5, 121.0, 90),
    # Amplifier + speaker (bottom-right)
    'U3': (169.5, 121.0, 0),
    'C21': (170.775, 124.0, 0), 'C22': (171.0, 126.0, 0), 'R20': (166.0, 125.6, 0),
    'C20': (165.0, 132.6, 0),
    'J2': (176.3, 133.0, 0),
}

# Reference fields the footprint default puts somewhere useless: C30 is turned 180, so
# its label would land below the can, off the bottom edge; the mic cluster is too tight
# for the silk pass to find spots on its own. (x, y[, text angle])
# TP1-TP3: the bottom test-pad row keeps its labels in one line under the pads (SQU-45;
# the silk pass had dropped TP2's 1.9 mm below the others).
REF_AT = {'C30': (118.4, 126.0), 'C11': (108.6, 127.3), 'C10': (108.6, 130.0),
          'MK1': (105.9, 134.8, 90),
          'TP1': (134.0, 132.877), 'TP2': (136.8, 132.877), 'TP3': (139.6, 132.877)}

# AHT20 island: slots (Edge.Cuts) left and right, open at the top for the 4 tracks.
# No copper pour inside, so board heat does not reach the sensor.
ISLAND = (148.6, 130.6, 155.4, Y1)      # x0, y0, x1, y1
SLOT_W = 1.0
SLOTS = [(ISLAND[0] - SLOT_W, ISLAND[1] + 2.0, ISLAND[0], ISLAND[3] - 1.2),   # left
         (ISLAND[2], ISLAND[1] + 2.0, ISLAND[2] + SLOT_W, ISLAND[3] - 1.2)]   # right
# Neck slot (SQU-32 item 5): narrows the 6.80 mm top neck to 5.80 mm. Sits right of
# the +3V3 feed at x = 149.7 and left of the I2C / GND crossings at x >= 152.25.
NECK_SLOT = (150.5, 131.35, 151.5, 132.6)

# In1.Cu (L2) solid GND, In2.Cu (L3) solid +3V3. +5V is a wide track (0.8 mm) from J1
# to the LDO, the amp and the LED connector.

STITCH_PITCH = 5.0
STITCH_INSET = 1.0

# +5V (SQU-39). RISER_X is the inlet from J1's VBUS pads down to the spine (SQU-38):
# with the spine it carries LED + amp + LDO current together, so it is 1.50 mm. 110.60
# leaves 0.345 mm to J1's A-row pads at a 1.50 mm width. SPINE_Y runs east just under
# U1's bottom pad row, 6.6 mm above the AHT20 island (y >= 130.60): it was 2.6 mm
# above it at y = 128.0. The LED leg leaves the spine at the C30 + pad column (led_x),
# and drops to C30 and J4 pin 1 at the bottom edge, 25 mm west of the island.
RISER_X = 110.6
SPINE_Y = 124.0
SPINE_X1 = 168.0

# SQU-31 M3: the LDO tab sits on its own F.Cu +3V3 area, with the plane vias beside
# the tab (not in it, so a weak via tent cannot wick solder off the tab).
# Offsets are measured from the centre of the SOT-223 tab pad.
TAB_AREA = (-1.25, -1.6, 4.95, 1.7)
TAB_VIAS = [(1.65, -1.2, 0.3), (1.65, 0.0, 0.4), (1.65, 1.2, 0.3),
            (2.55, 1.2, 0.3), (3.75, 1.2, 0.3)]

# No signal tracks or vias between the top edge and U1's pin 3 / pin 38 row; see
# place(). Pads and the GND / +3V3 pours are still allowed inside it.
ANTENNA_STRIP = (120.5, Y0, 135.5, 104.6)
# Nothing on the bottom side within this radius of the mic sound hole, so the case
# gasket sits flat (SQU-32 item 4).
MIC_HOLE_CLEAR = 2.5


def netlist():
    out = os.path.join(tempfile.mkdtemp(), 'room-node.xml')
    subprocess.run(['kicad-cli', 'sch', 'export', 'netlist', '--format', 'kicadxml',
                    '-o', out, SCH], check=True, capture_output=True)
    return ET.parse(out).getroot()


def load_fp(fpid):
    lib, name = fpid.split(':', 1)
    path = LIBS.get(lib, os.path.join(STOCK, lib + '.pretty'))
    fp = pcbnew.FootprintLoad(path, name)
    if fp is None:
        sys.exit('footprint not found: ' + fpid)
    fp.SetFPIDAsString(fpid)
    return fp


def courtyard_box(fp):
    sh = fp.GetCourtyard(pcbnew.F_CrtYd)
    return sh.BBox() if sh.OutlineCount() else fp.GetBoundingBox(False)


def line(board, a, b, layer=pcbnew.Edge_Cuts, width=0.1):
    s = pcbnew.PCB_SHAPE(board)
    s.SetShape(pcbnew.SHAPE_T_SEGMENT)
    s.SetStart(VECTOR2I(mm(a[0]), mm(a[1])))
    s.SetEnd(VECTOR2I(mm(b[0]), mm(b[1])))
    s.SetLayer(layer)
    s.SetWidth(mm(width))
    board.Add(s)


def arc(board, center, start, angle_deg):
    s = pcbnew.PCB_SHAPE(board)
    s.SetShape(pcbnew.SHAPE_T_ARC)
    s.SetCenter(VECTOR2I(mm(center[0]), mm(center[1])))
    s.SetStart(VECTOR2I(mm(start[0]), mm(start[1])))
    s.SetArcAngleAndEnd(pcbnew.EDA_ANGLE(angle_deg, pcbnew.DEGREES_T), True)
    s.SetLayer(pcbnew.Edge_Cuts)
    s.SetWidth(mm(0.1))
    board.Add(s)


def outline(board):
    r = CORNER_R
    line(board, (X0 + r, Y0), (X1 - r, Y0))
    line(board, (X1, Y0 + r), (X1, Y1 - r))
    line(board, (X1 - r, Y1), (X0 + r, Y1))
    line(board, (X0, Y1 - r), (X0, Y0 + r))
    arc(board, (X1 - r, Y0 + r), (X1 - r, Y0), 90)
    arc(board, (X1 - r, Y1 - r), (X1, Y1 - r), 90)
    arc(board, (X0 + r, Y1 - r), (X0 + r, Y1), 90)
    arc(board, (X0 + r, Y0 + r), (X0, Y0 + r), 90)


def slot(board, xa, ya, xb, yb):
    """Closed rectangular cut-out on Edge.Cuts (routed slot)."""
    pts = [(xa, ya), (xb, ya), (xb, yb), (xa, yb)]
    for i in range(4):
        line(board, pts[i], pts[(i + 1) % 4])


def zone(board, net, layer, pts, priority, name):
    z = pcbnew.ZONE(board)
    z.SetLayer(layer)
    z.SetNet(net)
    z.SetZoneName(name)
    z.SetAssignedPriority(priority)
    z.SetMinThickness(mm(0.2))
    z.SetLocalClearance(mm(0.25))
    z.SetPadConnection(pcbnew.ZONE_CONNECTION_THERMAL)
    z.SetThermalReliefGap(mm(0.3))
    z.SetThermalReliefSpokeWidth(mm(0.4))
    z.SetIslandRemovalMode(pcbnew.ISLAND_REMOVAL_MODE_ALWAYS)
    o = z.Outline()
    o.NewOutline()
    for x, y in pts:
        o.Append(mm(x), mm(y))
    board.Add(z)
    return z


def keepout(board, pts, name, tracks=False, vias=True, fills=False):
    """Rule area on all copper layers: optionally no pours / tracks / vias."""
    z = pcbnew.ZONE(board)
    z.SetIsRuleArea(True)
    z.SetZoneName(name)
    ls = pcbnew.LSET()
    for l in (pcbnew.F_Cu, pcbnew.In1_Cu, pcbnew.In2_Cu, pcbnew.B_Cu):
        ls.AddLayer(l)
    z.SetLayerSet(ls)
    z.SetDoNotAllowZoneFills(not fills)
    z.SetDoNotAllowTracks(not tracks)
    z.SetDoNotAllowVias(vias)
    z.SetDoNotAllowPads(False)
    z.SetDoNotAllowFootprints(False)
    o = z.Outline()
    o.NewOutline()
    for x, y in pts:
        o.Append(mm(x), mm(y))
    board.Add(z)


def place(dsn):
    root = netlist()
    board = pcbnew.NewBoard(PCB)

    # Stack-up: JLC04161H-7628, 1.6 mm. L2 GND plane, L3 power.
    board.SetCopperLayerCount(4)
    ds = board.GetDesignSettings()
    ds.SetBoardThickness(mm(1.6))
    board.SetLayerType(pcbnew.In1_Cu, pcbnew.LT_POWER)
    board.SetLayerType(pcbnew.In2_Cu, pcbnew.LT_POWER)   # planes only, no signal tracks

    outline(board)
    ix0, iy0, ix1, iy1 = ISLAND
    s = SLOT_W
    for sl in SLOTS + [NECK_SLOT]:
        slot(board, *sl)

    nets = {}
    for n in root.find('nets'):
        name = n.get('name')
        ni = pcbnew.NETINFO_ITEM(board, name)
        board.Add(ni)
        nets[name] = ni
    pin_net = {}
    for n in root.find('nets'):
        for nd in n.findall('node'):
            pin_net[(nd.get('ref'), nd.get('pin'))] = nets.get(n.get('name'))

    for c in root.find('components'):
        ref = c.get('ref')
        fp = load_fp(c.findtext('footprint'))
        fp.SetReference(ref)
        fp.SetValue(c.findtext('value'))
        sp = c.find('sheetpath')
        fp.SetPath(pcbnew.KIID_PATH(sp.get('tstamps') + c.findtext('tstamps')))
        fp.SetSheetname(sp.get('names'))
        sf = c.find('property[@name="Sheetfile"]')
        fp.SetSheetfile(sf.get('value') if sf is not None else '')
        for fl in c.find('fields'):
            if fl.get('name') != 'Footprint':
                fp.SetField(fl.get('name'), fl.text or '')
                fp.GetField(fl.get('name')).SetVisible(False)
        fp.SetDNP(c.find('property[@name="dnp"]') is not None)
        fp.SetExcludedFromBOM(False)
        board.Add(fp)
        for pad in fp.Pads():
            ni = pin_net.get((ref, pad.GetNumber()))
            if ni is not None:
                pad.SetNet(ni)
        if ref not in PLACE:
            sys.exit('no placement for ' + ref)
        if PLACE[ref]:
            x, y, rot = PLACE[ref]
            fp.SetOrientationDegrees(rot)
            fp.SetPosition(VECTOR2I(mm(x), mm(y)))
        # Small, readable reference text
        rf = fp.Reference()
        rf.SetTextSize(VECTOR2I(mm(0.8), mm(0.8)))
        rf.SetTextThickness(mm(0.15))
        if ref in REF_AT:
            rf.SetPosition(VECTOR2I(mm(REF_AT[ref][0]), mm(REF_AT[ref][1])))
            if len(REF_AT[ref]) > 2:
                rf.SetTextAngleDegrees(REF_AT[ref][2])

    # J1 GND pins: solid to the pours (thermal spokes are blocked by the VBUS loop)
    for p in board.FindFootprintByReference('J1').Pads():
        if p.GetNetname() == 'GND':
            p.SetLocalZoneConnection(pcbnew.ZONE_CONNECTION_FULL)

    # USB-C: opening faces left, front of the courtyard flush with the left edge.
    j1 = board.FindFootprintByReference('J1')
    j1.SetOrientationDegrees(270)
    j1.SetPosition(VECTOR2I(0, 0))
    bb = courtyard_box(j1)
    j1.SetPosition(VECTOR2I(mm(X0) - bb.GetLeft(), mm(J1_CENTRE_Y) - bb.GetCenter().y))

    # Mounting holes: M2, on the e-paper module's hole pattern. Board-only.
    for i, (x, y) in enumerate([(X0 + HOLE_INSET, Y0 + HOLE_INSET), (X1 - HOLE_INSET, Y0 + HOLE_INSET),
                                (X0 + HOLE_INSET, Y1 - HOLE_INSET), (X1 - HOLE_INSET, Y1 - HOLE_INSET)], 1):
        h = load_fp('MountingHole:MountingHole_2.2mm_M2')
        h.SetReference('H%d' % i)
        h.SetValue('M2')
        h.SetBoardOnly(True)
        h.Reference().SetVisible(False)   # nothing to identify at assembly; saves silk
        h.SetPosition(VECTOR2I(mm(x), mm(y)))
        board.Add(h)

    # Planes on the inner layers (used by the router as plane nets)
    full = [(X0, Y0), (X1, Y0), (X1, Y1), (X0, Y1)]
    zone(board, nets['GND'], pcbnew.In1_Cu, full, 0, 'GND plane L2')
    zone(board, nets['+3V3'], pcbnew.In2_Cu, full, 0, '+3V3 plane L3')

    # Slots: no copper within 0.35 mm (edge clearance 0.3 mm)
    m = 0.35
    for xa, ya, xb, yb in SLOTS + [NECK_SLOT]:
        keepout(board, [(xa - m, ya - m), (xb + m, ya - m), (xb + m, yb + m), (xa - m, yb + m)], 'slot')
    # Sensor island: no pours, no vias (tracks allowed)
    keepout(board, [(ix0, iy0), (ix1, iy0), (ix1, iy1), (ix0, iy1)], 'AHT20 island', tracks=True)
    # Antenna end of the module: no signal tracks and no vias in the 4.6 mm strip
    # between the top board edge and U1's pin 3 / 38 row. The pours stay (L2 must not
    # be slotted); the strip only stops the router using it as a shortcut, which is
    # what SQU-31/SQU-32 had to undo by hand for CC_SENSE.
    ax0, ay0, ax1, ay1 = ANTENNA_STRIP
    za = pcbnew.ZONE(board)
    za.SetIsRuleArea(True)
    za.SetZoneName('U1 antenna end')
    ls = pcbnew.LSET()
    for l in (pcbnew.F_Cu, pcbnew.In1_Cu, pcbnew.In2_Cu, pcbnew.B_Cu):
        ls.AddLayer(l)
    za.SetLayerSet(ls)
    za.SetDoNotAllowZoneFills(False)
    za.SetDoNotAllowTracks(True)
    za.SetDoNotAllowVias(True)
    za.SetDoNotAllowPads(False)
    za.SetDoNotAllowFootprints(False)
    o = za.Outline()
    o.NewOutline()
    for x, y in [(ax0, ay0), (ax1, ay0), (ax1, ay1), (ax0, ay1)]:
        o.Append(mm(x), mm(y))
    board.Add(za)
    # Mic sound hole: nothing on any layer inside the GND ring except the mic pads
    mk = board.FindFootprintByReference('MK1')
    hole = [p for p in mk.Pads() if p.GetNumber() == ''][0].GetPosition()
    r = 0.4
    ring = lambda rad: [(hole.x / 1e6 + rad * math.cos(a * math.pi / 8),
                         hole.y / 1e6 + rad * math.sin(a * math.pi / 8)) for a in range(16)]
    keepout(board, ring(r), 'MK1 sound hole', tracks=False)
    # Wider via-only ring: a via inside it would stop the case gasket sitting flat on
    # the bottom side (SQU-32 item 4). Tracks and the pours are still allowed.
    keepout(board, ring(MIC_HOLE_CLEAR), 'MK1 gasket seat', tracks=True, vias=True, fills=True)

    prerouted = preroute(board, nets)
    nfan, missed = fanout(board, nets)
    # J3 is a side-entry housing: pin 1 is hidden under it, so mark it on the silk.
    tip = pin1_mark(board, 'J3', '1', 0.3)
    print('pre-routed %d tracks; fan-out vias: %d; pads without via: %s'
          % (prerouted, nfan, ', '.join(missed) or 'none'))
    print('J3 pin 1 silk mark tip at (%.2f, %.2f)' % tip)

    board.BuildConnectivity()
    pcbnew.SaveBoard(PCB, board, True)
    board = pcbnew.LoadBoard(PCB)
    if not pcbnew.ExportSpecctraDSN(board, dsn):
        sys.exit('DSN export failed')
    router_rules(dsn)
    print('saved %s: %d footprints, %d nets; DSN -> %s'
          % (os.path.relpath(PCB, ROOT), len(board.GetFootprints()), len(nets), dsn))


def track(board, net, layer, pts, width):
    for a, b in zip(pts, pts[1:]):
        t = pcbnew.PCB_TRACK(board)
        t.SetStart(VECTOR2I(mm(a[0]), mm(a[1])) if isinstance(a[0], float) else a)
        t.SetEnd(VECTOR2I(mm(b[0]), mm(b[1])) if isinstance(b[0], float) else b)
        t.SetLayer(layer)
        t.SetWidth(mm(width))
        t.SetNet(net)
        board.Add(t)
    return len(pts) - 1


def via(board, net, pos, w=0.6, d=0.3):
    v = pcbnew.PCB_VIA(board)
    v.SetPosition(pos)
    v.SetWidth(mm(w))
    v.SetDrill(mm(d))
    v.SetNet(net)
    board.Add(v)
    return v
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

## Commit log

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2026-07-23 Working voice node: wake word, voice pipeline, LED ring, docs + product plan
    - room-node.yaml: full voice_assistant + micro_wake_word state machine,
    27-px WS2812B status ring (listening/thinking/speaking effects),
    far-field mic tuning, static IP, portable gfonts:// font
    - HARDWARE.md: BOM, GPIO map, power, enclosure/acoustics, CE32A-8 speaker
    - PRODUCT_PLAN.md: breadboard -> KiCad -> manufacture roadmap
    - README rewrite for public repo; secrets.yaml.example added
    - Archive outdated ROOM_NODE.md (wrong pin map) to docs/archive
    [room-node.yaml]
2026-07-28 Phase 0: close out breadboard audio chain
    Audio crackle fixed and verified clean on real-world voice + repeated
    announcements (no clip/underrun in logs):
    - volume_multiplier 2.0 -> 1.0 (2.0 clipped int16 TTS peaks)
    - MAX98357A GAIN strapped to Vin = fixed 6 dB (was floating 9 dB + noise)
    - 470-1000 uF + 0.1 uF decoupling across amp Vin<->GND at the chip
    - star ground: amp GND and LED-strip GND return separately, never shared
    - SD wired to GPIO7 -> idle mute now active (kills between-reply hiss/pop)
    HARDWARE.md synced: 6 dB strap, audio decoupling values, star-ground
    topology, 27-px ring is the deliberate display-perimeter count (full-white
    ~1.6 A > USB budget -> PCB power-tree constraint).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
    [room-node.yaml]
2026-07-28 Phase 0 complete: log power-tree decision, close checklist
    Measured whole-node current on bench supply: ~0.31 A (blue-breathing)
    and ~1.0 A (solid-white 100%) -> USB-C 5 V power tree is sufficient, no
    dedicated LED supply. WS2812B bulk cap + DIN resistor kept as PCB
    footprints (validated unneeded on a stiff bench supply / short strip).
    Phase 0 exit criteria checked off: audio chain, voice test, repo commit,
    LED count (27 px deliberate). Only wake-word range/false-trigger
    characterization remains (partial). Next: Phase 2 KiCad schematic.
2026-07-28 Phase 2: start rev-A schematic architecture
    Foundation for the KiCad schematic: system block diagram, full power tree
    (with Phase 0 measured currents), strapping-pin-checked master pin map,
    reference-design sources, and draft BOM. Per-block net lists to follow.
2026-07-28 Phase 2: Block 1 (MCU + power + USB) net list
    Visual connection diagram + pin-by-pin net tables for USB-C input, 3V3
    LDO, WROOM-1 module, reset/boot circuits, antenna keep-out, and datasheet
    cross-references. First block of the per-block review loop.
2026-07-28 Refresh current-status for session handoff to workstation
    Make PRODUCT_PLAN self-describing so a fresh session reads current state:
    Phase 0 complete, Phase 2 in progress (schematic docs + Block 1 pending
    review), workflow, and next step (Block 2 audio). Mark resolved issues.
2026-07-28 Block 1: correct pin numbers, N16R8, move VA button off GPIO0
    Verified module pin numbering against the KiCad RF_Module:ESP32-S3-WROOM-1
    symbol: USB_D- = pin 13, USB_D+ = pin 14 (the earlier 30/31 were IO37/IO38).
    - Module is N16R8 (16MB flash / 8MB octal PSRAM), matching the validated
    breadboard part, not N8R8. GPIO35/36/37 are consumed by octal PSRAM.
    - VA button moves GPIO0 -> GPIO38 for the PCB. A user holding a GPIO0-wired
    voice button through a power cycle enters download mode and the node looks
    bricked; unfixable in firmware after fab. GPIO0 stays boot/recovery only.
    - Block 1 gains a full netlist with KiCad symbols, footprints and MPNs.
    - 3V3 rail stays linear (AP7361C-33 in S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
2026-07-28 Add KiCad gitignore rules and commit rev-A project skeleton
    Ignore per-user KiCad state (*.kicad_prl, fp-info-cache, lock files),
    autosaves and -backups/ dirs, regenerable netlist exports, and fab output.
    Also ignore *.bak.* so ESPHome config backups stop showing as noise.
    Commits the empty KiCad project as a baseline so schematic work has a
    tracked starting point.
    [esphome.kicad_pcb, esphome.kicad_sch]
2026-07-28 Rename KiCad project to room-node; drop stale root ROOM_NODE.md
    The project was named "esphome", which is the firmware framework rather than
    the board — misleading in a repo whose firmware lives at the root. Renamed to
    room-node to match the repo and room-node.yaml. Working name only; the product
    name is still undecided (see PRODUCT_PLAN.md Phase 5 trademark item).
    Root ROOM_NODE.md was an untracked byte-identical duplicate of
    docs/archive/ROOM_NODE.md, carrying the superseded pin map the docs explicitly
    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
    [room-node.kicad_pcb, room-node.kicad_sch]
2026-07-28 Decide rev A is hand-built; log Phase 2 design decisions
    Rev A is assembled by hand rather than JLCPCB PCBA. Cost is close and the ~1
    week lead time is tolerable; the reason is that rev A is a bring-up board for
    our own house whose job is to be wrong in informative ways. Bench rework beats
    assembly polish, hand-building removes any dependency on JLCPCB part stock, and
    it teaches the DFM lessons the Phase 4 pilot needs. PCBA returns at the pilot.
    Constrains the design: 4-layer with a solid ground plane, ENIG, stencil ordered
    with the boards, single-sided placement, >=0.5mm passive spacing, 0603 minimum,
    through-hole audio bulk cap, tented thermal vias, windowpaned stencil apertures
    on expose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
    [room-node.kicad_sch]
2026-09-24 Add KiCad sub-sheets, connectivity list, block-1 diagram
    Six hierarchical sheets for rev A, the cross-block connectivity list,
    and Block 1 doc updates. Vendor datasheet PDFs are gitignored (public
    repo, vendor copyright); docs/datasheets/README.md indexes them.
    [audio_out.kicad_sch, display.kicad_sch, led_ring.kicad_sch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]
2026-09-25 Fix repo texts to match Decisions log; record 2026-09-25 decisions
    Align self-conflicting repo texts with PRODUCT_PLAN Decisions log:
    - HARDWARE.md: full-white whole-node ~1.0 A measured (USB-C 5 V), not 1.6 A / 500 mA USB budget; 74AHCT125 level shifter is part of the design.
    - rev-a-architecture.md: 4-layer with solid ground plane instead of "2-layer if routable"; replace "No mic-mute switch in rev A" with Block 7 (physical mic-mute switch + state GPIO, circuit TBD by architect).
    - PRODUCT_PLAN.md: LDO AP7361C-33 (not ME6217/AP2112 class); 27 px deliberate; repo pushed through 0be8b6b; mic-mute switch added to Phase 2 schematic list; review gate (second independent review + Chris sign-off)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
2026-09-28 Add ERC report for mcu.kicad_sch (SQU-13)
    kicad-cli 10.0.6 sch erc --severity-all on kicad/room-node/mcu.kicad_sch
    at cd5dc4d: 76 items (51 errors, 25 warnings). Triage lives in the
    erc-triage document on SQU-13; no schematic files changed.
2026-09-28 SQU-14: Add Rev A BOM sourcing data + project library for ICS-43434 and AHT20
    - BOM CSV with LCSC part numbers, JLC class, estimated pricing, stock, lifecycle
    - KiCad project symbol library (room-node-lib): ICS-43434, AHT20 symbols
    - KiCad project footprint library: ICS-43434 (LGA-6), AHT20 (LGA-4) footprints
    - Project sym-lib-table and fp-lib-table for KiCad library resolution
    - Documents lifecycle alert: INMP441 obsolete, recommend ICS-43434
    - Note: LCSC live data inaccessible (JS SPA); prices are estimates
    [rev-a-bom-lcsc.csv]
2026-09-28 SQU-14: Replace INMP441/ICS-43434 with SPH0645LM4H; fix U2 ER note, J201 footprint
    - Replace INMP441 (OBSOLETE) and ICS-43434 with Knowles SPH0645LM4H
    - Add SPH0645LM4H symbol + footprint to project library (bottom-port LGA-6)
    - Add MPN and LCSC fields to symbols for Chris to apply
    - Add ER-suffix-only note for AP7361C-33ER-13 (SOT-223R pinout critical)
    - Fix J201 footprint reference to correct KiCad stock name
    - Update all source docs (HARDWARE.md, rev-a-architecture.md,
    connectivity-list.md, block-1-mcu-power-usb.md)
    - Update BOM CSV with SPH0645LM4H, AP7361C-33ER-13 ER note
    Closes SQU-14
    Generated by Nora / Squarewave Labs via Claude Code
    [rev-a-bom-lcsc.csv]
2026-09-28 Rev A docs: SPH0645 mic, GPIO1 CC sensing, inrush hot-plug test
    Chris's 2026-09-28 decisions D1-D3 (SQU-2 room-node-plan v5 section 5), SQU-15.
    - Mic -> Knowles SPH0645LM4H: Block 3 net list (SEL->GND left, 0.1 uF +
    DNP 100 pF at VDD, 100k DATA pull-down, 33R damping), bottom-port
    acoustic hole, placement, hand-assembly rules. Flags that distributors
    list SPH0645LM4H as obsolete too.
    - USB-C CC sensing on GPIO1: CC1/CC2 summed through 2x100k onto one ADC1
    pin + 100 nF + TP8. Thresholds checked against Type-C R2.0 Table 4-36.
    No second ADC pin needed.
    - Inrush accepted: laptop hot-plug x10 bring-up step; Decisions log says
    rev B adds a soft-start switch if it fails.
    - Free-GPIO l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
2026-09-28 Add v1 product direction + selectable wake word; drop 74AHCT125 from rev A (D4)
    - PRODUCT_PLAN.md: add Product direction block (2026-09-25) - v1 is
    HA-only via native API, intelligence connects behind HA later via the
    Assist conversation agent, users select the wake word (default
    "Hey Jarvis" / hey_jarvis), focus is hardware (rev A) + prototype sync.
    - PRODUCT_PLAN.md Phase 1: add selectable wake word firmware item.
    - PRODUCT_PLAN.md: record 2026-09-25 product direction and 2026-09-28 D4
    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
2026-09-30 Correct room node static IP to 192.168.1.50
    [room-node.yaml]
2026-09-30 Rev A: design physical mic-mute switch (Block 7, SQU-10)
    DPDT slide switch SW4 (C&K JS202011AQN, LCSC C221662):
    - pole A breaks the mic DATA line; in MUTE the ESP side (GPIO6) is held
    at GND through 1 kOhm, so no mic data can reach the ESP32 whatever the
    firmware does
    - pole B reports the state on MIC_MUTE_N -> GPIO2 (module pin 38),
    LOW = muted, 10k pull-up + 100n debounce + 1k series
    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
2026-09-30 SQU-19: Fix CSV quoting, add PR #5 parts, update MK1 lifecycle
    - Quote all multi-reference cells (SW1-SW3, R1,R2, R3-R5, C5,C7) so
    CSV parsers see the correct column count.
    - Add PR #5 parts to BOM: R6,R7 (C25803, 100kΩ 1%), C9 (C30722,
    0.1µF), TP8 (test pad), R8 (C25803), R9-R11 (33Ω, TBD),
    C10 (C30722), C11 (100pF C0G, TBD).
    - Update MK1 lifecycle from 'Active' to 'Transitioned' with source
    notes: Knowles EOL, Syntiant active per DigiKey/Mouser 2026-09-30.
    - U4 (74AHCT125) confirmed absent per D4 — no changes needed.
    - Add sourcing notes doc with lifecycle research and open questions.
    [rev-a-bom-lcsc.csv]
2026-09-30 SQU-19: Pad short BOM rows to 11 columns (empty Notes)
    [rev-a-bom-lcsc.csv]
2026-09-30 SQU-21: BOM LCSC# confirmations and PR #9 mute parts
    - R9-R11 33Ω: confirmed C105881 (YAGEO RC0603FR-07330RL, 33Ω 1%)
    - C11 100pF C0G 50V: TBD, noted search constraints
    - SW4: C221662 (C&K JS202011AQN, DPDT slide switch)
    - R12/R14 1kΩ: C211904 (Uniroyal 0603WAF1001T5E)
    - R13 10kΩ: C25804 (same as R3-R5)
    - C12 100nF: C30722 (same as C2/C5/C7)
    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
    [rev-a-bom-lcsc.csv]
2026-09-30 SQU-22: Fix 12 wrong LCSC numbers in rev A BOM
    Fix errors found when checking every LCSC# against JLCPCB API.
    LCSC# corrections by API verification (2026-09-30):
    R1,R2: C25919 → C23186 (5.1k 0603 1%, was 7.68k 0402)
    R9-R11: C105881 → C23140 (33Ω 0603, was 330Ω)
    R12,R14: C211904 → C21190 (1k 0603, was TE housing)
    R_i2c: C25920 → C23162 (4.7k 0603, was 7.87k 0402)
    R_led: C25727/8 → C23179 (470Ω 0603, was not found)
    C2/C5/C7/C9/C10/C12/C_amp_cer: C30722 → C14663 (100nF X7R, was not found)
    C3,C8: C15850 → C15849 (1µF 0603, was 10µF 0805)
    C1: C169506 → C15850 (10µF 0805, was bridge rectifier)
    C4,C6: C54614 → C45783 (22µF 0805, was L7812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
    [rev-a-bom-lcsc.csv]
2026-09-30 SQU-25: Drop Block 7 mute rows (SW4, R12-R14, R13, C12)
    Per SQU-17 decision: no physical mute switch. Mute is software only.
    Removes the 4 Block 7 - Mic Mute rows from rev-a-bom-lcsc.csv while
    preserving all SQU-22 LCSC fixes.
    [rev-a-bom-lcsc.csv]
2026-09-30 SQU-24: Remove Block 7 hardware mic-mute (SW4) from rev A docs
    Chris decided 2026-09-30 (SQU-17): no physical mute switch; mic mute
    is software only. Reverts the Block 7 design added in PR #9:
    - rev-a-architecture.md: drop Block 7 (SW4, R12-R14, C12, MIC_MUTE_N),
    mic DATA back to MK1 -> R11 33R -> GPIO6 with R8 100k pull-down,
    mic VDD straight from +3V3, GPIO2 back on the free list, add the
    decision note.
    - connectivity-list.md: drop Block 7 rows, I2S_MIC_DATA_SW -> I2S_MIC_DATA,
    MIC_VDD -> +3V3, update free-GPIO list.
    - block-1, HARDWARE.md, PRODUCT_PLAN.md: same GPIO2 / mute updates,
    plus a 2026-09-30 Decisions-log entry.
    BOM CSV and KiCad files untouched.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
2026-10-01 SQU-17: Clean up repo docs; add rev A pinout and schematic
    Replace 10 overlapping docs (~3100 lines) with a short set:
    - docs/pcb/pinout.md: module pin -> GPIO -> net table
    - docs/pcb/schematic.md: every KiCad sheet, parts and connections
    - docs/pcb/layout.md, docs/breadboard.md, docs/enclosure.md
    - README.md shortened
    Removed HARDWARE.md, PRODUCT_PLAN.md, docs/schematic/*, docs/archive,
    docs/datasheets, stale ERC report, BOM follow-up notes. History keeps them.
2026-10-01 SQU-26: Fix AHT20 pinout, MCU sheet status, J3 cable note
    - AHT20: real part is DFN-6 (1 NC, 2 VDD, 3 SCL, 4 SDA, 5 GND, 6 NC).
    Project-library 4-pin part is unsafe; re-import from LCSC C2757850.
    - MCU sheet status: list netlist wiring errors (LDO caps in series,
    EN/IO0/IO38 parts off-net, GPIO40/41 on GND, net names).
    - Amp: EP is symbol pin 17; note internal SD_MODE pull-down.
    - Display: Waveshare cable is PH-to-jumper; note PH-PH or 2.54 header.
2026-10-01 SQU-27: Draw rev A schematic (6 sheets + root hierarchy)
    - Draw mcu, audio_out, microphone, led_ring, sensors and display sheets
    from docs/pcb/schematic.md: doc refs, values, footprints, MPN and LCSC
    fields. The old MCU sheet (2xx refs, wiring errors) is redrawn.
    - Root sheet now holds the 6 sheets as a normal hierarchy; the project
    no longer lists every file as a KiCad 10 top-level sheet, so project
    ERC and netlist cover all sheets.
    - Project library: replace the wrong 4-pin AHT20 with a 6-pin symbol and
    6-pad footprint from LCSC C2757850 (pin 1 top-left, datasheet v1.1 s3);
    remove the wrong SPH0645 part (stock part is used); fix the library
    header so KiCad can load it (kicad_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
    [audio_out.kicad_sch, display.kicad_sch, led_ring.kicad_sch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]
2026-10-01 SQU-28: Fill LCSC TBDs, add PR #15 rows (C22/R20/C40/C50/J4), fix J3
    Adds rows for new parts from PR #15 (iris/squ-27-rev-a-schematic):
    - C22 (10µF 0805) via C15850, R20 (100kΩ) via C25803 — Iris assumptions confirmed
    - C40, C50 (0.1µF 0603) via C14663
    - J4 (JST-XH 3-pin) via C144394
    Fills LCSC numbers for TBD parts:
    - U1: C2913202 (ESP32-S3-WROOM-1-N16R8)
    - U2: C3743528 (AP7361C-33ER-13)
    - U3: C910544 (MAX98357AETE+T)
    - U5: C7519 (USBLC6-2SC6)
    - J1: C7095263 (USB4085-GF-A)
    - J3: C495548 (B8B-PH-SM4-TB) — changed from FPC 24-pin to JST-PH 8-pin
    - SW1-SW3: C2886898 (TL3342F160QG)
    - U6: C2757850 (AHT20) — confirmed Iris import correct
    MK1 remains TBD (not on LCSC; order from DigiKey/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
    [rev-a-bom-lcsc.csv]
2026-10-02 SQU-29: Add status LED on GPIO2 (D1 + R12)
    - MCU sheet: U1 pin 38 (GPIO2) -> STATUS_LED -> R12 1k -> D1 green LED
    -> GND, active HIGH. Remove the GPIO2 no-connect flag; update the
    U1 note. No change to LED_DIN (no level-shifter pads).
    - D1 is KT-0805G (C2297, JLC Basic). JLC Basic has no green or blue
    0603 LED; 0603 alternate is KT-0603G (C12624, Extended).
    - pinout.md: GPIO2 is now used; drop the optional test pad note; add
    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
    [mcu.kicad_sch, rev-a-bom-lcsc.csv]
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2026-10-02 SQU-17: Status LED steady on while running (light status_led)
    ESPHome's top-level status_led is off when healthy and only blinks on
    warning/error. Chris asked for an LED that is on while firmware runs.
    The status_led light platform gives steady on plus the error blink.
    [room-node.yaml]
2026-10-04 SQU-17: JLCPCB 4-layer design rules and net classes
    Set board design rules (JLC04161H-7628 capabilities with margin), track
    and via presets, and net class widths. Fix net class patterns to match
    real net names (USB_D*, J2 speaker, J4 LED data). Document stack-up and
    the one manual step (copper layers = 4) in docs/pcb/layout.md.
2026-10-04 SQU-17: PCB setup — 4 layers, outline, holes, parts, planes, rough placement
    tools/pcb_setup.py builds the starting board from the schematic netlist:
    4 copper layers (L2 GND, L3 +5V/+3V3), 90x50 mm placeholder outline,
    4x M3 holes, all 55 parts linked to their symbols, GND/power zones,
    edge stitching vias, rough placement by function. U1 antenna overhangs
    the top edge.
    Power net class clearance 0.2 -> 0.15 mm: the USB-C J1 pads are 0.15 mm
    apart, so 0.2 failed DRC inside the footprint.
    DRC: 0 errors except 90 unrouted, 0 schematic-parity issues.
    [room-node.kicad_pcb]
2026-10-04 SQU-17: full rev A board — display-size outline, placement and routing
    Board matches the Waveshare 2.9" e-paper module (89.5 x 38 mm, 4 x M2 on its
    84.5 x 33 mm hole pattern) so it screws behind the display on standoffs.
    All 55 parts placed and every net routed (Freerouting + hand routes for J1 VBUS,
    amp pins and the AHT20 island). L2 GND, L3 +3V3 planes; +5V as a 0.6-1.0 mm
    track. DRC: 0 errors, 0 unconnected, 0 parity issues; 53 silkscreen warnings.
    tools/pcb_build.py replaces tools/pcb_setup.py. Gerbers in reports/fab/.
    [room-node.kicad_pcb]
2026-10-05 SQU-17: remove voice button SW3 + R5 (wake word only)
    Chris: no voice button. U1 pin 31 (GPIO38) gets a no-connect flag.
    Schematic, board (parts, 13 tracks/vias, +3V3 stub), BOM, docs,
    pinout check and pcb_build.py updated. Gerbers, PDF, pictures regenerated.
    ERC: 0 errors, 1 accepted warning. DRC: 0 errors, 0 unconnected,
    0 parity issues, 53 silkscreen warnings. Pinout check: PASS.
    [mcu.kicad_sch, rev-a-bom-lcsc.csv, room-node.kicad_pcb]
2026-10-05 SQU-17: rev A board — apply design review fixes M1–M4 (SQU-31)
    M1 C21 (0.1 uF) and C22 (10 uF) moved from U3 pin 2 (GAIN_SLOT) to the VDD
    pins 7/8: C21 0.7 mm below the pins, C22 under it, each GND pad with its
    own via to L2.
    M2 +5V LED/amp path: no 0.6 mm sections left. J1 -> C1 doubled on F.Cu and
    B.Cu through the USB-C pin row, 1.2 mm round C1; C2 -> C3 1.2 mm; new
    1.5 mm run from TP6 to C20 (replaces the 0.6 mm run along y = 125.8);
    1.0 mm to the amp pins.
    M3 U2 tab on a F.Cu +3V3 copper area (full connection) with 5 vias to the
    L3 plane (the tab had none: fan-out tested the tab width, not its height;
    fixed in pcb_build.py).
    M4 AMP_SD under U1 moved to y = 106.4,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
    [room-node.kicad_pcb]
2026-10-05 SQU-33: LCSC number C265121 for J3 side-entry JST S8B-PH-SM4-TB(LF)(SN)
    Replaced TBD-SQU-32 with C265121 in BOM CSV and KiCad schematic.
    Price at qty 10: /usr/bin/bash.3674 (Extended class, stock 19264, Active).
    [display.kicad_sch, rev-a-bom-lcsc.csv]
2026-10-05 SQU-32: J3 side entry (S8B-PH-SM4-TB) + SQU-31 review polish
    J3 swapped from the top-entry B8B-PH-SM4-TB to the side-entry
    S8B-PH-SM4-TB, mouth facing out over the bottom board edge so the cable
    reaches the display behind the board. Same pinout, pin 1 to pin 1.
    Housing front face 0.52 mm inside the edge, limited by the mounting-tab
    pads (0.32 mm copper to edge). Each pin gets a via at y = 133.90 behind
    the pad row with a 2.4 mm F.Cu stub forward into the pad; the six EPD
    B.Cu drops were re-aimed at that row.
    Review polish from SQU-31:
    - C6 rotated 180 deg, 2.01 mm 0.3 mm F.Cu track to U1 pin 2
    - CC_SENSE cross-module run 102.76 -> 105.90 (2.76 -> 5.90 mm below the
    antenna line)
    - mic hole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
    [room-node.kicad_pcb]
2026-10-05 SQU-35: rev A connectors to the board edges (J3 right, J1 + J4 left)
    Chris's ask: short cables when the board sits behind the display. Each
    connector now leaves the edge nearest what it plugs into. Frame of
    reference as in docs/pcb/layout.md: parts side, USB-C on the left.
    - J1 USB-C unchanged on the left edge, (109.155, 110.525).
    - J4 LED strip -> (103.500, 122.300), left edge directly below J1.
    J1 VBUS pad B4 -> J4 pin 1 is 7.94 mm (was 65.24 mm).
    - C30 1000 uF -> (114.500, 125.800), the next part along the trunk,
    0.21 mm from J4's courtyard. J1 -> C30 pad 1 is 12.18 mm (was 70.23).
    - J3 display -> (184.600, 117.500) rot 90, right edge, side-entry mouth
    over the edge. Mounting-tab c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
    [room-node.kicad_pcb]
2026-10-06 SQU-38: PR #23 review fixes — J3 edge margin, +5V inlet, M3 via drills
    Iris's SQU-37 re-review of PR #23 asked for three geometry fixes and a set
    of record corrections. Freerouting needs Java 25, which is not in the
    container, so the board could not be rebuilt end to end: the three edits are
    applied by the coordinate-exact tools/pcb_squ38.py and the same geometry is
    now in the generator, so the next full rebuild reproduces it.
    1. J3 edge margin. J3 (184.600 -> 184.500, 117.500) rot 90. Mounting-tab
    copper 189.200 -> 189.100 against the routed edge at 189.500: 0.400 mm
    of margin instead of 0.300 mm, which is the DRC limit but not a safe
    milling margin at JLCPCB's +/-0.20 mm routin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
    [room-node.kicad_pcb]
2026-10-06 SQU-39: centre USB-C, LED connector to the bottom edge left of the AHT20
    - J1 centred on the left edge (pin field and courtyard centre y = 119.000); U5 moves
    with it. C1/C2 under U5 on the +5V spine via.
    - J4 to the bottom edge under U1 (124.0, 133.6): 18.81 mm courtyard to U6, 15.60 mm
    to the island slot. C30 at J4, + pad facing pin 1 (6.16 mm).
    - +5V: 1.50 mm riser -> spine at y = 124.0 (5.85 mm above the island box, was 1.85)
    -> C30 -> J4. J1 -> J4 26.08 mm, 2.1 C rise at 1.6 A (IPC-2221).
    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
    [room-node.kicad_pcb]
2026-10-06 SQU-42: J4 LED connector to side entry (S3B-XH-A), cable out of the bottom edge
    - J4 footprint JST_XH_B3B-XH-A vertical -> JST_XH_S3B-XH-A_1x03_P2.50mm_Horizontal
    (JST S3B-XH-A(LF)(SN), LCSC C157928, 3 A), mouth facing the bottom edge.
    Pins at (124.0/126.5/129.0, 128.45); housing front 0.30 mm inside the edge, no
    body overhang; silk 0.18 mm off the edge. Pin order unchanged (1 +5V, 2 DIN, 3 GND).
    - J4 courtyard -> U6 courtyard 18.81 mm, -> island slot 15.60 mm (unchanged).
    C30 stays at J4 (courtyards 0.21 mm, C30+ -> pin 1 7.08 mm).
    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
    [led_ring.kicad_sch, rev-a-bom-lcsc.csv, room-node.kicad_pcb]
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2026-10-06 SQU-45: TP2 label into the test-pad row; bottom-edge separation/assembly proposal
    - TP2 F.Silkscreen reference (136.8, 134.777) -> (136.8, 132.877), in line with TP1/TP3;
    TP1-TP3 pinned in REF_AT so a rebuild keeps the row.
    - docs/pcb/layout.md: edge-clearance table for every edge part, options A/B/C for board
    separation and assembly (proposal: single routed boards, hand assembly, no V-cut),
    production-file check; corrected J4 pad (8.58 mm) and C30 (0.80/0.55 mm) edge figures.
    - Regenerated DRC report, top render and Gerber zip (F.Silkscreen only).
    [room-node.kicad_pcb]
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
